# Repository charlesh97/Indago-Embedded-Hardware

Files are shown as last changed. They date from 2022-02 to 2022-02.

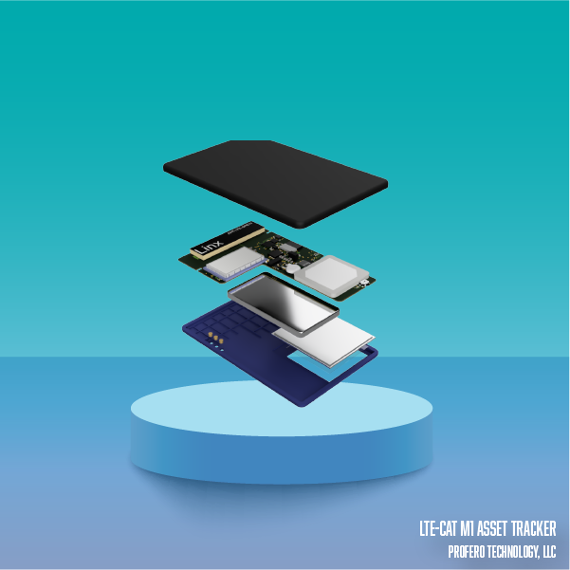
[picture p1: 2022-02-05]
Renderings/AssetTracker_TestProductMockup.png

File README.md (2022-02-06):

# Indago-Embedded-HW

Archived project.

See latest
[PCB](https://gitlab.com/indago-smart-tracker/indago-embedded-hw/-/blob/main/Hardware/v5_Miniature/Main%20Design%20B/Tracker_v5BPCB.pdf),
[Schematic](https://gitlab.com/indago-smart-tracker/indago-embedded-hw/-/blob/main/Hardware/v5_Miniature/Main%20Design%20B/Tracker_v5BSCH.pdf),
[Staged Product Rendering](https://gitlab.com/indago-smart-tracker/indago-embedded-hw/-/blob/main/Renderings/AssetTracker_TestProductMockup.png)

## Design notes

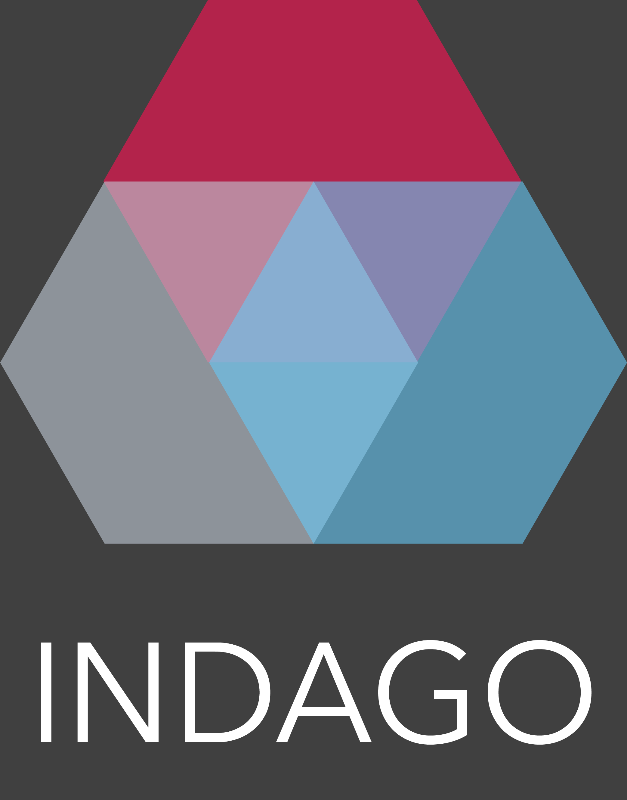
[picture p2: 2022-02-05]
Renderings/Indago_white.png

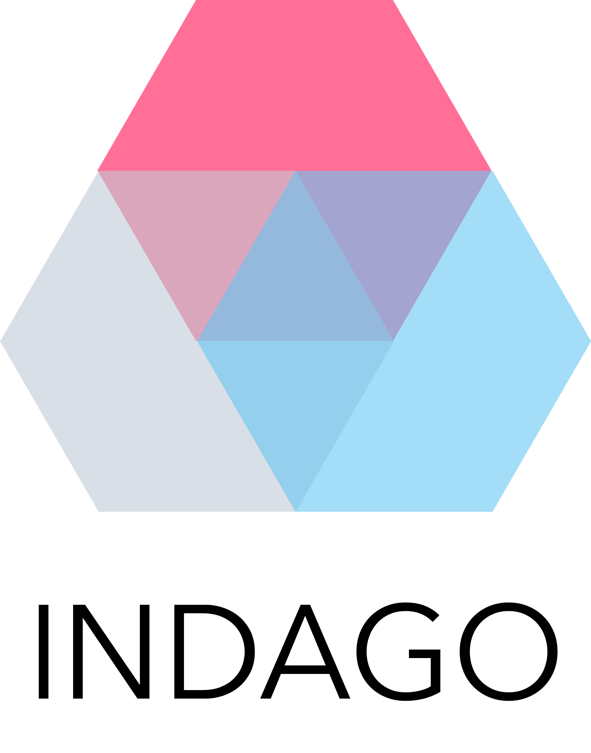
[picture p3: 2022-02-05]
Renderings/Indago.png

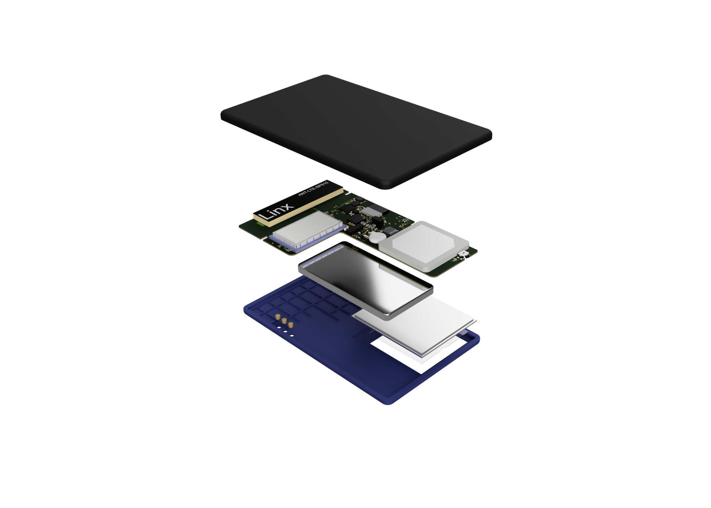
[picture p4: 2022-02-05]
Renderings/Mockup_v1_2020-Nov-24_12-03-38AM-000_CustomizedView8558925261_png_alpha.png

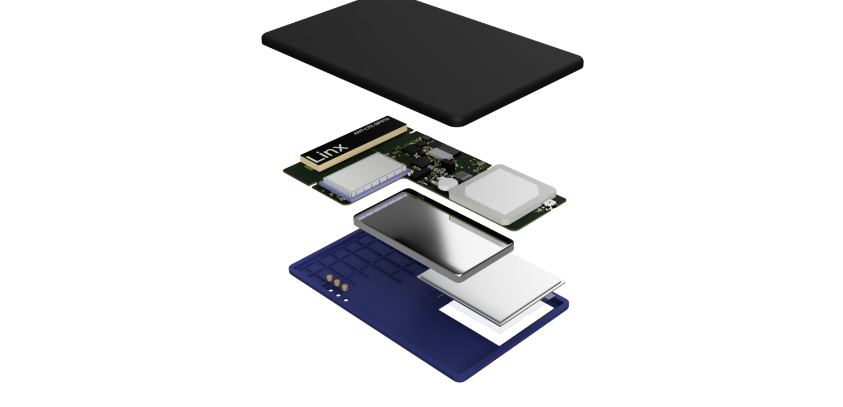
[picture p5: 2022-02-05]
Renderings/Mockup_v1_2020-Jun-15_01-10-26AM-000_CustomizedView8558925261_png_alpha.png

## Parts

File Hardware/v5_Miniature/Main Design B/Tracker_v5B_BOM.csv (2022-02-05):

Qty | Value | Device | Package | Parts | Description | ALTERNATE_PARTNUMBER | APPLICATION_BUILDNUMBER | BOI | BOI-METRIC | BUILT_BY | CATEGORY | COMPTYPE | COPYRIGHT | CREATED_BY | DESCRIPTION | DESIG | DIGI# | DIGI-KEY_PART_NUMBER | DIGI-KEY_PURCHASE_URL | DIGIKEY_PART_NUMBER | FAB | ISP_PART | MANF# | MANUFACTURER | MANUFACTURER_PART_NUMBER | MF | MOUNTTYPE | MP | MPN | OPERATING_TEMP | PACKAGE | PACKAGEREFERENCE | PARTNUMBER | PART_STATUS | PIN_COUNT | POPULARITY | REF | REFDES | ROHS | ROHS_COMPLIANT | SERIES | SOURCELIBRARY | SPICEPREFIX | SUB-CATEGORY | THERMALLOSS | TP_SIGNAL_NAME | TYPE | URL | VALUE | VENDOR | VOLTAGE_RATING
12 | 0.1uF | C-EUC0201 | C0201 | C2, C3, C9, C10, C11, C17, C22, C25, C26, C27, C32, C34 | CAPACITOR, European symbol |  |  |  |  |  |  |  |  |  |  |  |  |  |  |  |  |  |  |  |  |  |  |  |  |  |  |  |  |  |  | 0 |  |  |  |  |  |  | C
1 | 0.47uF | C-EUC0201 | C0201 | C1 | CAPACITOR, European symbol |  |  |  |  |  |  |  |  |  |  |  |  |  |  |  |  |  |  |  |  |  |  |  |  |  |  |  |  |  |  | 0 |  |  |  |  |  |  | C
1 | 0ohm | C-EUC0402 | C0402 | L2 | CAPACITOR, European symbol |  |  |  |  |  |  |  |  |  |  |  |  |  |  |  |  |  |  |  |  |  |  |  |  |  |  |  |  |  |  | 18 |  |  |  |  |  |  | C
1 | 1.8nF | C-EUC0402 | C0402 | C45 | CAPACITOR, European symbol |  |  |  |  |  |  |  |  |  |  |  |  |  |  |  |  |  |  |  |  |  |  |  |  |  |  |  |  |  |  | 18 |  |  |  |  |  |  | C
8 | 100 | R-US_R0201 | R0201 | R6, R7, R8, R9, R12, R13, R16, R17 | RESISTOR, American symbol |  |  |  |  |  |  |  |  |  |  |  |  |  |  |  |  |  |  |  |  |  |  |  |  |  |  |  |  |  |  | 0 |  |  |  |  |  |  | R
7 | 10000pF | C-EUC0201 | C0201 | C13, C21, C29, C30, C31, C33, C35 | CAPACITOR, European symbol |  |  |  |  |  |  |  |  |  |  |  |  |  |  |  |  |  |  |  |  |  |  |  |  |  |  |  |  |  |  | 0 |  |  |  |  |  |  | C
3 | 100k | R-US_R0201 | R0201 | R1, R31, R32 | RESISTOR, American symbol |  |  |  |  |  |  |  |  |  |  |  |  |  |  |  |  |  |  |  |  |  |  |  |  |  |  |  |  |  |  | 0 |  |  |  |  |  |  | R
1 | 100pF | C-EUC0201 | C0201 | C53 | CAPACITOR, European symbol |  |  |  |  |  |  |  |  |  |  |  |  |  |  |  |  |  |  |  |  |  |  |  |  |  |  |  |  |  |  | 0 |  |  |  |  |  |  | C
1 | 100pF | C-EUC0402 | C0402 | C44 | CAPACITOR, European symbol |  |  |  |  |  |  |  |  |  |  |  |  |  |  |  |  |  |  |  |  |  |  |  |  |  |  |  |  |  |  | 18 |  |  |  |  |  |  | C
3 | 10k | R-US_R0201 | R0201 | R2, R33, R37 | RESISTOR, American symbol |  |  |  |  |  |  |  |  |  |  |  |  |  |  |  |  |  |  |  |  |  |  |  |  |  |  |  |  |  |  | 0 |  |  |  |  |  |  | R
2 | 10nF | C-EUC0402 | C0402 | C48, C49 | CAPACITOR, European symbol |  |  |  |  |  |  |  |  |  |  |  |  |  |  |  |  |  |  |  |  |  |  |  |  |  |  |  |  |  |  | 18 |  |  |  |  |  |  | C
2 | 10pF | C-EUC0201 | C0201 | C38, C39 | CAPACITOR, European symbol |  |  |  |  |  |  |  |  |  |  |  |  |  |  |  |  |  |  |  |  |  |  |  |  |  |  |  |  |  |  | 0 |  |  |  |  |  |  | C
1 | 10uF | C-EUC0402 | C0402 | C7 | CAPACITOR, European symbol |  |  |  |  |  |  |  |  |  |  |  |  |  |  |  |  |  |  |  |  |  |  |  |  |  |  |  |  |  |  | 18 |  |  |  |  |  |  | C
1 | 10uF | C-EUC0603 | C0603 | C23 | CAPACITOR, European symbol |  |  |  |  |  |  |  |  |  |  |  |  |  |  |  |  |  |  |  |  |  |  |  |  |  |  |  |  |  |  | 73 |  |  |  |  |  |  | C
2 | 130 | R-US_R0201 | R0201 | R24, R28 | RESISTOR, American symbol |  |  |  |  |  |  |  |  |  |  |  |  |  |  |  |  |  |  |  |  |  |  |  |  |  |  |  |  |  |  | 0 |  |  |  |  |  |  | R
3 | 15pF | C-EUC0201 | C0201 | C19, C36, C37 | CAPACITOR, European symbol |  |  |  |  |  |  |  |  |  |  |  |  |  |  |  |  |  |  |  |  |  |  |  |  |  |  |  |  |  |  | 0 |  |  |  |  |  |  | C
1 | 196ohm | R-US_R0201 | R0201 | R34 | RESISTOR, American symbol |  |  |  |  |  |  |  |  |  |  |  |  |  |  |  |  |  |  |  |  |  |  |  |  |  |  |  |  |  |  | 0 |  |  |  |  |  |  | R
1 | 1k | R-US_R0201 | R0201 | R5 | RESISTOR, American symbol |  |  |  |  |  |  |  |  |  |  |  |  |  |  |  |  |  |  |  |  |  |  |  |  |  |  |  |  |  |  | 0 |  |  |  |  |  |  | R
8 | 1uF | C-EUC0201 | C0201 | C4, C5, C6, C12, C28, C40, C41, C57 | CAPACITOR, European symbol |  |  |  |  |  |  |  |  |  |  |  |  |  |  |  |  |  |  |  |  |  |  |  |  |  |  |  |  |  |  | 0 |  |  |  |  |  |  | C
2 | 2.2uF | C-EUC0402 | C0402 | C55, C56 | CAPACITOR, European symbol |  |  |  |  |  |  |  |  |  |  |  |  |  |  |  |  |  |  |  |  |  |  |  |  |  |  |  |  |  |  | 18 |  |  |  |  |  |  | C
1 | 2.4k | R-US_R0201 | R0201 | R38 | RESISTOR, American symbol |  |  |  |  |  |  |  |  |  |  |  |  |  |  |  |  |  |  |  |  |  |  |  |  |  |  |  |  |  |  | 0 |  |  |  |  |  |  | R
1 | 20k | R-US_R0201 | R0201 | R35 | RESISTOR, American symbol |  |  |  |  |  |  |  |  |  |  |  |  |  |  |  |  |  |  |  |  |  |  |  |  |  |  |  |  |  |  | 0 |  |  |  |  |  |  | R
2 | 22nF | C-EUC0402 | C0402 | C46, C54 | CAPACITOR, European symbol |  |  |  |  |  |  |  |  |  |  |  |  |  |  |  |  |  |  |  |  |  |  |  |  |  |  |  |  |  |  | 18 |  |  |  |  |  |  | C
4 | 29 | R-US_R0201 | R0201 | R18, R19, R22, R23 | RESISTOR, American symbol |  |  |  |  |  |  |  |  |  |  |  |  |  |  |  |  |  |  |  |  |  |  |  |  |  |  |  |  |  |  | 0 |  |  |  |  |  |  | R
1 | 2k | R-US_R0201 | R0201 | R3 | RESISTOR, American symbol |  |  |  |  |  |  |  |  |  |  |  |  |  |  |  |  |  |  |  |  |  |  |  |  |  |  |  |  |  |  | 0 |  |  |  |  |  |  | R
4 | 30 | R-US_R0201 | R0201 | R25, R26, R29, R30 | RESISTOR, American symbol |  |  |  |  |  |  |  |  |  |  |  |  |  |  |  |  |  |  |  |  |  |  |  |  |  |  |  |  |  |  | 0 |  |  |  |  |  |  | R
1 | 330 | R-US_R0201 | R0201 | R4 | RESISTOR, American symbol |  |  |  |  |  |  |  |  |  |  |  |  |  |  |  |  |  |  |  |  |  |  |  |  |  |  |  |  |  |  | 0 |  |  |  |  |  |  | R
2 | 4.7k | R-US_R0201 | R0201 | R14, R15 | RESISTOR, American symbol |  |  |  |  |  |  |  |  |  |  |  |  |  |  |  |  |  |  |  |  |  |  |  |  |  |  |  |  |  |  | 0 |  |  |  |  |  |  | R
2 | 470nF | C-EUC0402 | C0402 | C47, C50 | CAPACITOR, European symbol |  |  |  |  |  |  |  |  |  |  |  |  |  |  |  |  |  |  |  |  |  |  |  |  |  |  |  |  |  |  | 18 |  |  |  |  |  |  | C
1 | 47nF | C-EUC0402 | C0402 | C43 | CAPACITOR, European symbol |  |  |  |  |  |  |  |  |  |  |  |  |  |  |  |  |  |  |  |  |  |  |  |  |  |  |  |  |  |  | 18 |  |  |  |  |  |  | C
4 | 47pF | C-EUC0201 | C0201 | C14, C15, C16, C18 | CAPACITOR, European symbol |  |  |  |  |  |  |  |  |  |  |  |  |  |  |  |  |  |  |  |  |  |  |  |  |  |  |  |  |  |  | 0 |  |  |  |  |  |  | C
2 | 5M | R-US_R0201 | R0201 | R27, R39 | RESISTOR, American symbol |  |  |  |  |  |  |  |  |  |  |  |  |  |  |  |  |  |  |  |  |  |  |  |  |  |  |  |  |  |  | 0 |  |  |  |  |  |  | R
2 | 68nF | C-EUC0402 | C0402 | C8, C42 | CAPACITOR, European symbol |  |  |  |  |  |  |  |  |  |  |  |  |  |  |  |  |  |  |  |  |  |  |  |  |  |  |  |  |  |  | 18 |  |  |  |  |  |  | C
1 | 68pF | C-EUC0201 | C0201 | C20 | CAPACITOR, European symbol |  |  |  |  |  |  |  |  |  |  |  |  |  |  |  |  |  |  |  |  |  |  |  |  |  |  |  |  |  |  | 0 |  |  |  |  |  |  | C
1 | 845ohm | R-US_R0201 | R0201 | R36 | RESISTOR, American symbol |  |  |  |  |  |  |  |  |  |  |  |  |  |  |  |  |  |  |  |  |  |  |  |  |  |  |  |  |  |  | 0 |  |  |  |  |  |  | R
1 | ADP165ACBZ-1.8-R7 | ADP160ACBZ-3.3-R7 | CB_4_1 | U16 | ADP160ACBZ- Linear Voltage Regulator IC Positive Fixed 1 Output 150mA 4-WLCSP (0.97x0.97) |  |  |  |  |  |  |  |  |  |  |  | ADP160ACBZ-3.3-R7CT-ND |  |  |  |  |  | ADP160ACBZ-3.3-R7 |  |  |  |  |  |  |  |  |  |  |  |  |  |  |  |  |  |  |  |  |  |  |  |  | https://www.digikey.com/short/p17qrf
1 | ADP165ACBZ-3.3-R7 | ADP160ACBZ-3.3-R7 | CB_4_1 | U5 | ADP160ACBZ- Linear Voltage Regulator IC Positive Fixed 1 Output 150mA 4-WLCSP (0.97x0.97) |  |  |  |  |  |  |  |  |  |  |  | ADP160ACBZ-3.3-R7CT-ND |  |  |  |  |  | ADP160ACBZ-3.3-R7 |  |  |  |  |  |  |  |  |  |  |  |  |  |  |  |  |  |  |  |  |  |  |  |  | https://www.digikey.com/short/p17qrf
1 | ANT-LTE-SP610-T | ANT-LTE-SP610-T | ANT-LTE-SP610-T | U$1 | 700MHz, 850MHz, 900MHz, 1.8GHz, 1.9GHz, 2.1GHz, 2.4GHz, 2.6GHz CAT-M1, Cellular, GSM, LTE, LTE-M, LPWA, NB-IOT, UMTS, 4G Chip RF Antenna 698MHz ~ 960MHz, 1.71GHz ~ 2.17GHz, 2.3GHz ~ 2.4GHz, 2.49GHz ~ 2.69GHz 5.1dBi, 5.3dBi, 4.9dBi, 2.7dBi Solder Surface Mount |  |  |  |  |  |  |  |  |  |  |  |  |  |  |  |  |  |  |  |  |  |  |  |  |  |  |  |  |  |  |  |  |  |  |  |  |  |  |  |  |  |  |  | ANT-LTE-SP610-T
1 | AT25QL128A-UUE-T | AT25QL128A-UUE-T | 21-WLCSP | U13 | FLASH Memory IC 128Mb (16M x 8) SPI - Quad I/O, QPI 104MHz 21-WLCSP (3.02x3.29) |  |  |  |  |  |  |  |  |  |  |  |  |  |  |  |  |  |  |  |  |  |  |  |  |  |  |  |  |  |  |  |  |  |  |  |  |  |  |  |  |  |  |  | AT25QL128A-UUE-T
1 | BAT30F4 | BAT30F4 | BAT30F4 | D1 | Diode Schottky 30V 300mA Surface Mount 0201 |  |  |  |  |  |  |  |  |  |  |  |  |  |  |  |  |  |  |  |  |  |  |  |  |  |  |  |  |  |  |  |  |  |  |  |  |  |  |  |  |  |  |  | BAT30F4
1 | BQ29700DSER | BQ297XXDSER | DSE0006A | U3 | BQ297xx Cost-Effective Voltage and Current Protection Integrated Circuit for Single-Cell Li-Ion and Li-Polymer Batteries | TPS72710DSET | * |  |  |  |  | IC |  |  |  |  |  |  |  |  |  |  |  | Texas Instruments |  |  | SMT |  |  |  |  | DSE0006A | TPS72710DSER |  | 6 |  |  | RefDes | Y |  |  |  |  |  |  |  | TYPE |  | BQ29700DSER
1 | BQ51050BDSBGA | BQ51050BDSBGA | YFP28 | U14 | BQ51050B - Wireless Power Receiver.
2 | CLMVC-FKA | CLMVC-FKA | CLMVC-FKA | D2, D6 | Red, Green, Blue (RGB) 622nm Red, 530nm Green, 470nm Blue LED Indication - Discrete 2V Red, 3V Green, 3V Blue 4-SMD, J-Lead
2 | CSD13385F5T | CSD13385F5T | YJK3 | Q1, Q2 | N-Channel 12V 4.3A (Ta) 500mW (Ta) Surface Mount 3-PICOSTAR |  |  |  |  |  |  |  | Copyright (C) 2018 Accelerated Designs. All rights reserved |  |  |  |  |  |  |  |  |  |  |  | CSD13385F5T |  |  |  |  |  |  |  |  |  |  |  |  |  |  |  |  | TI_2019-05-21 |  |  |  |  |  |  |  | Texas Instruments
2 | ECS-.327-12.5-1210-TR | ECS-.327-12.5-1210-TR | ECS-.327-12.5-1210-TR | Y1, Y3 | CRYSTAL 32.7680KHZ 12.5PF SMD |  |  |  |  |  |  |  |  | PCBLayout.com |  |  |  |  |  | XC2282TR-ND |  |  |  | ECS Inc. |  |  |  |  | ECS-.327-12.5-1210-TR |  | 2-SMD
1 | ECS-160-9-37-CKM-TR | ECS-160-9-37-CKM-TR | XTAL_ECS-160-9-37-CKM-TR | Y4 | SMD Crystal 2.0 x 1.6 x 0.45 mm ceramic package |  |  |  |  |  |  |  |  |  | 16MHz ±10ppm Crystal 9pF 100 Ohms 4-SMD, No Lead |  |  | XC2630CT-ND | https://www.digikey.com/product-detail/en/ecs-inc/ECS-160-9-37-CKM-TR/XC2630CT-ND/8023565 |  |  |  |  |  |  | ECS Inc. |  | ECS-160-9-37-CKM-TR |  |  | SMD-4 ECS International
1 | EVQ-7PJ | EVQ-7P(J/A) | EVQ-7PJ/A | S1 | PANASONIC SWITCH TACTILE SPST-NO 0.05A 12V |  |  |  |  |  |  |  |  |  |  |  |  |  |  |  |  |  |  |  |  |  |  |  |  |  |  |  |  |  |  |  |  |  |  |  |  |  |  |  |  |  |  |  | EVQ-7PJ
1 | ISP1507ALISP1507AL_ISP1507-AL | ISP1507ALISP1507AL_ISP1507-AL | ISP1507-AL | U7 | ISP Smart Bluetooth Module |  |  | QFN 8 x 8 | QFN 8 x 8 |  |  |  |  |  |  | BLE Module |  |  |  |  | Insight SiP | ISP1507AL |  |  |  |  |  |  |  |  |  |  |  |  |  |  | ISP1507AL
1 | LSM6DSMTR | LSM6DSMTR | PQFN50P300X250X86-14N | U10 | iNEMO inertial module: 3D accelerometer and 3D gyroscope |  |  |  |  |  |  |  |  |  | Accelerometer, Gyroscope, Temperature, 6 Axis Sensor I²C, SPI Output |  |  | 497-16696-1-ND | https://www.digikey.com/product-detail/en/stmicroelectronics/LSM6DSMTR/497-16696-1-ND/6192778 |  |  |  |  |  |  | STMicroelectronics |  | LSM6DSMTR |  |  | VFLGA-14 STMicroelectronics |  |  |  |  |  |  |  |  |  |  |  |  |  |  |  |  |  | LSM6DSMTR
1 | MAX17262REWL+T | MAX17262REWL+T | 21-100221A_W91G1+3 | U2 | 5.2μA 1-Cell Fuel Gauge with ModelGauge m5 EZ and Internal Current Sensing |  |  |  |  | EMA_Jessica |  |  | Copyright (C) 2016 Accelerated Designs. All rights reserved |  |  |  |  |  |  |  |  |  |  |  | MAX17262REWL+T |  |  |  |  |  |  |  |  |  |  |  |  |  |  |  |  | Maxim_2018-11-30 |  |  |  |  |  |  | MAX17262REWL+T | Maxim Integrated Products
1 | ML614-TZ21 | ML614-TZ21 | ML614-TZ21 | Y2 | Coin, 6.8mm 3V Lithium Battery Rechargeable (Secondary) 3.4mAh
1 | MX25R1635FZUIL0 | MX25R1635FZUIL0 | USON-8L-2X3X0P6_MAC | U9 | FLASH - NOR Memory IC 16Mb (2M x 8) SPI - Quad I/O 33MHz 8-USON (2x3) |  |  |  |  | EMA_Cory |  |  | Copyright (C) 2018 Accelerated Designs. All rights reserved |  |  |  |  |  |  |  |  |  |  |  | MX25R1635FZUIL0 |  |  |  |  |  |  |  |  |  |  |  |  |  |  |  |  | Macronix_2019-12-02 |  |  |  |  |  |  |  | Macronix
1 | SARA-R4 | SARA-R4 | SARA-R4 | U11 | Ublox LTE-M / NB-IoT / EGPRS modules with Secure Cloud |  |  |  |  |  |  |  |  |  |  |  |  |  |  |  |  |  |  |  |  |  |  |  |  |  |  |  |  |  |  |  |  |  |  |  |  |  |  |  |  |  |  |  | SARA-R4
1 | SGGP.25.2.A.02 | SGGP.25.2.A.02 | SGGP.25.2.A.02 | ANT1 | 1.575GHz, 1.602GHz GLONASS, GPS Ceramic Patch RF Antenna 3.3dBi Solder Surface Mount |  |  |  |  |  |  |  |  |  |  |  |  |  |  |  |  |  |  |  |  |  |  |  |  |  |  |  |  |  |  |  |  |  |  |  |  |  |  |  |  |  |  |  | SGGP.25.2.A.02
1 | SIM-ST-MFF2 | SIM-ST-MFF2 | PSON127P500X600X82-9N | U12 | GLOBAL IOT EMBEDDED SIM CHIP |  |  |  |  |  |  |  |  |  | GLOBAL IOT EMBEDDED SIM CHIP |  |  | 1887-1002-1-ND | https://www.digikey.com/product-detail/en/hologram-inc/SIM-ST-MFF2/1887-1002-1-ND/9489900 |  |  |  |  |  |  | Hologram, Inc. |  | SIM-ST-MFF2 |  |  | None |  |  |  |  |  |  |  |  |  |  |  |  |  |  |  |  |  | SIM-ST-MFF2
2 | SMD_PADPAD_150X75 | SMD_PADPAD_150X75 | PAD_150X75 | J1, J3 | Square SMD Pad Collection
2 | SMD_PADPAD_4MMX5MM | SMD_PADPAD_4MMX5MM | PAD_4MMX5MM | J6, J7 | Square SMD Pad Collection
1 | STM32L412RBI6 | STM32L412RBI6 | BGA64C50P8X8_500X500X60N | U1 | ARM® Cortex®-M4 STM32L4 Microcontroller IC 32-Bit 80MHz 128KB (128K x 8) FLASH 64-UFBGA (5x5) |  |  |  |  |  |  |  |  |  |  |  |  |  |  |  |  |  |  |  | stm32l4_ufbga64_t5 |  |  |  |  |  |  |  |  |  |  |  |  |  |  |  |  |  |  |  |  |  |  |  |  | STMicroelectronics
1 | TAJB476M010TNJ | C-POL_TANTALUM-1411(3528-METRIC) | CAPMP3528X210N | C24 | Capacitor Polarised - Generic |  |  |  |  |  | Capacitor
2 | TPS22970YZPR | TPS22970YZPR | YZP0008ADCD | U4, U15 | TPS22970 3.6-V, 4-A, 4.7-mΩOn-Resistance Load Switch |  |  |  |  |  |  |  |  |  |  |  |  |  |  |  |  |  |  | Texas Instruments |  |  |  |  |  |  |  |  | TPS22970YZPR |  |  |  |  | RefDes |  |  |  |  |  |  |  |  | TYPE |  | TPS22970YZPR
25 | TPTP15R | TPTP15R | TP15R | TP1, TP2, TP3, TP4, TP5, TP6, TP7, TP8, TP9, TP10, TP11, TP12, TP13, TP14, TP17, TP18, TP19, TP20, TP21, TP22, TP23, TP24, TP25, TP26, TP27 | Test pad |  |  |  |  |  |  |  |  |  |  |  |  |  |  |  |  |  |  |  |  |  |  |  |  |  |  |  |  |  |  | 0
1 | ZOE-M8B | ZOE-M8B | ZOE-M8 | U8 | ZOE-M8 RF Receiver BeiDou, Galileo, GLONASS, GNSS, GPS -160dBm |  |  |  |  |  |  |  |  |  | ZOE-M8 RF Receiver BeiDou, Galileo, GLONASS, GNSS, GPS -160dBm |  |  |  |  |  |  |  |  |  |  | U-Blox America |  | ZOE-M8B |  |  | SMD-51 U-Blox America
2 | dnp | C-EUC0402 | C0402 | C51, C52 | CAPACITOR, European symbol |  |  |  |  |  |  |  |  |  |  |  |  |  |  |  |  |  |  |  |  |  |  |  |  |  |  |  |  |  |  | 18 |  |  |  |  |  |  | C
4 | dnp | R-US_R0201 | R0201 | R10, R11, R20, R21 | RESISTOR, American symbol |  |  |  |  |  |  |  |  |  |  |  |  |  |  |  |  |  |  |  |  |  |  |  |  |  |  |  |  |  |  | 0 |  |  |  |  |  |  | R

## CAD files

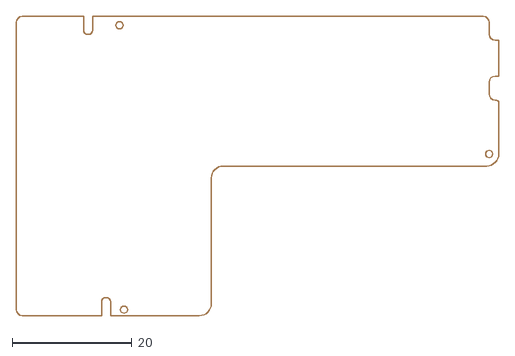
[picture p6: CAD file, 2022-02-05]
Hardware/v5_Miniature/Main Design B/Tracker_v5B.dxf
80.6 x 50.0

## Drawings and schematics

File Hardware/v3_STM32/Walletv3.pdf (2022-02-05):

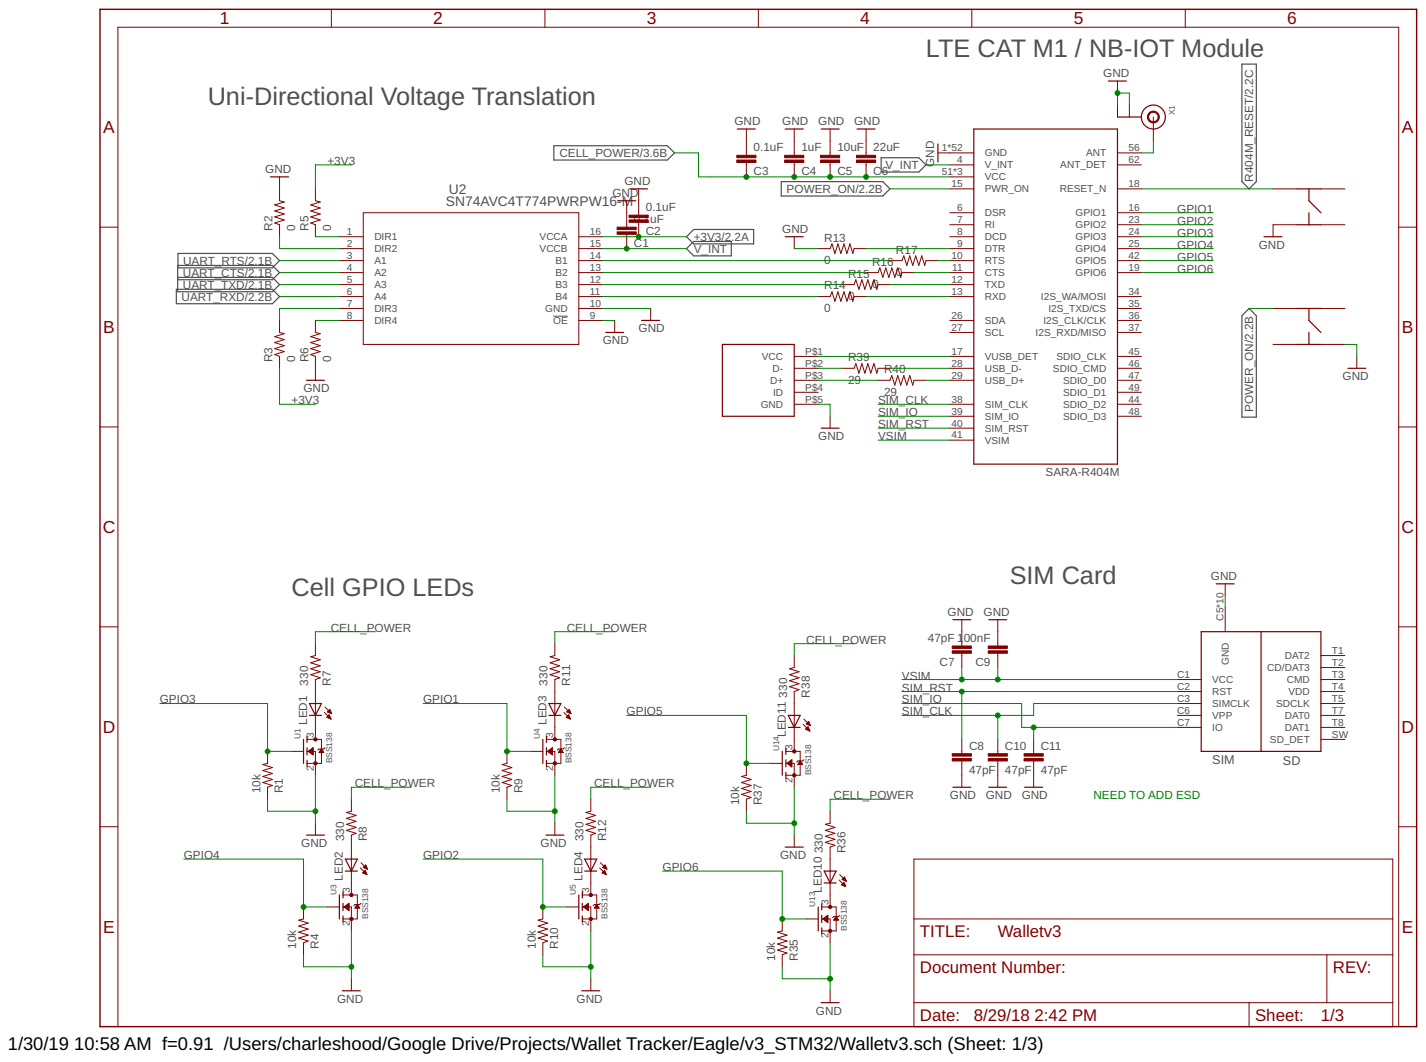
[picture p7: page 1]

LTE CAT M1 / NB-IOT Module

Uni-Directional Voltage Translation

NEED TO ADD ESD

Document Number: | REV:

Date: 8/29/18 2:42 PM | Sheet: 1/3

1/30/19 10:58 AM f=0.91 /Users/charleshood/Google Drive/Projects/Wallet Tracker/Eagle/v3_STM32/Walletv3.sch (Sheet: 1/3)

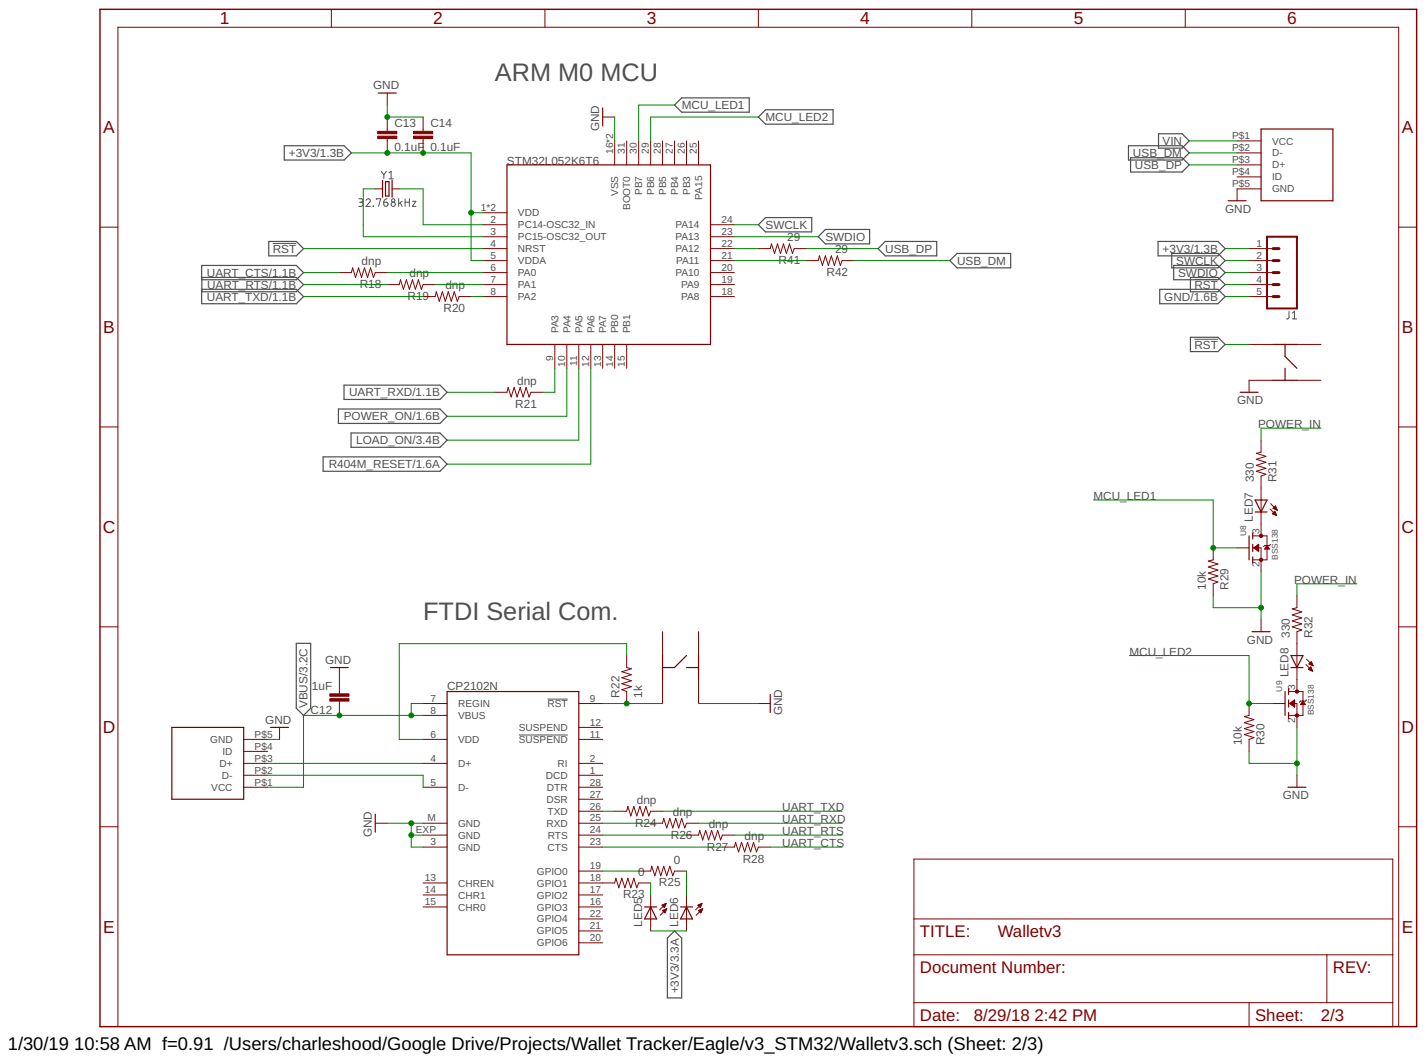
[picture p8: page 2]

P$4 GND | | 11 RI 2 DCD

1/30/19 10:58 AM f=0.91 /Users/charleshood/Google Drive/Projects/Wallet Tracker/Eagle/v3_STM32/Walletv3.sch (Sheet: 2/3)

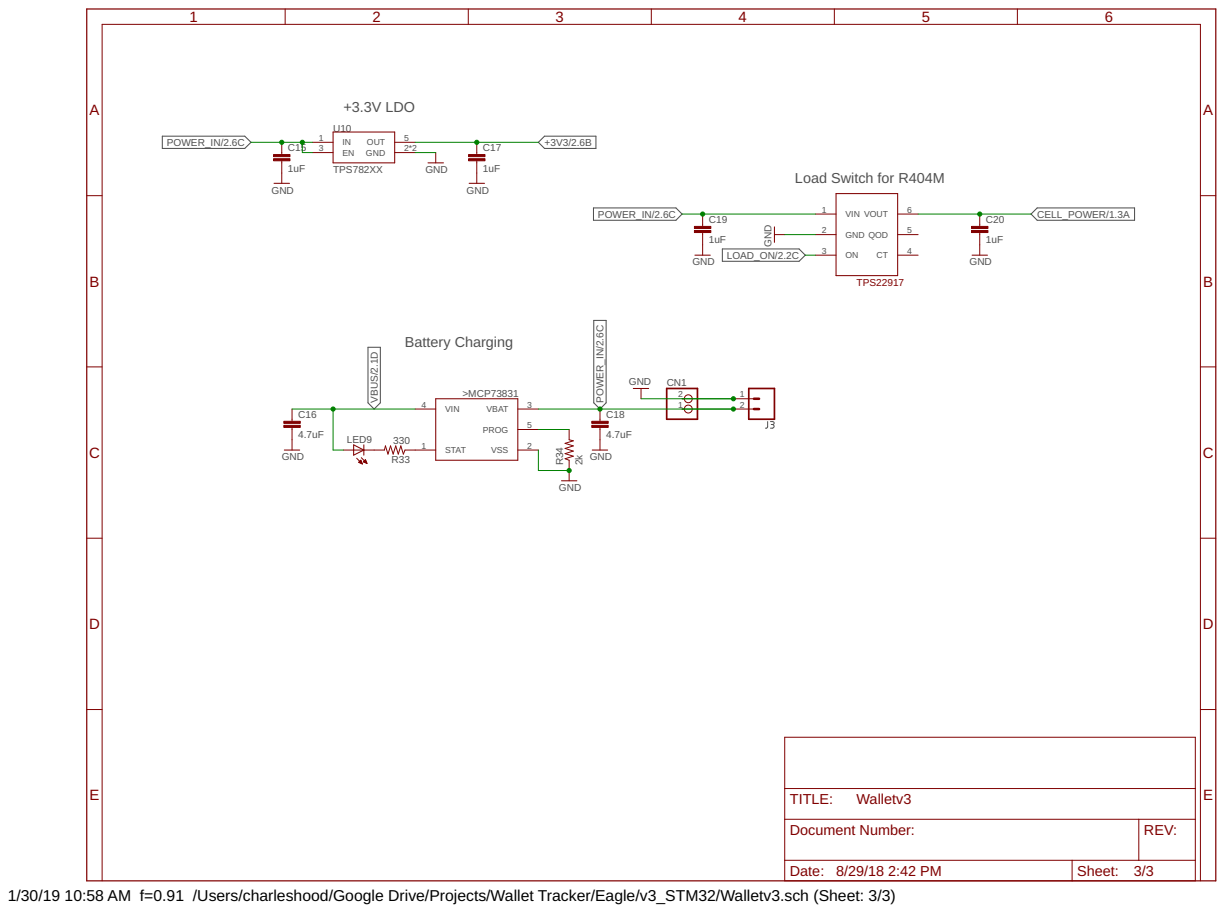
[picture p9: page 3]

1/30/19 10:58 AM f=0.91 /Users/charleshood/Google Drive/Projects/Wallet Tracker/Eagle/v3_STM32/Walletv3.sch (Sheet: 3/3)

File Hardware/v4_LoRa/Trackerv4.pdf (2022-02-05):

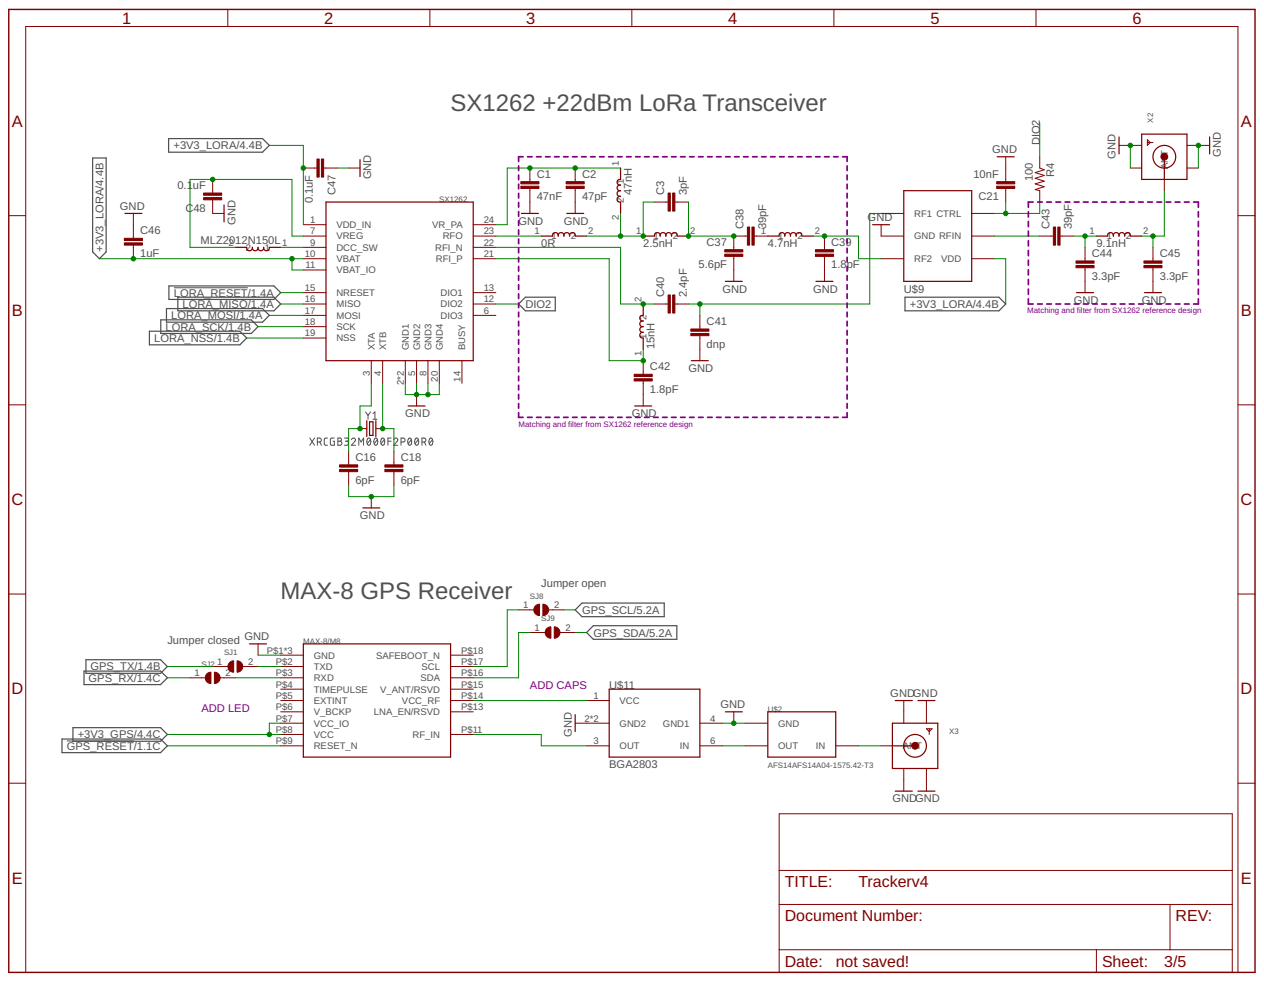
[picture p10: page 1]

SX1262 +22dBm LoRa Transceiver

Matching and filter from SX1262 reference design

Document Number: | REV:

Date: not saved! | Sheet: 3/5

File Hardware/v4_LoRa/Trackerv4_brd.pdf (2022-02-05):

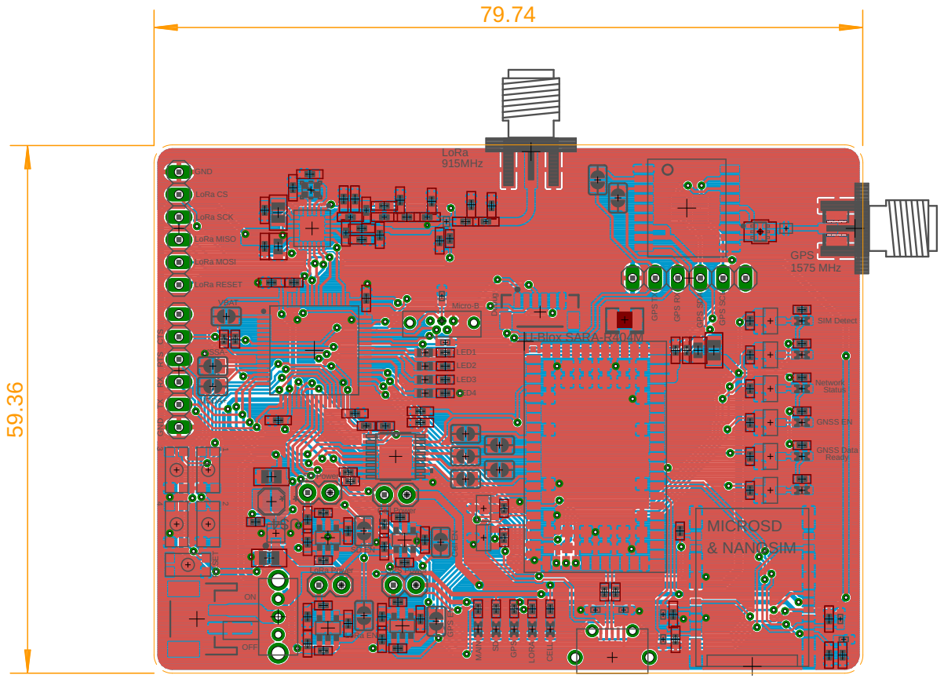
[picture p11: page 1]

GPS
1575 MHz
SIM Detect Network Status GNSS EN GNSS Data Ready

GPS TX GPS RX GPS SDA GPS SCL

LED2

SD EN ON OFF

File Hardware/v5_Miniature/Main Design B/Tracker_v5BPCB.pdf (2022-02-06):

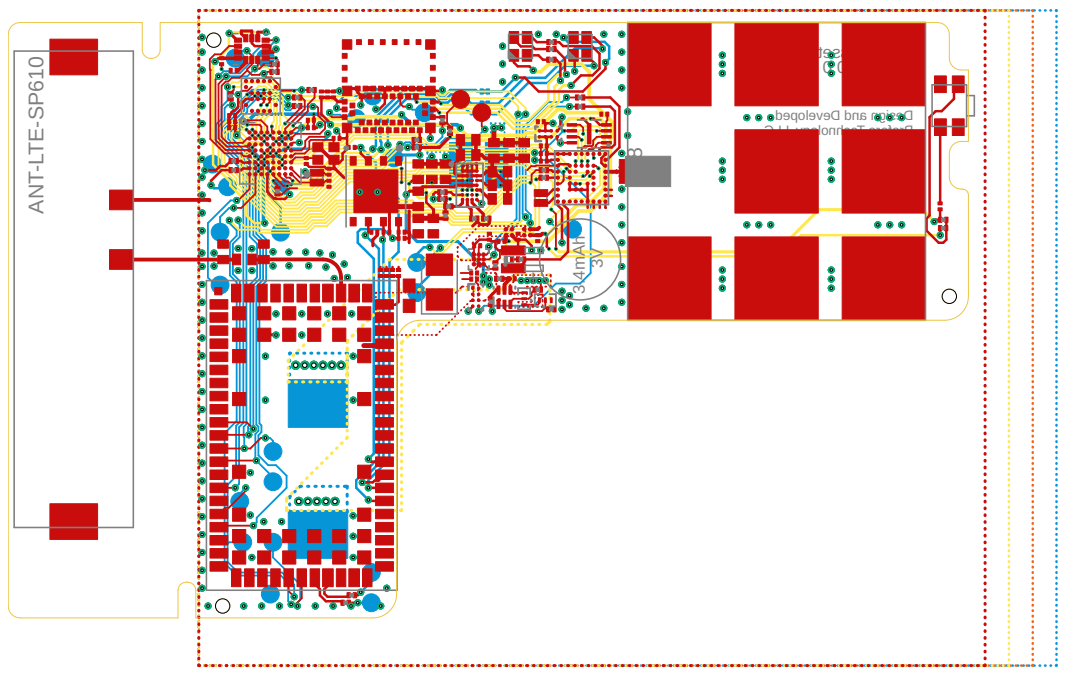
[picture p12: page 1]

r ekcar Tt ess Ar al ull e C 0. 0. 5 noi sr eV depol eve Ddna ngi se D CLL, ygol onhceT or ef or P U8 + 3V 3.4mAh ANT-LTE-SP610

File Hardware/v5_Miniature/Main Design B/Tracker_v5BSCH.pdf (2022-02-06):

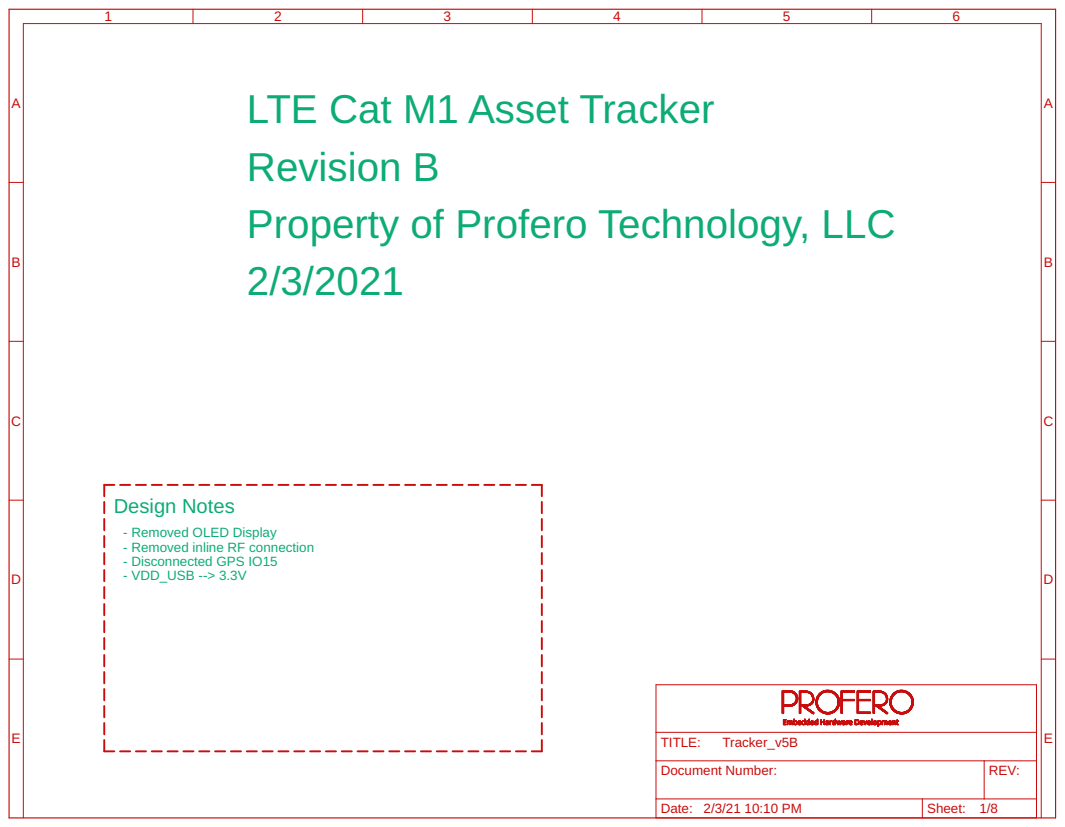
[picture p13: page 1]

LTE Cat M1 Asset Tracker
Revision B
Property of Profero Technology, LLC

- Removed OLED Display
- Removed inline RF connection
- Disconnected GPS IO15
- VDD_USB --> 3.3V

Document Number: | REV:

Date: 2/3/21 10:10 PM | Sheet: 1/8

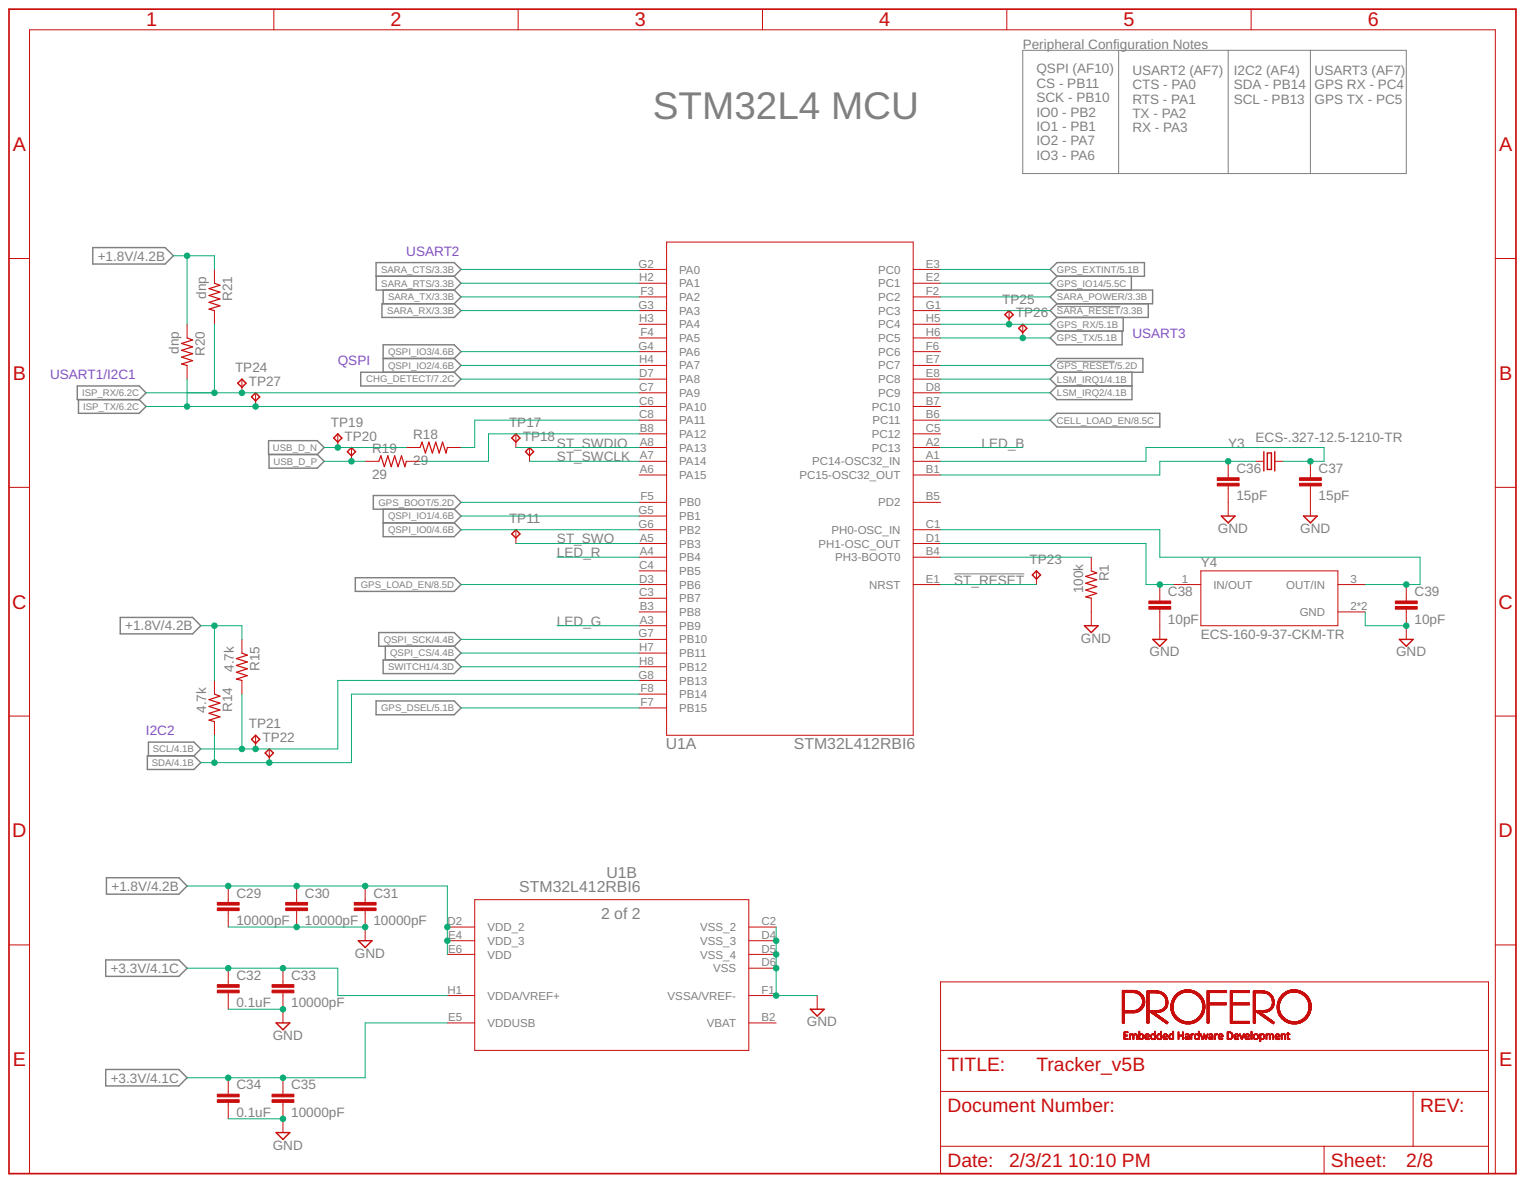
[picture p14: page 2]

Peripheral Configuration Notes STM32L4 MCU

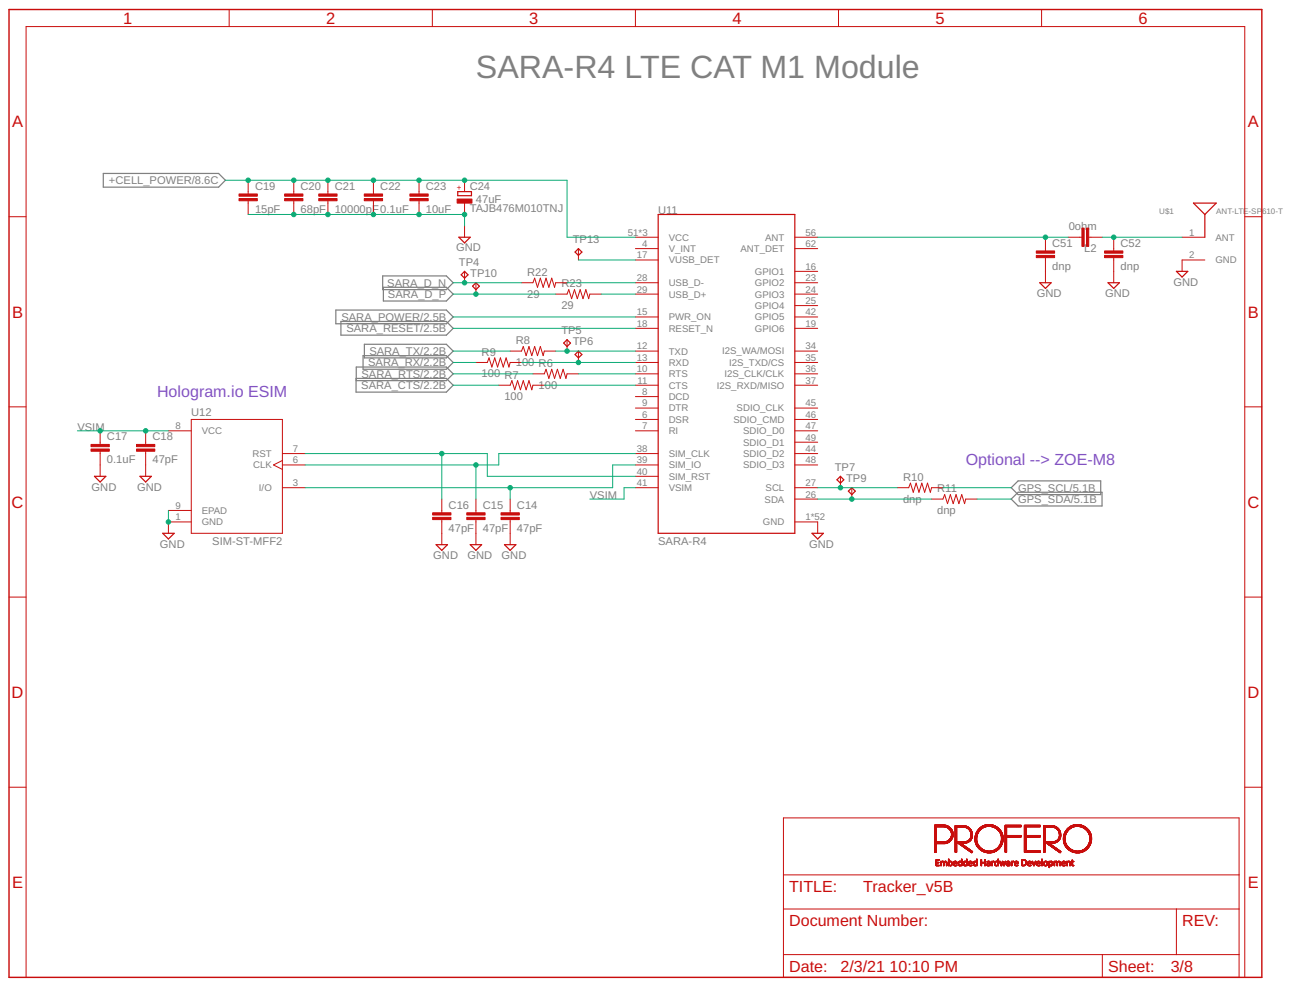
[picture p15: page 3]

SARA-R4 LTE CAT M1 Module

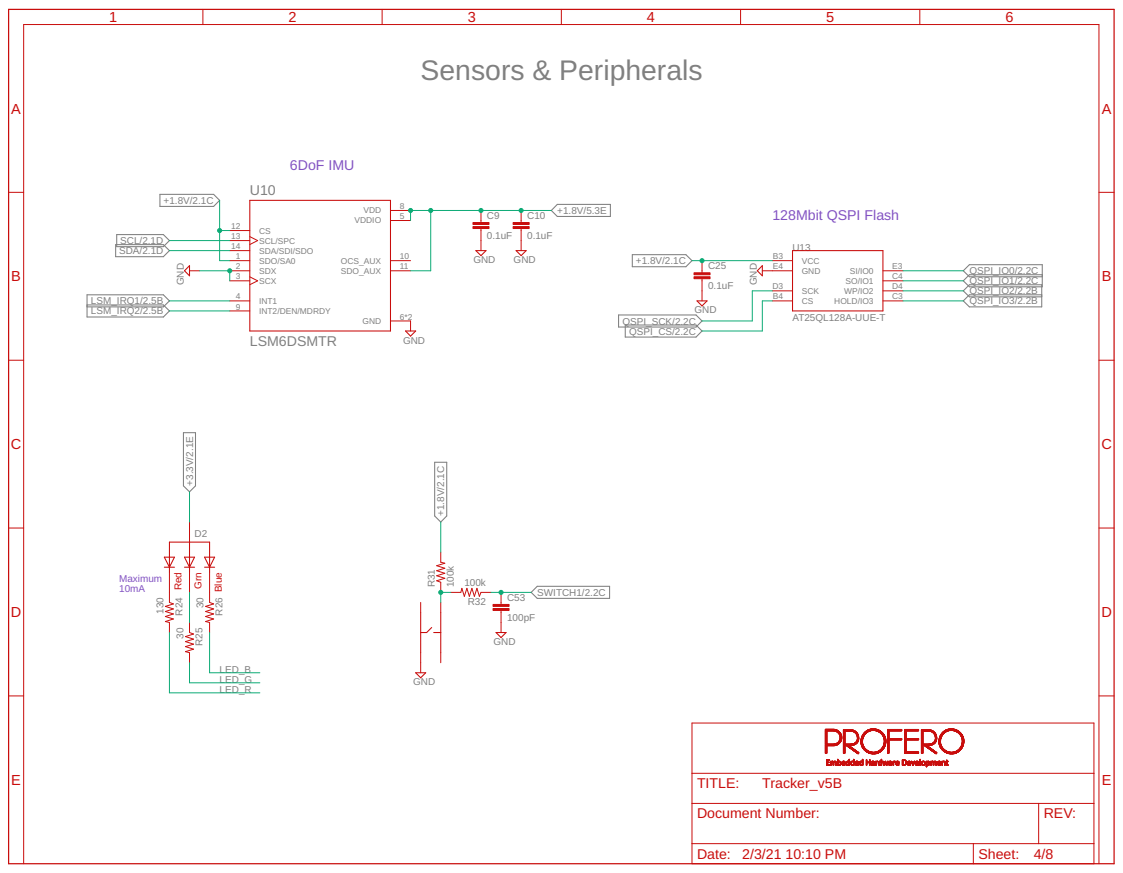
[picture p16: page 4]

Red Grn Blue 6DoF IMU

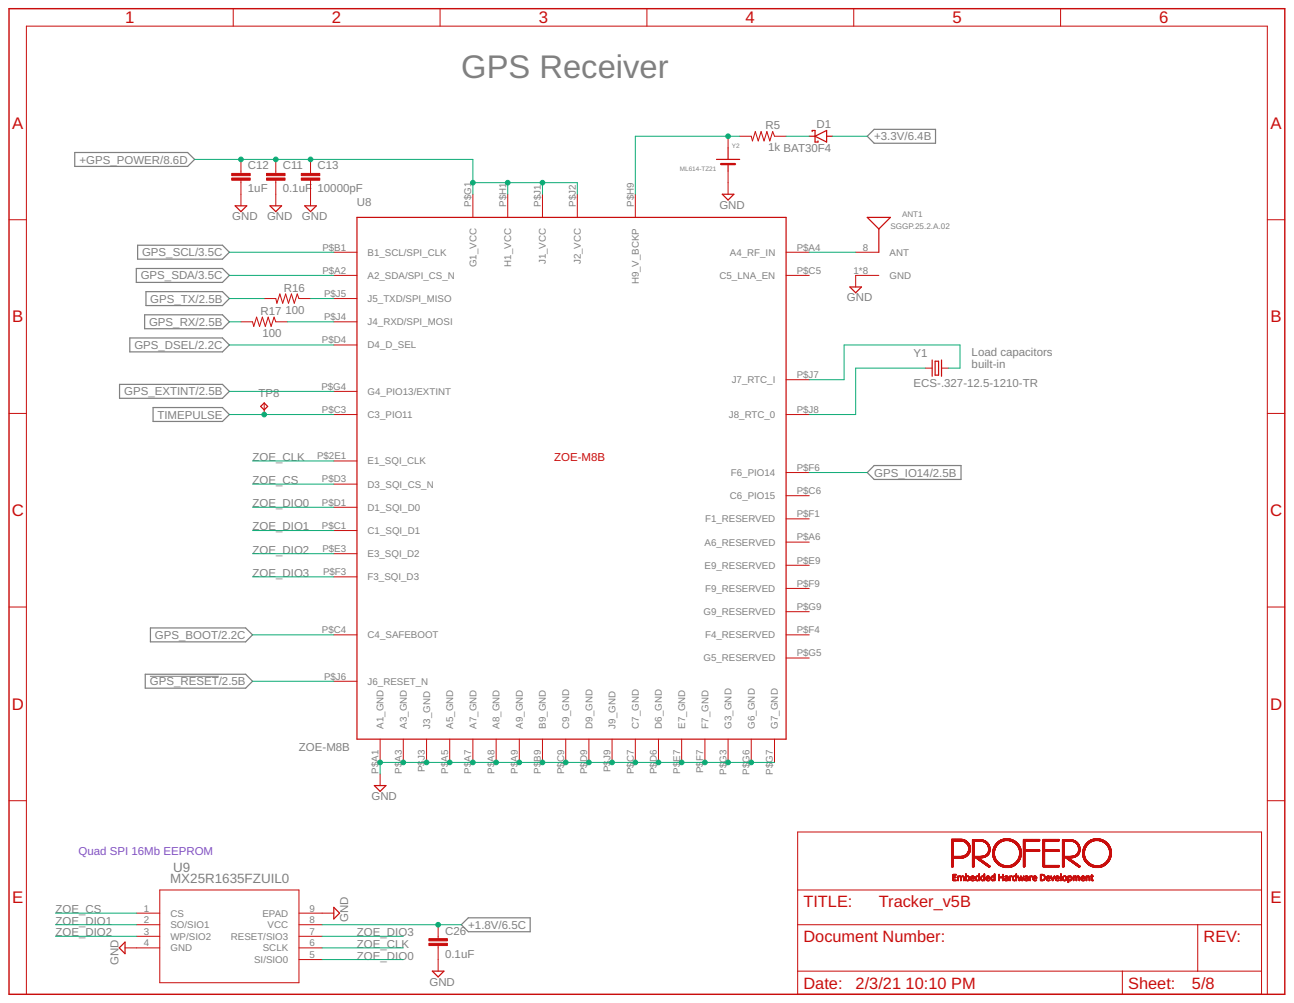
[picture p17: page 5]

Load capacitors built-in ECS-.327-12.5-1210-TR

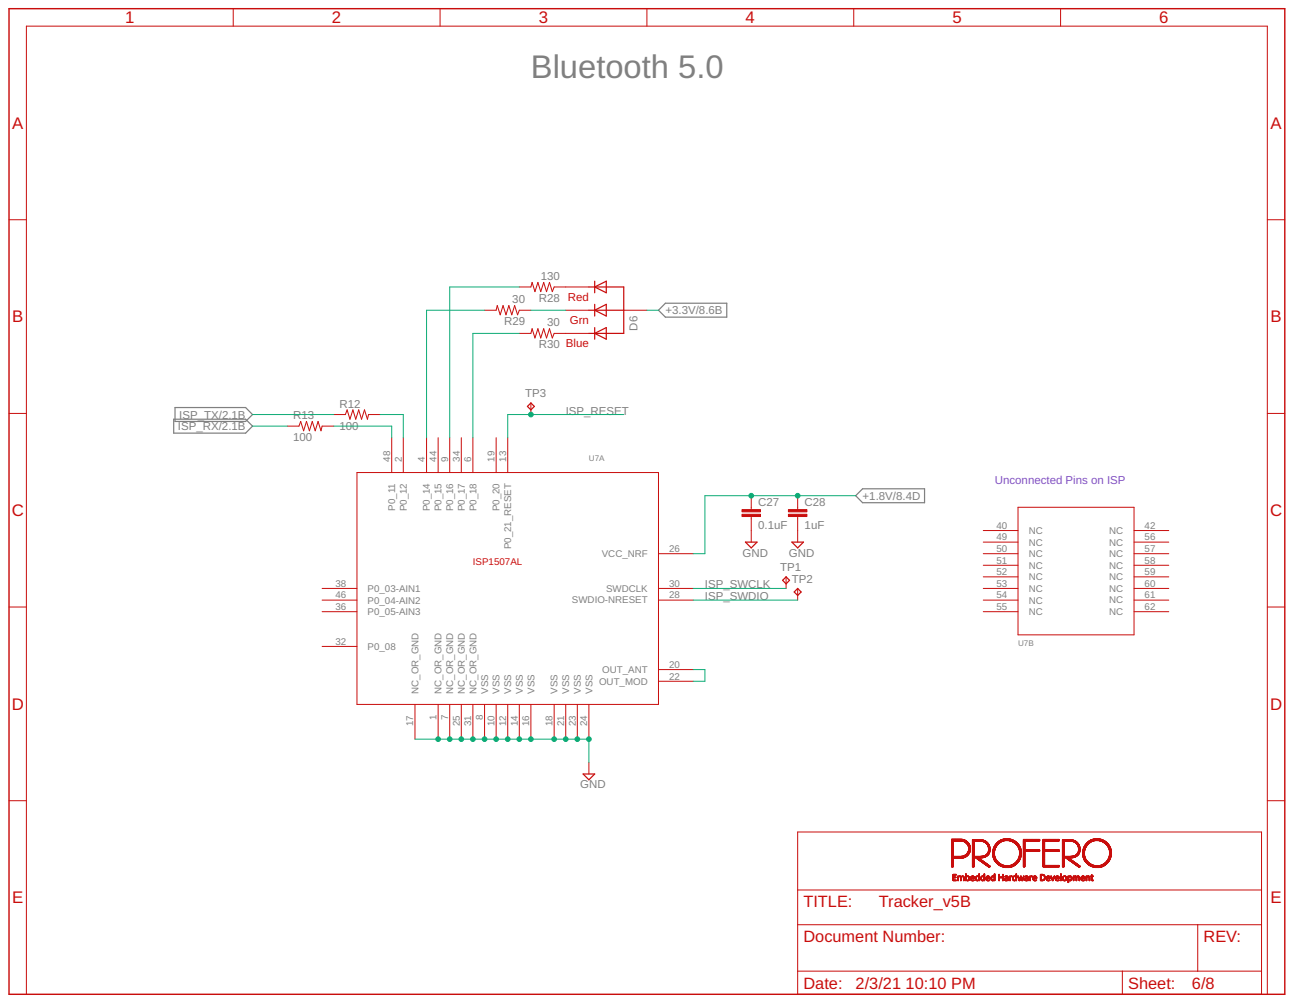
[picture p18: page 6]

Unconnected Pins on ISP


Qi Compliant Wireless Charger


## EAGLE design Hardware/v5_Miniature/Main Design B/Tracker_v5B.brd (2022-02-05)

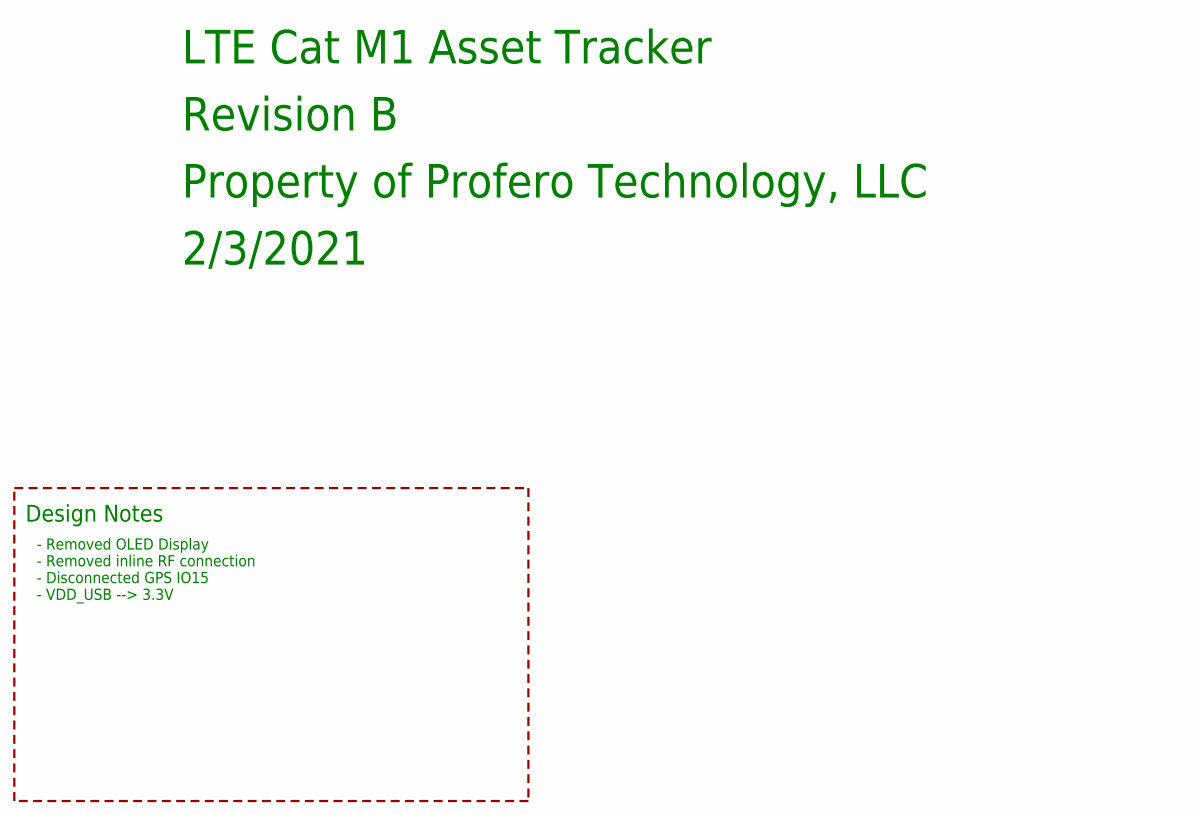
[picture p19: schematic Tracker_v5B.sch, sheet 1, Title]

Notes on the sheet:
LTE Cat M1 Asset Tracker
Revision B
Property of Profero Technology, LLC
2/3/2021
Design Notes
- Removed OLED Display - Removed inline RF connection - Disconnected GPS IO15 - VDD_USB --> 3.3V

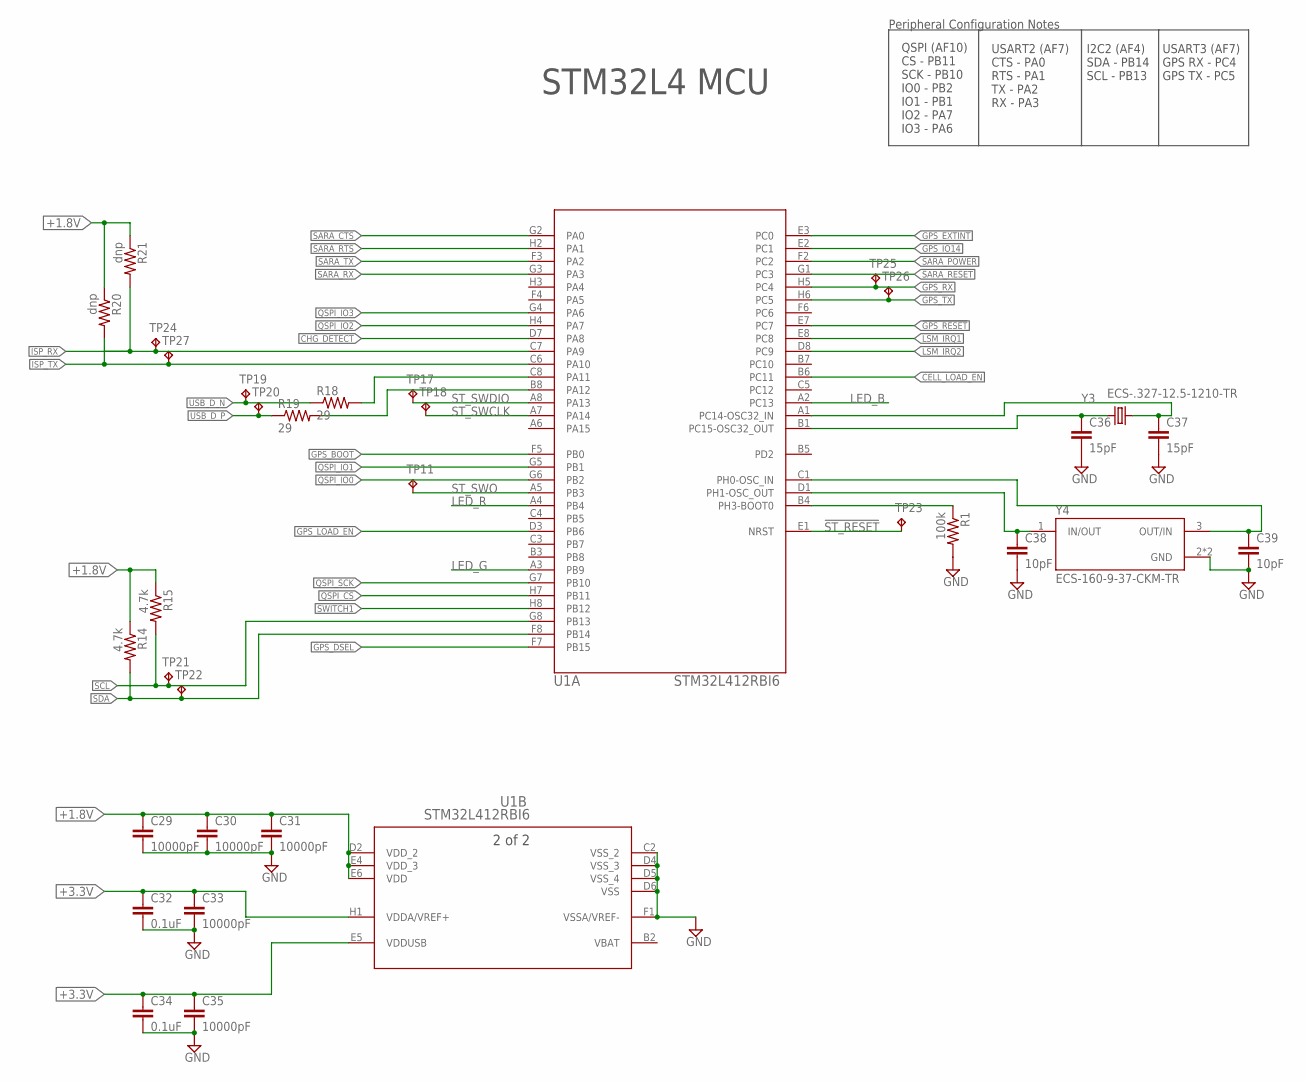
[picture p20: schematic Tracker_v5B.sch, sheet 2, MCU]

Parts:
C29, C30, C31, C33, C35: 10000pF; C0201
C32, C34: 0.1uF; C0201
C36, C37: 15pF; C0201
C38, C39: 10pF; C0201
R1: 100k; R0201
R14, R15: 4.7k; R0201
R18, R19: 29; R0201
R20, R21: dnp; R0201
TP11, TP17, TP18, TP19, TP20, TP21, TP22, TP23, TP24, TP25, TP26, TP27: TPTP15R; TP15R
U1: STM32L412RBI6; BGA64C50P8X8_500X500X60N
Y3: ECS-.327-12.5-1210-TR
Y4: ECS-160-9-37-CKM-TR; XTAL_ECS-160-9-37-CKM-TR

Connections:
!GPS_RESET: U1.E7 (PC7); also elsewhere on the board
!SARA_RESET: U1.G1 (PC3); also elsewhere on the board
!ST_RESET: TP23.TP, U1.E1 (NRST)
+1.8V: C29.1, C30.1, C31.1, R14.1, R15.1, R20.1, R21.1, U1.D2 (VDD_2), U1.E4 (VDD_3), U1.E6 (VDD); also elsewhere on the board
+3.3V: C32.1, C33.1, C34.1, C35.1, U1.E5 (VDDUSB), U1.H1 (VDDA/VREF+); also elsewhere on the board
CELL_LOAD_EN: U1.B6 (PC11); also elsewhere on the board
CHG_DETECT: U1.D7 (PA8); also elsewhere on the board
GND: C29.2, C30.2, C31.2, C32.2, C33.2, C34.2, C35.2, C36.2, C37.2, C38.2, C39.2, R1.2, U1.C2 (VSS_2), U1.D4 (VSS_3), U1.D5 (VSS_4), U1.D6 (VSS), U1.F1 (VSSA/VREF-), Y4.2 (GND), Y4.4 (GND); also elsewhere on the board
GPS_BOOT: U1.F5 (PB0); also elsewhere on the board
GPS_DSEL: U1.F7 (PB15); also elsewhere on the board
GPS_EXTINT: U1.E3 (PC0); also elsewhere on the board
GPS_IO14: U1.E2 (PC1); also elsewhere on the board
GPS_LOAD_EN: U1.D3 (PB6); also elsewhere on the board
GPS_RX: TP25.TP, U1.H5 (PC4); also elsewhere on the board
GPS_TX: TP26.TP, U1.H6 (PC5); also elsewhere on the board
ISP_RX: R21.2, TP24.TP, U1.C7 (PA9); also elsewhere on the board
ISP_TX: R20.2, TP27.TP, U1.C6 (PA10); also elsewhere on the board
LED_B: U1.A2 (PC13); also elsewhere on the board
LED_G: U1.A3 (PB9); also elsewhere on the board
LED_R: U1.A4 (PB4); also elsewhere on the board
LSM_IRQ1: U1.E8 (PC8); also elsewhere on the board
LSM_IRQ2: U1.D8 (PC9); also elsewhere on the board
unnamed: R18.2, U1.C8 (PA11)
unnamed: R19.2, U1.B8 (PA12)
unnamed: C36.1, U1.B1 (PC15-OSC32_OUT), Y3.1
unnamed: C37.1, U1.A1 (PC14-OSC32_IN), Y3.2
unnamed: C39.1, U1.C1 (PH0-OSC_IN), Y4.3 (OUT/IN)
unnamed: C38.1, U1.D1 (PH1-OSC_OUT), Y4.1 (IN/OUT)
unnamed: R1.1, U1.B4 (PH3-BOOT0)
QSPI_CS: U1.H7 (PB11); also elsewhere on the board
QSPI_IO0: U1.G6 (PB2); also elsewhere on the board
QSPI_IO1: U1.G5 (PB1); also elsewhere on the board
QSPI_IO2: U1.H4 (PA7); also elsewhere on the board
QSPI_IO3: U1.G4 (PA6); also elsewhere on the board
QSPI_SCK: U1.G7 (PB10); also elsewhere on the board
SARA_CTS: U1.G2 (PA0); also elsewhere on the board
SARA_POWER: U1.F2 (PC2); also elsewhere on the board
SARA_RTS: U1.H2 (PA1); also elsewhere on the board
SARA_RX: U1.G3 (PA3); also elsewhere on the board
SARA_TX: U1.F3 (PA2); also elsewhere on the board
SCL: R15.2, TP21.TP, U1.G8 (PB13); also elsewhere on the board
SDA: R14.2, TP22.TP, U1.F8 (PB14); also elsewhere on the board
ST_SWCLK: TP18.TP, U1.A7 (PA14)
ST_SWDIO: TP17.TP, U1.A8 (PA13)
ST_SWO: TP11.TP, U1.A5 (PB3)
SWITCH1: U1.H8 (PB12); also elsewhere on the board
USB_D_N: R18.1, TP19.TP
USB_D_P: R19.1, TP20.TP
VBAT: U1.B2 (VBAT)

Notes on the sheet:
Peripheral Configuration Notes
STM32L4 MCU
I2C2 (AF4) SDA - PB14 SCL - PB13
QSPI (AF10) CS - PB11 SCK - PB10 IO0 - PB2 IO1 - PB1 IO2 - PA7 IO3 - PA6
USART2 (AF7) CTS - PA0 RTS - PA1 TX - PA2 RX - PA3
USART3 (AF7) GPS RX - PC4 GPS TX - PC5

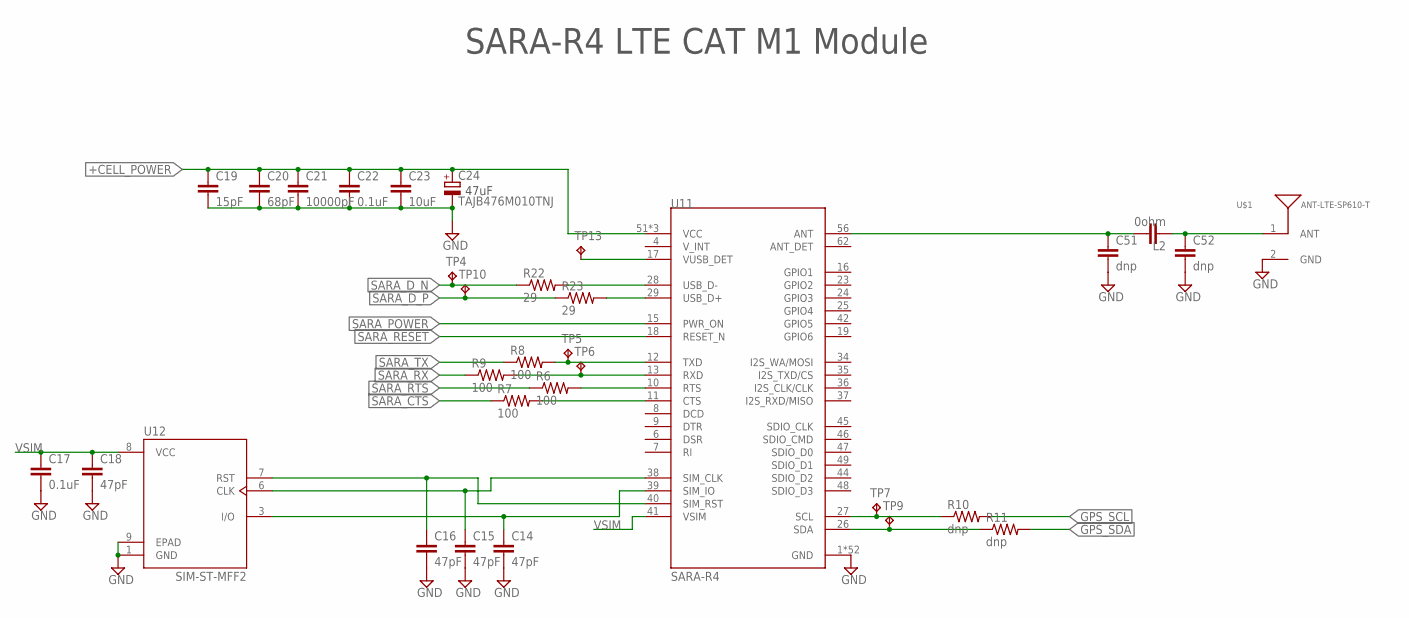
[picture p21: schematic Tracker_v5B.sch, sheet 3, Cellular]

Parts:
C14, C15, C16, C18: 47pF; C0201
C17, C22: 0.1uF; C0201
C19: 15pF; C0201
C20: 68pF; C0201
C21: 10000pF; C0201
C23: 10uF; C0603
C24: TAJB476M010TNJ; CAPMP3528X210N
C51, C52: dnp; C0402
L2: 0ohm; C0402
R6, R7, R8, R9: 100; R0201
R10, R11: dnp; R0201
R22, R23: 29; R0201
TP4, TP5, TP6, TP7, TP9, TP10, TP13: TPTP15R; TP15R
U11: SARA-R4
U12: SIM-ST-MFF2; PSON127P500X600X82-9N
U$1: ANT-LTE-SP610-T

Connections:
!SARA_RESET: U11.18 (RESET_N); also elsewhere on the board
+CELL_POWER: C19.1, C20.1, C21.1, C22.1, C23.1, C24.1 (+), U11.51 (VCC), U11.52 (VCC), U11.53 (VCC); also elsewhere on the board
GND: C14.2, C15.2, C16.2, C17.2, C18.2, C19.2, C20.2, C21.2, C22.2, C23.2, C24.2 (-), C51.2, C52.2, U11.1 (GND), U11.3 (GND), U11.5 (GND), U11.14 (GND), U11.20 (GND), U11.21 (GND), U11.22 (GND), U11.30 (GND), U11.32 (GND), U11.43 (GND), U11.50 (GND), U11.54 (GND), U11.55 (GND), U11.57 (GND), U11.58 (GND), U11.59 (GND), U11.60 (GND), U11.61 (GND), U11.63 (GND), U11.64 (GND), U11.65 (GND), U11.66 (GND), U11.67 (GND), U11.68 (GND), U11.69 (GND), U11.70 (GND), U11.71 (GND), U11.72 (GND), U11.73 (GND), U11.74 (GND), U11.75 (GND), U11.76 (GND), U11.77 (GND), U11.78 (GND), U11.79 (GND), U11.80 (GND), U11.81 (GND), U11.82 (GND), U11.83 (GND), U11.84 (GND), U11.85 (GND), U11.86 (GND), U11.87 (GND), U11.88 (GND), U11.89 (GND), U11.90 (GND), U11.91 (GND), U11.92 (GND), U11.93 (GND), U11.94 (GND), U11.95 (GND), U11.96 (GND), U12.1 (GND), U12.9 (EPAD), U$1.2 (GND); also elsewhere on the board
GPS_SCL: R10.2; also elsewhere on the board
GPS_SDA: R11.2; also elsewhere on the board
unnamed: R9.2, TP6.TP, U11.13 (RXD)
unnamed: R8.2, TP5.TP, U11.12 (TXD)
unnamed: R7.2, U11.11 (CTS)
unnamed: R6.2, U11.10 (RTS)
unnamed: C15.1, U11.38 (SIM_CLK), U12.6 (CLK)
unnamed: C16.1, U11.40 (SIM_RST), U12.7 (RST)
unnamed: C51.1, L2.1, U11.56 (ANT)
unnamed: C14.1, U11.39 (SIM_IO), U12.3 (I/O)
unnamed: R10.1, TP7.TP, U11.27 (SCL)
unnamed: R11.1, TP9.TP, U11.26 (SDA)
unnamed: R22.2, U11.28 (USB_D-)
unnamed: R23.2, U11.29 (USB_D+)
unnamed: C52.1, L2.2, U$1.1 (ANT)
unnamed: TP13.TP, U11.17 (VUSB_DET)
SARA_CTS: R7.1; also elsewhere on the board
SARA_D_N: R22.1, TP4.TP
SARA_D_P: R23.1, TP10.TP
SARA_POWER: U11.15 (PWR_ON); also elsewhere on the board
SARA_RTS: R6.1; also elsewhere on the board
SARA_RX: R9.1; also elsewhere on the board
SARA_TX: R8.1; also elsewhere on the board
VSIM: C17.1, C18.1, U11.41 (VSIM), U12.8 (VCC)

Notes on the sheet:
47uF
SARA-R4 LTE CAT M1 Module

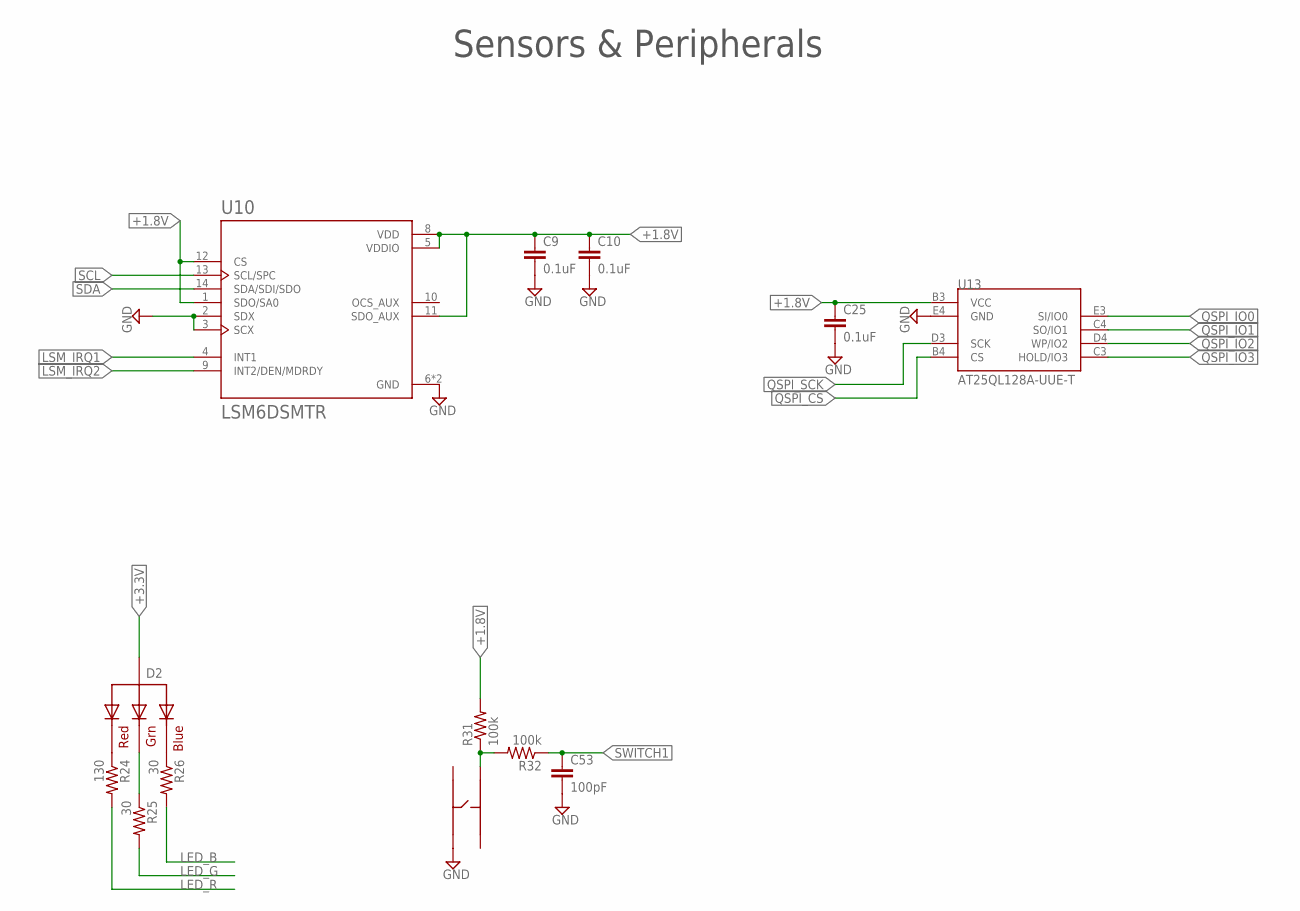
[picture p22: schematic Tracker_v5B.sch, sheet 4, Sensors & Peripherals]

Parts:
C9, C10, C25: 0.1uF; C0201
C53: 100pF; C0201
D2: CLMVC-FKA
R24: 130; R0201
R25, R26: 30; R0201
R31, R32: 100k; R0201
S1: EVQ-7PJ; EVQ-7PJ/A
U10: LSM6DSMTR; PQFN50P300X250X86-14N
U13: AT25QL128A-UUE-T; 21-WLCSP

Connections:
+1.8V: C9.1, C10.1, C25.1, R31.2, U10.1 (SDO/SA0), U10.5 (VDDIO), U10.8 (VDD), U10.11 (SDO_AUX), U10.12 (CS), U13.B3 (VCC); also elsewhere on the board
+3.3V: D2.B1 (VCC); also elsewhere on the board
GND: C9.2, C10.2, C25.2, C53.2, S1.P$1, U10.2 (SDX), U10.3 (SCX), U10.6 (GND), U10.7 (GND), U13.E4 (GND); also elsewhere on the board
LED_B: R26.2; also elsewhere on the board
LED_G: R25.2; also elsewhere on the board
LED_R: R24.2; also elsewhere on the board
LSM_IRQ1: U10.4 (INT1); also elsewhere on the board
LSM_IRQ2: U10.9 (INT2/DEN/MDRDY); also elsewhere on the board
unnamed: D2.B4 (RED), R24.1
unnamed: D2.B3 (GREEN), R25.1
unnamed: D2.B2 (BLUE), R26.1
unnamed: R31.1, R32.2, S1.P$4
QSPI_CS: U13.B4 (CS); also elsewhere on the board
QSPI_IO0: U13.E3 (SI/IO0); also elsewhere on the board
QSPI_IO1: U13.C4 (SO/IO1); also elsewhere on the board
QSPI_IO2: U13.D4 (WP/IO2); also elsewhere on the board
QSPI_IO3: U13.C3 (HOLD/IO3); also elsewhere on the board
QSPI_SCK: U13.D3 (SCK); also elsewhere on the board
SCL: U10.13 (SCL/SPC); also elsewhere on the board
SDA: U10.14 (SDA/SDI/SDO); also elsewhere on the board
SWITCH1: C53.1, R32.1; also elsewhere on the board

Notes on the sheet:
Sensors & Peripherals

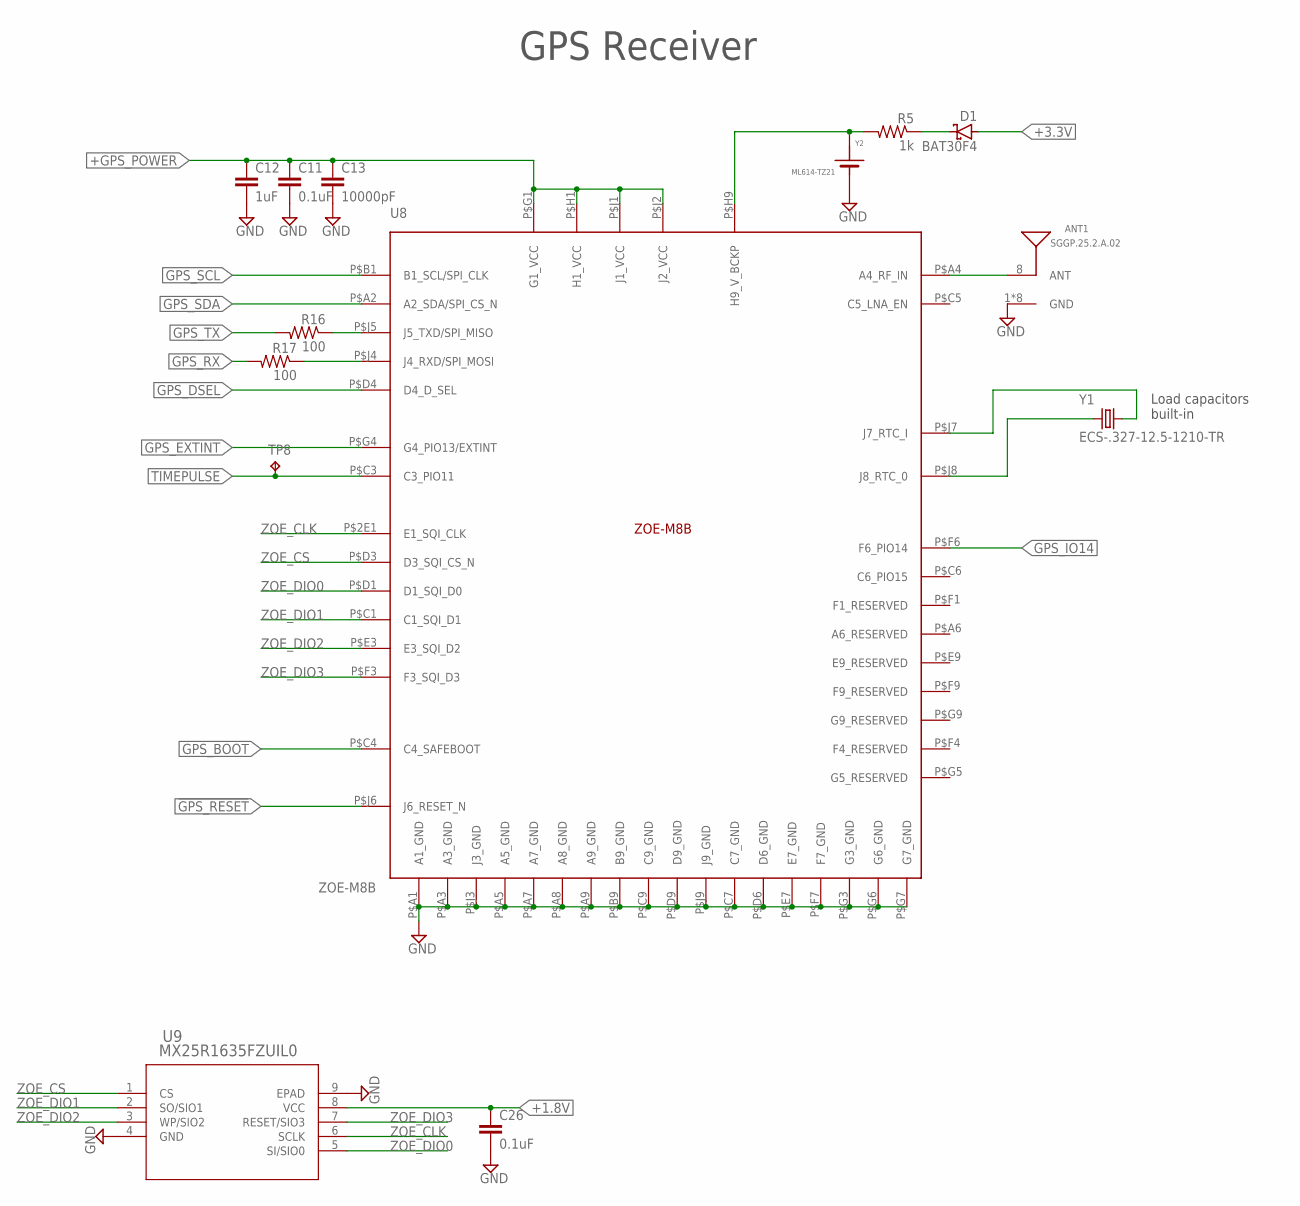
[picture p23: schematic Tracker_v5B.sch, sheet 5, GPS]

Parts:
ANT1: SGGP.25.2.A.02
C11, C26: 0.1uF; C0201
C12: 1uF; C0201
C13: 10000pF; C0201
D1: BAT30F4
R5: 1k; R0201
R16, R17: 100; R0201
TP8: TPTP15R; TP15R
U8: ZOE-M8B; ZOE-M8
U9: MX25R1635FZUIL0; USON-8L-2X3X0P6_MAC
Y1: ECS-.327-12.5-1210-TR
Y2: ML614-TZ21

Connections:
!GPS_RESET: U8.P$J6 (J6_RESET_N); also elsewhere on the board
+1.8V: C26.1, U9.8 (VCC); also elsewhere on the board
+3.3V: D1.2 (A); also elsewhere on the board
+GPS_POWER: C11.1, C12.1, C13.1, U8.P$G1 (G1_VCC), U8.P$H1 (H1_VCC), U8.P$J1 (J1_VCC), U8.P$J2 (J2_VCC); also elsewhere on the board
GND: ANT1.1 (GND), ANT1.2 (GND), ANT1.3 (GND), ANT1.4 (GND), ANT1.5 (GND), ANT1.6 (GND), ANT1.7 (GND), ANT1.9 (GND), C11.2, C12.2, C13.2, C26.2, U8.P$A1 (A1_GND), U8.P$A3 (A3_GND), U8.P$A5 (A5_GND), U8.P$A7 (A7_GND), U8.P$A8 (A8_GND), U8.P$A9 (A9_GND), U8.P$B9 (B9_GND), U8.P$C7 (C7_GND), U8.P$C9 (C9_GND), U8.P$D6 (D6_GND), U8.P$D9 (D9_GND), U8.P$E7 (E7_GND), U8.P$F7 (F7_GND), U8.P$G3 (G3_GND), U8.P$G6 (G6_GND), U8.P$G7 (G7_GND), U8.P$J3 (J3_GND), U8.P$J9 (J9_GND), U9.4 (GND), U9.9 (EPAD), Y2.2; also elsewhere on the board
GPS_BOOT: U8.P$C4 (C4_SAFEBOOT); also elsewhere on the board
GPS_DSEL: U8.P$D4 (D4_D_SEL); also elsewhere on the board
GPS_EXTINT: U8.P$G4 (G4_PIO13/EXTINT); also elsewhere on the board
GPS_IO14: U8.P$F6 (F6_PIO14); also elsewhere on the board
GPS_RX: R17.2; also elsewhere on the board
GPS_SCL: U8.P$B1 (B1_SCL/SPI_CLK); also elsewhere on the board
GPS_SDA: U8.P$A2 (A2_SDA/SPI_CS_N); also elsewhere on the board
GPS_TX: R16.2; also elsewhere on the board
unnamed: U8.P$J8 (J8_RTC_0), Y1.1
unnamed: U8.P$J7 (J7_RTC_I), Y1.2
unnamed: D1.1 (C), R5.1
unnamed: R5.2, U8.P$H9 (H9_V_BCKP), Y2.1
unnamed: R16.1, U8.P$J5 (J5_TXD/SPI_MISO)
unnamed: R17.1, U8.P$J4 (J4_RXD/SPI_MOSI)
unnamed: ANT1.8 (ANT), U8.P$A4 (A4_RF_IN)
TIMEPULSE: TP8.TP, U8.P$C3 (C3_PIO11)
ZOE_CLK: U8.P$2E1 (E1_SQI_CLK), U9.6 (SCLK)
ZOE_CS: U8.P$D3 (D3_SQI_CS_N), U9.1 (CS)
ZOE_DIO0: U8.P$D1 (D1_SQI_D0), U9.5 (SI/SIO0)
ZOE_DIO1: U8.P$C1 (C1_SQI_D1), U9.2 (SO/SIO1)
ZOE_DIO2: U8.P$E3 (E3_SQI_D2), U9.3 (WP/SIO2)
ZOE_DIO3: U8.P$F3 (F3_SQI_D3), U9.7 (RESET/SIO3)

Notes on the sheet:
GPS Receiver
Load capacitors built-in

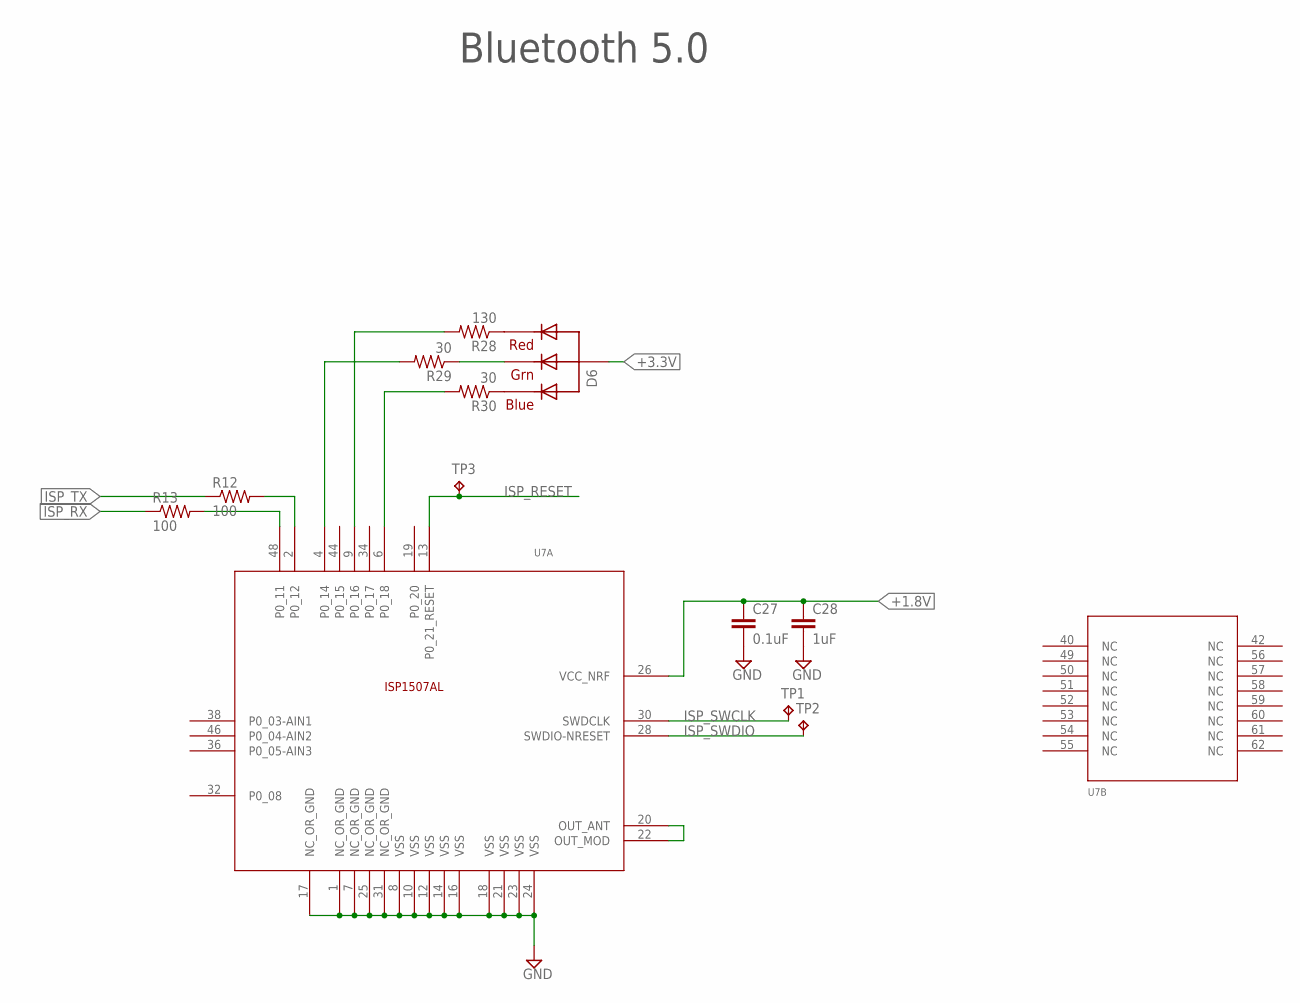
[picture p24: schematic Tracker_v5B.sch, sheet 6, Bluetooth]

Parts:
C27: 0.1uF; C0201
C28: 1uF; C0201
D6: CLMVC-FKA
R12, R13: 100; R0201
R28: 130; R0201
R29, R30: 30; R0201
TP1, TP2, TP3: TPTP15R; TP15R
U7: ISP1507ALISP1507AL_ISP1507-AL; ISP1507-AL

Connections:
+1.8V: C27.1, C28.1, U7.26 (VCC_NRF); also elsewhere on the board
+3.3V: D6.B1 (VCC); also elsewhere on the board
GND: C27.2, C28.2, U7.1 (NC_OR_GND), U7.7 (NC_OR_GND), U7.8 (VSS), U7.10 (VSS), U7.12 (VSS), U7.14 (VSS), U7.16 (VSS), U7.17 (NC_OR_GND), U7.18 (VSS), U7.21 (VSS), U7.23 (VSS), U7.24 (VSS), U7.25 (NC_OR_GND), U7.31 (NC_OR_GND); also elsewhere on the board
ISP_RESET: TP3.TP, U7.13 (P0_21_RESET)
ISP_RX: R13.1; also elsewhere on the board
ISP_SWCLK: TP1.TP, U7.30 (SWDCLK)
ISP_SWDIO: TP2.TP, U7.28 (SWDIO-NRESET)
ISP_TX: R12.1; also elsewhere on the board
unnamed: R12.2, U7.2 (P0_12)
unnamed: R13.2, U7.48 (P0_11)
unnamed: U7.20 (OUT_ANT), U7.22 (OUT_MOD)
unnamed: D6.B4 (RED), R28.1
unnamed: D6.B3 (GREEN), R29.1
unnamed: D6.B2 (BLUE), R30.1
unnamed: R30.2, U7.6 (P0_18)
unnamed: R29.2, U7.4 (P0_14)
unnamed: R28.2, U7.9 (P0_16)

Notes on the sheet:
Bluetooth 5.0

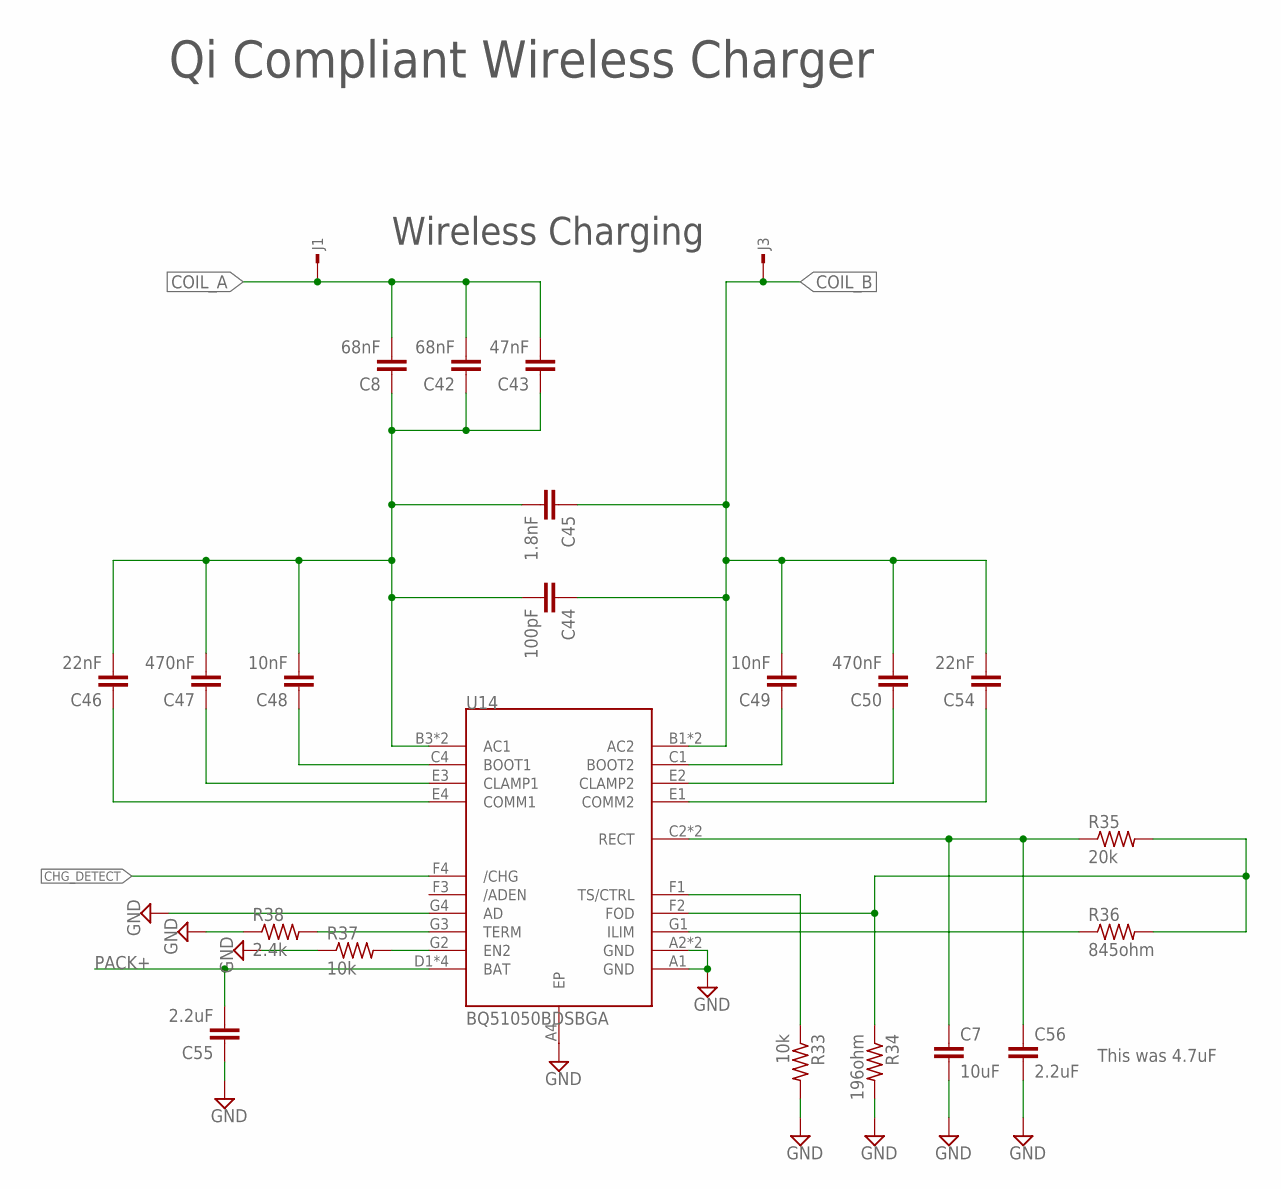
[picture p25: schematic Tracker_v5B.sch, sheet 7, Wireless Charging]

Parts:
C7: 10uF; C0402
C8, C42: 68nF; C0402
C43: 47nF; C0402
C44: 100pF; C0402
C45: 1.8nF; C0402
C46, C54: 22nF; C0402
C47, C50: 470nF; C0402
C48, C49: 10nF; C0402
C55, C56: 2.2uF; C0402
J1, J3: SMD_PADPAD_150X75; PAD_150X75
R33, R37: 10k; R0201
R34: 196ohm; R0201
R35: 20k; R0201
R36: 845ohm; R0201
R38: 2.4k; R0201
U14: BQ51050BDSBGA; YFP28

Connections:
CHG_DETECT: U14.F4 (/CHG); also elsewhere on the board
COIL_A: C8.2, C42.2, C43.2, J1.P$1
COIL_B: C44.1, C45.1, C49.2, C50.2, C54.2, J3.P$1, U14.B1 (AC2), U14.B2 (AC2)
GND: C7.2, C55.1, C56.2, R33.2, R34.2, R37.1, R38.1, U14.A1 (GND), U14.A2 (GND), U14.A3 (GND), U14.A4 (EP), U14.G4 (AD); also elsewhere on the board
unnamed: C46.1, U14.E4 (COMM1)
unnamed: C47.1, U14.E3 (CLAMP1)
unnamed: C48.1, U14.C4 (BOOT1)
unnamed: C54.1, U14.E1 (COMM2)
unnamed: C50.1, U14.E2 (CLAMP2)
unnamed: C49.1, U14.C1 (BOOT2)
unnamed: C8.1, C42.1, C43.1, C44.2, C45.2, C46.2, C47.2, C48.2, U14.B3 (AC1), U14.B4 (AC1)
unnamed: R33.1, U14.F1 (TS/CTRL)
unnamed: R34.1, R35.2, R36.2, U14.F2 (FOD)
unnamed: R36.1, U14.G1 (ILIM)
unnamed: C7.1, C56.1, R35.1, U14.C2 (RECT), U14.C3 (RECT)
unnamed: R37.2, U14.G2 (EN2)
unnamed: R38.2, U14.G3 (TERM)
PACK+: C55.2, U14.D1 (BAT), U14.D2 (BAT), U14.D3 (BAT), U14.D4 (BAT); also elsewhere on the board

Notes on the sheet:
Qi Compliant Wireless Charger
This was 4.7uF
Wireless Charging

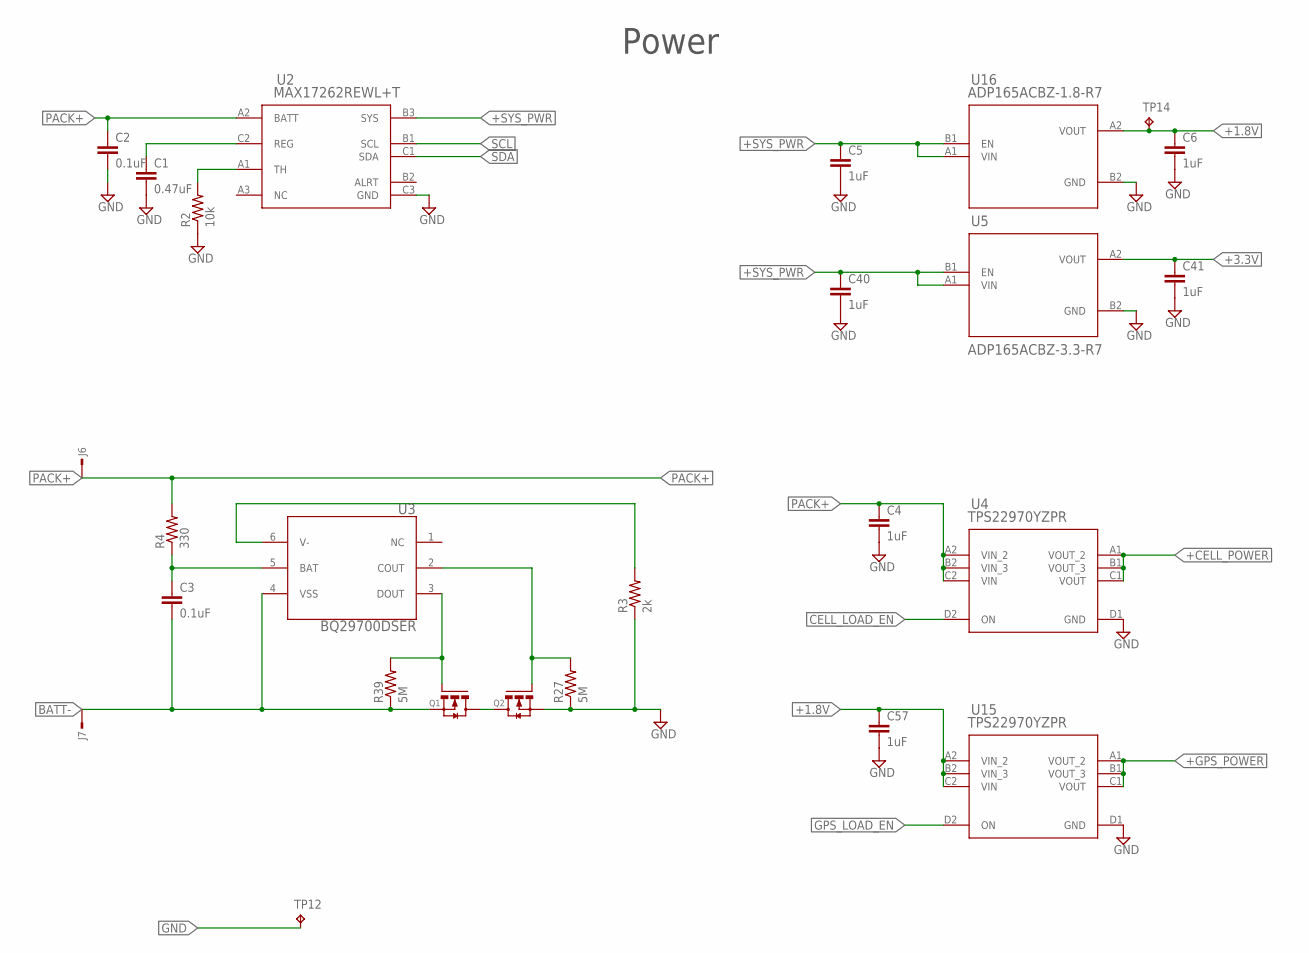
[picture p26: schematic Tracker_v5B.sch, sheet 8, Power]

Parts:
C1: 0.47uF; C0201
C2, C3: 0.1uF; C0201
C4, C5, C6, C40, C41, C57: 1uF; C0201
J6, J7: SMD_PADPAD_4MMX5MM; PAD_4MMX5MM
Q1, Q2: CSD13385F5T; YJK3
R2: 10k; R0201
R3: 2k; R0201
R4: 330; R0201
R27, R39: 5M; R0201
TP12, TP14: TPTP15R; TP15R
U2: MAX17262REWL+T; 21-100221A_W91G1+3
U3: BQ29700DSER; DSE0006A
U4, U15: TPS22970YZPR; YZP0008ADCD
U5: ADP165ACBZ-3.3-R7; CB_4_1
U16: ADP165ACBZ-1.8-R7; CB_4_1

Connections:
+1.8V: C6.1, C57.1, TP14.TP, U15.A2 (VIN_2), U15.B2 (VIN_3), U15.C2 (VIN), U16.A2 (VOUT); also elsewhere on the board
+3.3V: C41.1, U5.A2 (VOUT); also elsewhere on the board
+CELL_POWER: U4.A1 (VOUT_2), U4.B1 (VOUT_3), U4.C1 (VOUT); also elsewhere on the board
+GPS_POWER: U15.A1 (VOUT_2), U15.B1 (VOUT_3), U15.C1 (VOUT); also elsewhere on the board
+SYS_PWR: C5.1, C40.1, U2.B3 (SYS), U5.A1 (VIN), U5.B1 (EN), U16.A1 (VIN), U16.B1 (EN)
BATT-: C3.2, J7.P$1, Q1.2 (S), R39.1, U3.4 (VSS)
CELL_LOAD_EN: U4.D2 (ON); also elsewhere on the board
GND: C1.2, C2.2, C4.2, C5.2, C6.2, C40.2, C41.2, C57.2, Q2.2 (S), R2.1, R3.1, R27.1, TP12.TP, U2.C3 (GND), U4.D1 (GND), U5.B2 (GND), U15.D1 (GND), U16.B2 (GND); also elsewhere on the board
GPS_LOAD_EN: U15.D2 (ON); also elsewhere on the board
unnamed: C1.1, U2.C2 (REG)
unnamed: R2.2, U2.A1 (TH)
unnamed: Q1.3 (D), Q2.3 (D)
unnamed: Q1.1 (G), R39.2, U3.3 (DOUT)
unnamed: Q2.1 (G), R27.2, U3.2 (COUT)
unnamed: C3.1, R4.1, U3.5 (BAT)
unnamed: R3.2, U3.6 (V-)
PACK+: C2.1, C4.1, J6.P$1, R4.2, U2.A2 (BATT), U4.A2 (VIN_2), U4.B2 (VIN_3), U4.C2 (VIN); also elsewhere on the board
SCL: U2.B1 (SCL); also elsewhere on the board
SDA: U2.C1 (SDA); also elsewhere on the board

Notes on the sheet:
Power

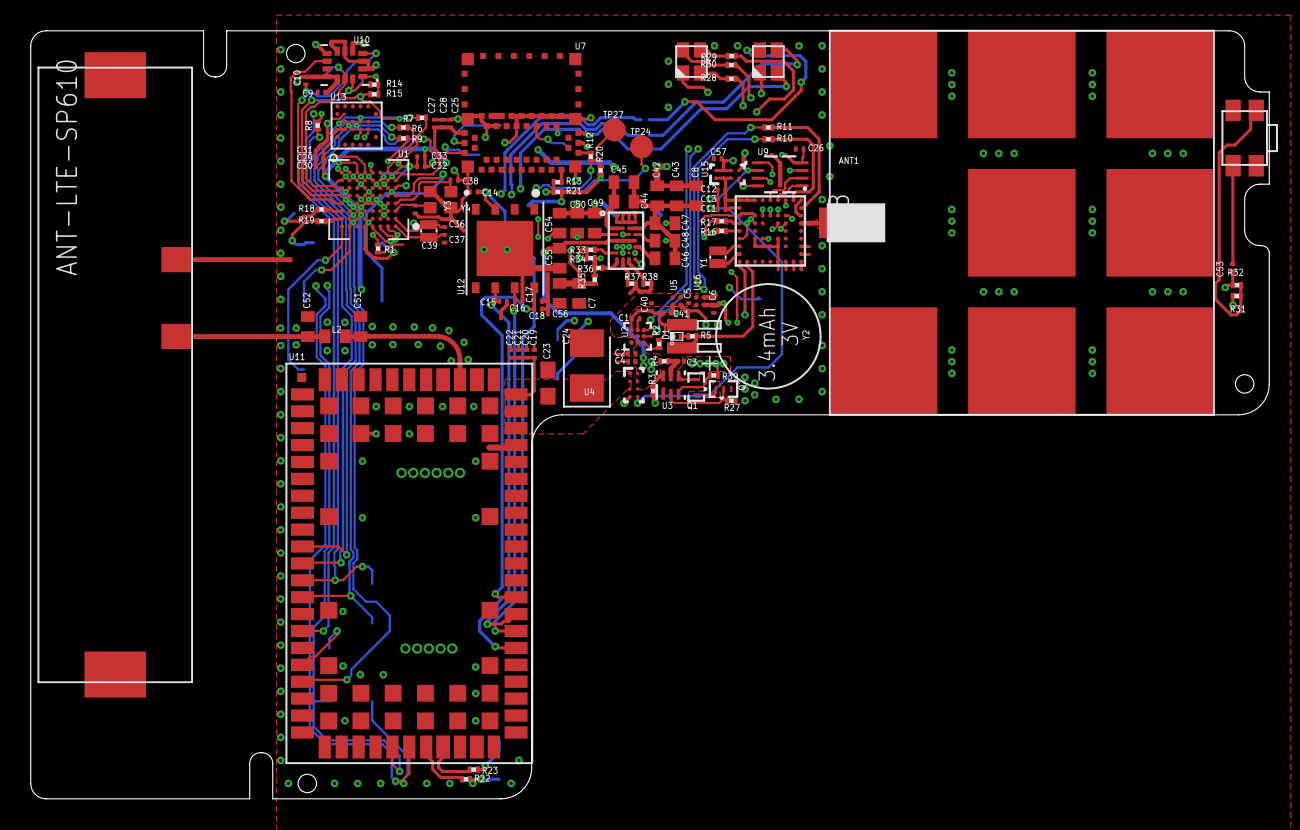
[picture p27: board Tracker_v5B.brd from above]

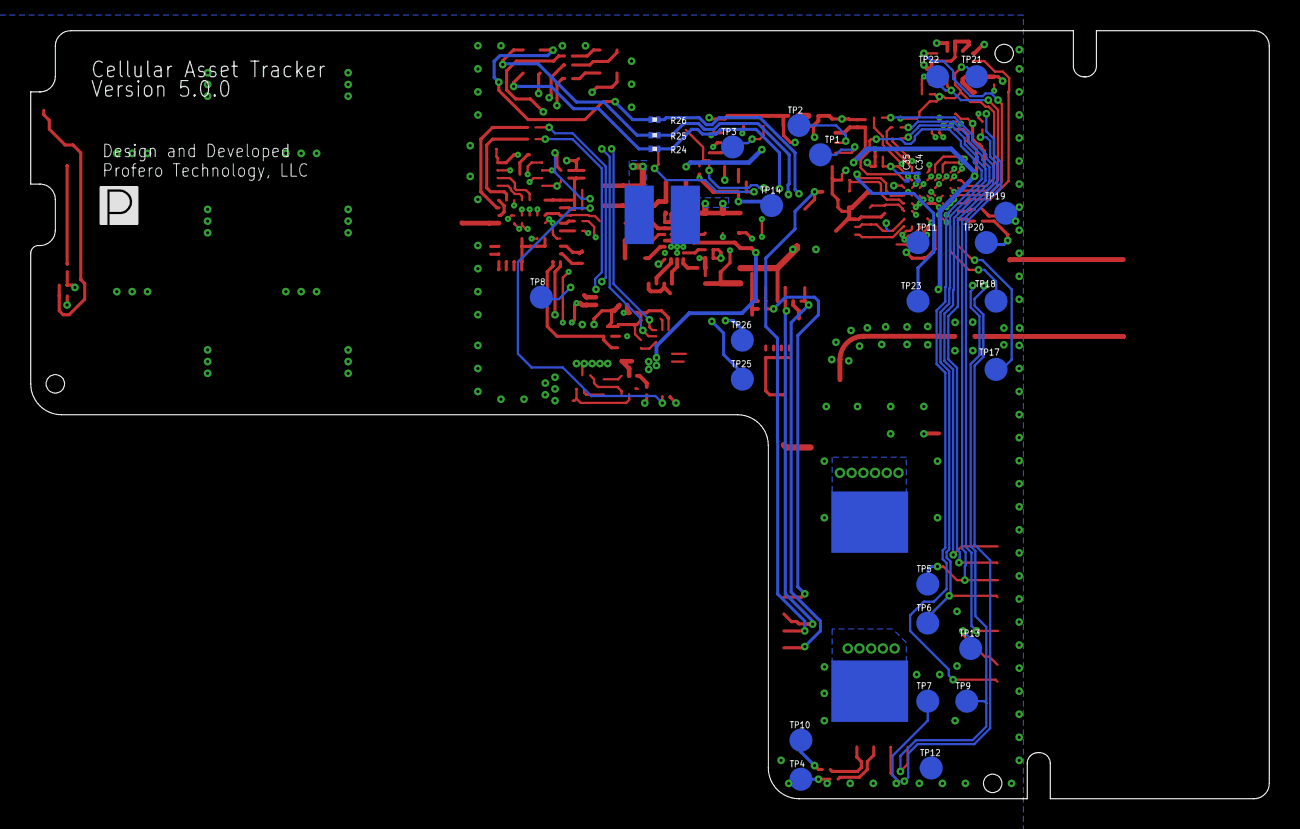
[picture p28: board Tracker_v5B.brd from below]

Board: 4 copper layers, 80.6 x 50.0 mm, 154 parts (33 on the bottom side), 124 nets.

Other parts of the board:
U$2: PROFERO-LOGO-SMALL

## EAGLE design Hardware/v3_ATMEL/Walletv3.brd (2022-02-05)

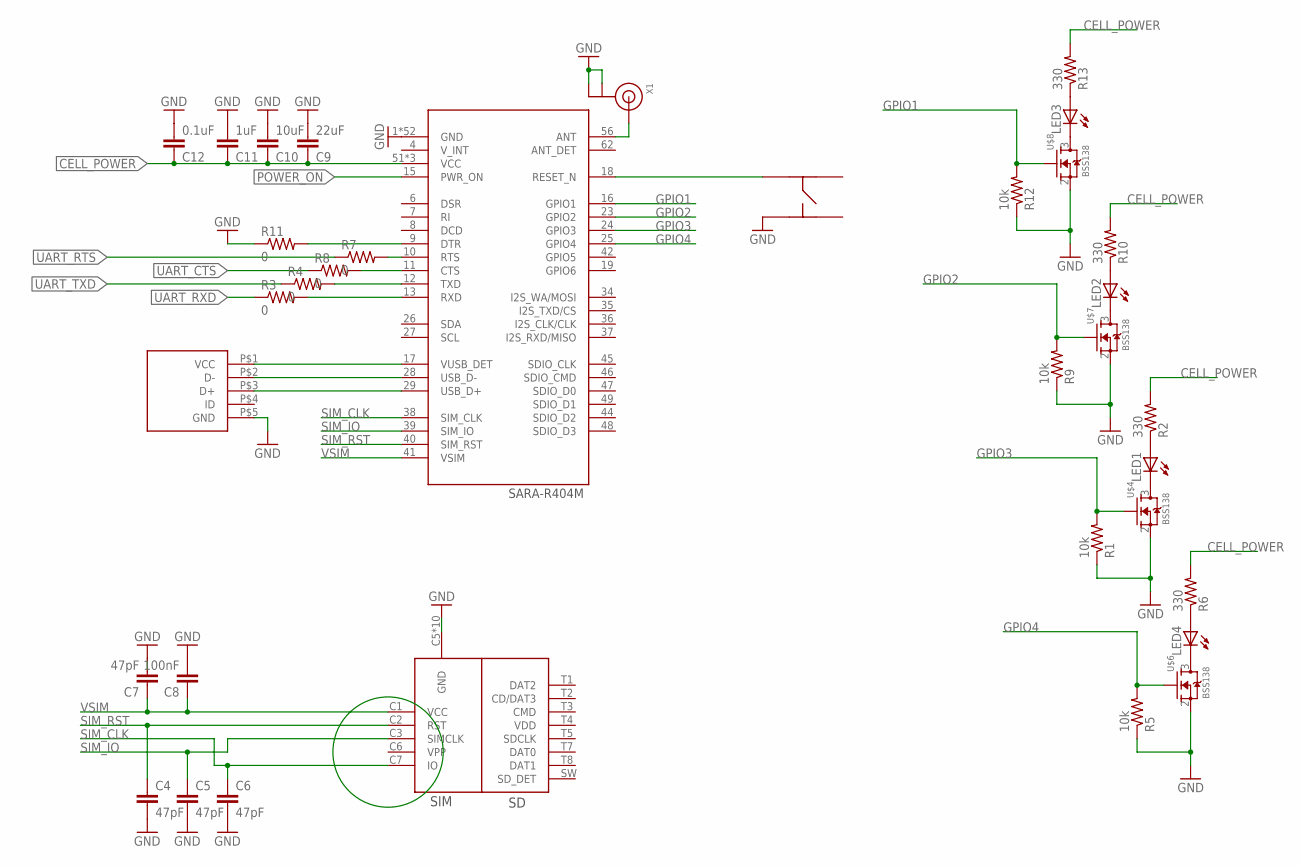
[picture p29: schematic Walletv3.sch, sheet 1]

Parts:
C4, C5, C6, C7: 47pF; C0402
C8: 100nF; C0402
C9: 22uF; C0805
C10: 10uF; C0603
C11: 1uF; C0402
C12: 0.1uF; C0402
LED1, LED2, LED3, LED4: LEDCHIPLED_0603; CHIPLED_0603
R1, R5, R9, R12: 10k; R0402
R2, R6, R10, R13: 330; R0402
R3, R4, R7, R8, R11: 0; R0402
U$2: SIM_SD_MOLEX
U$3: SARA-R404M
U$4, U$6, U$7, U$8: BSS138; SOT23-3
U$5: MICRO_USB; MOLEX_USB
U$9: KMR731NG
X1: ANTENNA_U.FL; U.FL

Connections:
CELL_POWER: C9.1, C10.1, C11.1, C12.1, R2.2, R6.2, R10.2, R13.2, U$3.51 (VCC), U$3.52 (VCC), U$3.53 (VCC); also elsewhere on the board
GND: C4.2, C5.2, C6.2, C7.2, C8.2, C9.2, C10.2, C11.2, C12.2, R1.1, R5.1, R9.1, R11.1, R12.1, U$2.C5 (GND), U$2.G1 (GND), U$2.G2 (GND), U$2.G3 (GND), U$2.G4 (GND), U$2.G5 (GND), U$2.G6 (GND), U$2.G7 (GND), U$2.G8 (GND), U$2.T6 (GND), U$3.1 (GND), U$3.3 (GND), U$3.5 (GND), U$3.14 (GND), U$3.20 (GND), U$3.21 (GND), U$3.22 (GND), U$3.30 (GND), U$3.32 (GND), U$3.43 (GND), U$3.50 (GND), U$3.54 (GND), U$3.55 (GND), U$3.57 (GND), U$3.58 (GND), U$3.59 (GND), U$3.60 (GND), U$3.61 (GND), U$3.63 (GND), U$3.64 (GND), U$3.65 (GND), U$3.66 (GND), U$3.67 (GND), U$3.68 (GND), U$3.69 (GND), U$3.70 (GND), U$3.71 (GND), U$3.72 (GND), U$3.73 (GND), U$3.74 (GND), U$3.75 (GND), U$3.76 (GND), U$3.77 (GND), U$3.78 (GND), U$3.79 (GND), U$3.80 (GND), U$3.81 (GND), U$3.82 (GND), U$3.83 (GND), U$3.84 (GND), U$3.85 (GND), U$3.86 (GND), U$3.87 (GND), U$3.88 (GND), U$3.89 (GND), U$3.90 (GND), U$3.91 (GND), U$3.92 (GND), U$3.93 (GND), U$3.94 (GND), U$3.95 (GND), U$3.96 (GND), U$4.2 (S), U$5.P$5 (GND), U$6.2 (S), U$7.2 (S), U$8.2 (S), U$9.P$4, X1.1 (GND), X1.2 (GND); also elsewhere on the board
GPIO1: R12.2, U$3.16 (GPIO1), U$8.1 (G)
GPIO2: R9.2, U$3.23 (GPIO2), U$7.1 (G)
GPIO3: R1.2, U$3.24 (GPIO3), U$4.1 (G)
GPIO4: R5.2, U$3.25 (GPIO4), U$6.1 (G)
unnamed: U$3.17 (VUSB_DET), U$5.P$1 (VCC)
unnamed: U$3.28 (USB_D-), U$5.P$2 (D-)
unnamed: U$3.29 (USB_D+), U$5.P$3 (D+)
unnamed: LED1.C, U$4.3 (D)
unnamed: U$3.18 (RESET_N), U$9.P$1
unnamed: LED1.A, R2.1
unnamed: R4.2, U$3.12 (TXD)
unnamed: R3.2, U$3.13 (RXD)
unnamed: LED2.C, U$7.3 (D)
unnamed: LED2.A, R10.1
unnamed: U$3.56 (ANT), X1.3 (SIGNAL)
unnamed: R11.2, U$3.9 (DTR)
unnamed: LED4.C, U$6.3 (D)
unnamed: LED4.A, R6.1
unnamed: LED3.C, U$8.3 (D)
unnamed: R8.2, U$3.11 (CTS)
unnamed: R7.2, U$3.10 (RTS)
unnamed: LED3.A, R13.1
POWER_ON: U$3.15 (PWR_ON); also elsewhere on the board
SIM_CLK: C6.1, U$2.C7 (IO), U$3.38 (SIM_CLK)
SIM_IO: C5.1, U$2.C3 (SIMCLK), U$3.39 (SIM_IO)
SIM_RST: C4.1, U$2.C2 (RST), U$3.40 (SIM_RST)
UART_CTS: R8.1; also elsewhere on the board
UART_RTS: R7.1; also elsewhere on the board
UART_RXD: R3.1; also elsewhere on the board
UART_TXD: R4.1; also elsewhere on the board
VSIM: C7.1, C8.1, U$2.C1 (VCC), U$3.41 (VSIM)

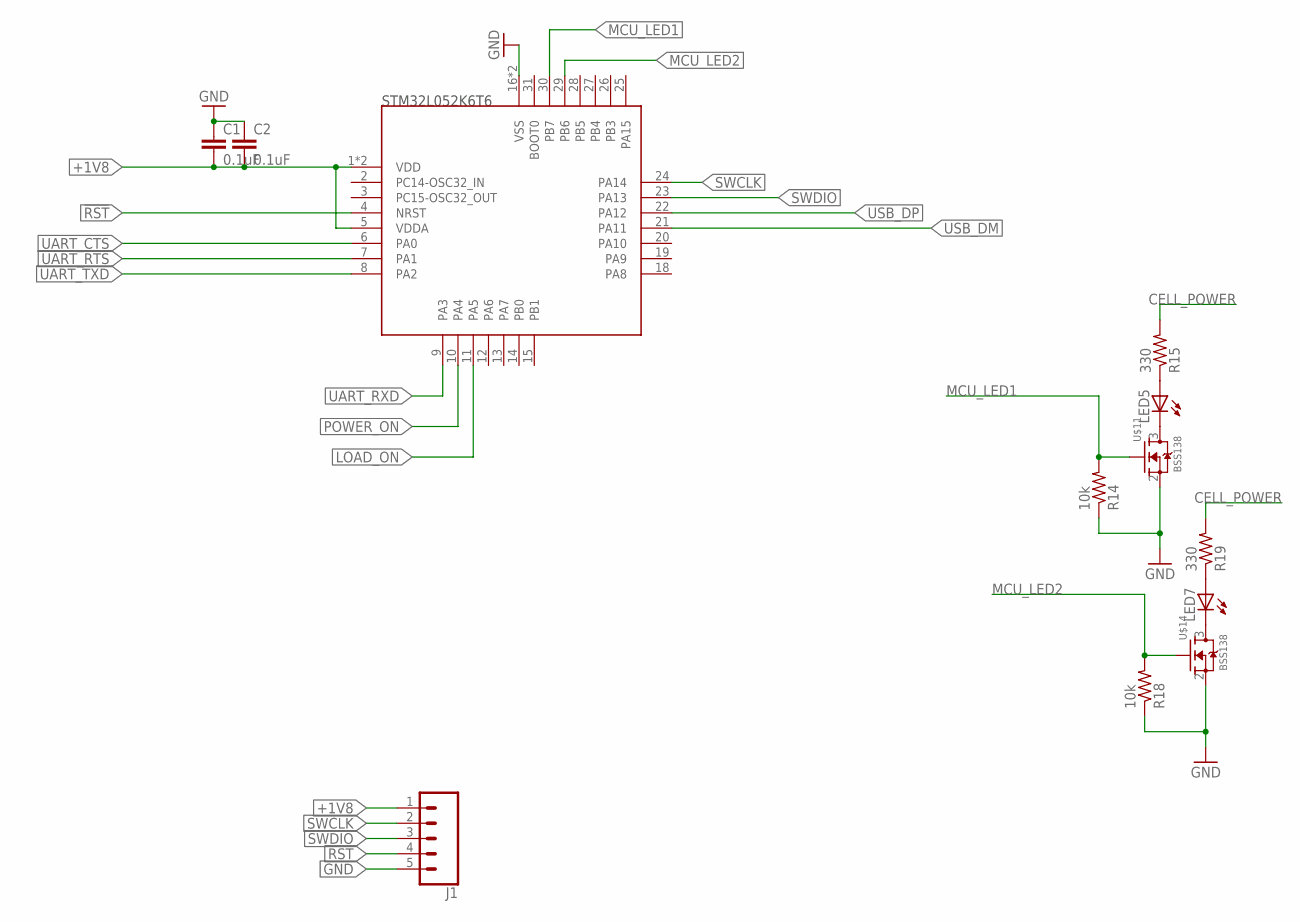
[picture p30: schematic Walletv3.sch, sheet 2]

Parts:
C1, C2: 0.1uF; C0402
J1: CONN_05; 1X05
LED5, LED7: LEDCHIPLED_0603; CHIPLED_0603
R14, R18: 10k; R0402
R15, R19: 330; R0402
U$1: STM32L052K6T6LQFP32-7X7; QFP80P900X900X160-32
U$11, U$14: BSS138; SOT23-3

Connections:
!RST: J1.4, U$1.4 (NRST)
+1V8: C1.2, C2.2, J1.1, U$1.1 (VDD), U$1.5 (VDDA), U$1.17 (VDD); also elsewhere on the board
CELL_POWER: R15.2, R19.2; also elsewhere on the board
GND: C1.1, C2.1, J1.5, R14.1, R18.1, U$1.16 (VSS), U$1.32 (VSS), U$11.2 (S), U$14.2 (S); also elsewhere on the board
LOAD_ON: U$1.11 (PA5); also elsewhere on the board
MCU_LED1: R14.2, U$1.30 (PB7), U$11.1 (G)
MCU_LED2: R18.2, U$1.29 (PB6), U$14.1 (G)
unnamed: LED5.C, U$11.3 (D)
unnamed: LED5.A, R15.1
unnamed: LED7.C, U$14.3 (D)
unnamed: LED7.A, R19.1
POWER_ON: U$1.10 (PA4); also elsewhere on the board
SWCLK: J1.2, U$1.24 (PA14)
SWDIO: J1.3, U$1.23 (PA13)
UART_CTS: U$1.6 (PA0); also elsewhere on the board
UART_RTS: U$1.7 (PA1); also elsewhere on the board
UART_RXD: U$1.9 (PA3); also elsewhere on the board
UART_TXD: U$1.8 (PA2); also elsewhere on the board
USB_DM: U$1.21 (PA11)
USB_DP: U$1.22 (PA12)


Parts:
C3, C13, C16, C17: 1uF; C0402
C14, C15: 4.7uF; C0603
CN1: JST_2PIN-SMT-RA; JST-PH-2-SMT-RA
LED6: LEDCHIP-LED0603; CHIP-LED0603
R16: 2k; R0402
R17: 330; R0402
U1: TPS782XX; SOT23-5L
U$10: TPS22917; SOT23-6
U$12: MICRO_USB; MOLEX_USB
U$13: MCP73831; SOT23-5L

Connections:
+1V8: C13.1, U1.5 (OUT); also elsewhere on the board
CELL_POWER: C16.1, U$10.6 (VOUT); also elsewhere on the board
GND: C3.2, C13.2, C14.2, C15.2, C16.2, C17.2, CN1.2 (1), R16.1, U1.2 (GND), U1.4 (GND), U$10.2 (GND), U$12.P$5 (GND), U$13.2 (VSS); also elsewhere on the board
LOAD_ON: U$10.3 (ON); also elsewhere on the board
unnamed: C14.1, LED6.A, U$12.P$1 (VCC), U$13.4 (VIN)
unnamed: R16.2, U$13.5 (PROG)
unnamed: R17.1, U$13.1 (STAT)
unnamed: LED6.C, R17.2
POWER_IN: C3.1, C15.1, C17.1, CN1.1 (2), U1.1 (IN), U1.3 (EN), U$10.1 (VIN), U$13.3 (VBAT)

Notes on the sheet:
1.8V LDO
Load Switch for R404M

Board: 4 copper layers, 61 parts (12 on the bottom side), 49 nets, no tracks yet.

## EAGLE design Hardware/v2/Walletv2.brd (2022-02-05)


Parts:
C4, C5, C6, C7: 47pF; C0402
C8: 100nF; C0402
C9: 22uF; C0805
C10: 10uF; C0603
C11, C13, C14, C15, C16, C17: 1uF; C0402
C12: 0.1uF; C0402
C18: 39nH; C0402
C19: 15pF; C0402
CN1: JST_2PIN-SMT-RA; JST-PH-2-SMT-RA
IC1: CP2102; MLP28
LED2, LED3, LED4: LEDCHIPLED_0603; CHIPLED_0603
R2: 1k; R0402
R3, R4, R7, R8, R9, R10: 0; R0402
R5: 10k; R0402
R6: 330; R0402
S1, S2: TACTILE_SKRKA
U1, U2: TPS782XX; SOT23-5L
U$1: SARA-N2
U$2: SIM_SD_MOLEX
U$4: SPDT_THRU
U$5: MICRO_USB; MOLEX_USB
U$6: BSS138; SOT23-3
X1: ANTENNA_U.FL; U.FL

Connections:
3.3V: C9.1, C10.1, C11.1, C12.1, C15.1, C16.1, LED2.A, LED3.A, R6.2, U1.5 (OUT), U2.5 (OUT), U$1.51 (VCC), U$1.52 (VCC), U$1.53 (VCC)
CTS: IC1.23 (CTS), R8.1
D_N: IC1.5 (D-), U$5.P$2 (D-)
D_P: IC1.4 (D+), U$5.P$3 (D+)
GND: C4.2, C5.2, C6.2, C7.2, C8.2, C9.2, C10.2, C11.2, C12.2, C13.2, C14.2, C15.2, C16.2, C17.2, C19.2, CN1.2 (1), IC1.3 (GND), IC1.EXP (GND), IC1.M (GND), R5.1, S1.2, S2.1, U1.2 (GND), U1.4 (GND), U2.2 (GND), U2.4 (GND), U$1.1 (GND), U$1.3 (GND), U$1.5 (GND), U$1.14 (GND), U$1.20 (GND), U$1.21 (GND), U$1.22 (GND), U$1.30 (GND), U$1.32 (GND), U$1.43 (GND), U$1.50 (GND), U$1.54 (GND), U$1.55 (GND), U$1.57 (GND), U$1.58 (GND), U$1.59 (GND), U$1.60 (GND), U$1.61 (GND), U$1.63 (GND), U$1.64 (GND), U$1.65 (GND), U$1.66 (GND), U$1.67 (GND), U$1.68 (GND), U$1.69 (GND), U$1.70 (GND), U$1.71 (GND), U$1.72 (GND), U$1.73 (GND), U$1.74 (GND), U$1.75 (GND), U$1.76 (GND), U$1.77 (GND), U$1.78 (GND), U$1.79 (GND), U$1.80 (GND), U$1.81 (GND), U$1.82 (GND), U$1.83 (GND), U$1.84 (GND), U$1.85 (GND), U$1.86 (GND), U$1.87 (GND), U$1.88 (GND), U$1.89 (GND), U$1.90 (GND), U$1.91 (GND), U$1.92 (GND), U$1.93 (GND), U$1.94 (GND), U$1.95 (GND), U$1.96 (GND), U$2.C5 (GND), U$2.G1 (GND), U$2.G2 (GND), U$2.G3 (GND), U$2.G4 (GND), U$2.G5 (GND), U$2.G6 (GND), U$2.G7 (GND), U$2.G8 (GND), U$2.T6 (GND), U$5.P$5 (GND), U$6.2 (S), X1.1 (GND), X1.2 (GND)
unnamed: C18.1, U$1.56 (ANT)
unnamed: C7.1, C8.1, U$1.41 (VSIM), U$2.C1 (VCC)
unnamed: C4.1, U$1.40 (SIM_RST), U$2.C2 (RST)
unnamed: C6.1, U$1.39 (SIM_IO), U$2.C7 (IO)
unnamed: C5.1, U$1.38 (SIM_CLK), U$2.C3 (SIMCLK)
unnamed: S2.2, U$1.18 (RESET_N)
unnamed: R4.2, U$1.12 (TXD)
unnamed: R3.2, U$1.13 (RXD)
unnamed: IC1.9 (!RST), R2.1, S1.1
unnamed: LED2.C, R9.1
unnamed: CN1.1 (2), U$4.3
unnamed: IC1.6 (VDD), R2.2
unnamed: IC1.18 (GPIO1), R10.2
unnamed: LED4.C, U$6.3 (D)
unnamed: LED4.A, R6.1
unnamed: R5.2, U$1.24 (GPIO2), U$6.1 (G)
unnamed: LED3.C, R10.1
unnamed: R8.2, U$1.11 (CTS)
unnamed: R7.2, U$1.10 (RTS)
unnamed: IC1.19 (GPIO0), R9.2
unnamed: C18.2, C19.1, X1.3 (SIGNAL)
POWER_IN: C13.1, C14.1, U1.1 (IN), U1.3 (EN), U2.1 (IN), U2.3 (EN), U$4.2
RTS: IC1.24 (RTS), R7.1
RXD: IC1.25 (RXD), R3.1
TXD: IC1.26 (TXD), R4.1
VBUS: C17.1, IC1.7 (REGIN), IC1.8 (VBUS), U$4.1, U$5.P$1 (VCC)

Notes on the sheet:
pin 4 provide tp
****NOTES****



Board: 4 copper layers, 27.9 x 59.4 mm, 40 parts (12 on the bottom side), 31 nets.

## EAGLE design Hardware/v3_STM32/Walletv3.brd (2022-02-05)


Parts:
C1, C2, C3: 0.1uF; C0402
C4: 1uF; C0402
C5: 10uF; C0603
C6: 22uF; C0805
C7, C8, C10, C11: 47pF; C0402
C9: 100nF; C0402
LED1, LED2, LED3, LED4, LED10, LED11: LEDCHIPLED_0603; CHIPLED_0603
R1, R4, R9, R10, R35, R37: 10k; R0402
R2, R3, R5, R6, R13, R14, R15, R16, R17: 0; R0402
R7, R8, R11, R12, R36, R38: 330; R0402
R39, R40: 29; R0402
S1, S2: KMR731NG
U1, U3, U4, U5, U13, U14: BSS138; SOT23-3
U2: SN74AVC4T774PWRPW16-M; PW16-M
U6: SARA-R404M
U$1: SIM_SD_MOLEX
U$2: MICRO_USB; MOLEX_USB
X1: ANTENNA_U.FL; U.FL

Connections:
+3V3: C2.1, R3.1, R5.2, U2.16 (VCCA); also elsewhere on the board
CELL_POWER: C3.1, C4.1, C5.1, C6.1, R7.2, R8.2, R11.2, R12.2, R36.2, R38.2, U6.51 (VCC), U6.52 (VCC), U6.53 (VCC); also elsewhere on the board
GND: C1.2, C2.2, C3.2, C4.2, C5.2, C6.2, C7.2, C8.2, C9.2, C10.2, C11.2, R1.1, R2.2, R4.1, R6.1, R9.1, R10.1, R13.1, R35.1, R37.1, S1.P$4, S2.P$3, U1.2 (S), U2.9 (!OE), U2.10 (GND), U3.2 (S), U4.2 (S), U5.2 (S), U6.1 (GND), U6.3 (GND), U6.5 (GND), U6.14 (GND), U6.20 (GND), U6.21 (GND), U6.22 (GND), U6.30 (GND), U6.32 (GND), U6.43 (GND), U6.50 (GND), U6.54 (GND), U6.55 (GND), U6.57 (GND), U6.58 (GND), U6.59 (GND), U6.60 (GND), U6.61 (GND), U6.63 (GND), U6.64 (GND), U6.65 (GND), U6.66 (GND), U6.67 (GND), U6.68 (GND), U6.69 (GND), U6.70 (GND), U6.71 (GND), U6.72 (GND), U6.73 (GND), U6.74 (GND), U6.75 (GND), U6.76 (GND), U6.77 (GND), U6.78 (GND), U6.79 (GND), U6.80 (GND), U6.81 (GND), U6.82 (GND), U6.83 (GND), U6.84 (GND), U6.85 (GND), U6.86 (GND), U6.87 (GND), U6.88 (GND), U6.89 (GND), U6.90 (GND), U6.91 (GND), U6.92 (GND), U6.93 (GND), U6.94 (GND), U6.95 (GND), U6.96 (GND), U13.2 (S), U14.2 (S), U$1.C5 (GND), U$1.G1 (GND), U$1.G2 (GND), U$1.G3 (GND), U$1.G4 (GND), U$1.G5 (GND), U$1.G6 (GND), U$1.G7 (GND), U$1.G8 (GND), U$1.T6 (GND), U$2.P$5 (GND), X1.1 (GND), X1.2 (GND); also elsewhere on the board
GPIO1: R9.2, U4.1 (G), U6.16 (GPIO1)
GPIO2: R10.2, U5.1 (G), U6.23 (GPIO2)
GPIO3: R1.2, U1.1 (G), U6.24 (GPIO3)
GPIO4: R4.2, U3.1 (G), U6.25 (GPIO4)
GPIO5: R37.2, U6.42 (GPIO5), U14.1 (G)
GPIO6: R35.2, U6.19 (GPIO6), U13.1 (G)
unnamed: U6.17 (VUSB_DET), U$2.P$1 (VCC)
unnamed: R39.1, U$2.P$2 (D-)
unnamed: R40.1, U$2.P$3 (D+)
unnamed: LED1.C, U1.3 (D)
unnamed: R2.1, U2.2 (DIR2)
unnamed: LED1.A, R7.1
unnamed: R15.2, U6.12 (TXD)
unnamed: R14.2, U6.13 (RXD)
unnamed: LED4.C, U5.3 (D)
unnamed: LED4.A, R12.1
unnamed: U6.56 (ANT), X1.3 (SIGNAL)
unnamed: R13.2, U6.9 (DTR)
unnamed: LED2.C, U3.3 (D)
unnamed: LED2.A, R8.1
unnamed: LED3.C, U4.3 (D)
unnamed: R16.2, U6.11 (CTS)
unnamed: R17.2, U6.10 (RTS)
unnamed: LED3.A, R11.1
unnamed: R17.1, U2.14 (B1)
unnamed: R16.1, U2.13 (B2)
unnamed: R15.1, U2.12 (B3)
unnamed: R14.1, U2.11 (B4)
unnamed: R5.1, U2.1 (DIR1)
unnamed: R3.2, U2.7 (DIR3)
unnamed: R6.2, U2.8 (DIR4)
unnamed: LED10.C, U13.3 (D)
unnamed: LED10.A, R36.1
unnamed: LED11.C, U14.3 (D)
unnamed: LED11.A, R38.1
unnamed: R39.2, U6.28 (USB_D-)
unnamed: R40.2, U6.29 (USB_D+)
POWER_ON: S2.P$1, U6.15 (PWR_ON); also elsewhere on the board
R404M_RESET: S1.P$1, U6.18 (RESET_N); also elsewhere on the board
SIM_CLK: C10.1, U6.38 (SIM_CLK), U$1.C3 (SIMCLK)
SIM_IO: C11.1, U6.39 (SIM_IO), U$1.C7 (IO)
SIM_RST: C8.1, U6.40 (SIM_RST), U$1.C2 (RST)
UART_CTS: U2.4 (A2); also elsewhere on the board
UART_RTS: U2.3 (A1); also elsewhere on the board
UART_RXD: U2.6 (A4); also elsewhere on the board
UART_TXD: U2.5 (A3); also elsewhere on the board
VSIM: C7.1, C9.1, U6.41 (VSIM), U$1.C1 (VCC)
V_INT: C1.1, U2.15 (VCCB), U6.4 (V_INT)

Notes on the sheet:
Uni-Directional Voltage Translation
LTE CAT M1 / NB-IOT Module
Cell GPIO LEDs
SIM Card
NEED TO ADD ESD


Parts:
C12: 1uF; C0402
C13, C14: 0.1uF; C0402
IC1: CP2102; MLP28
J1: CONN_05; 1X05
LED5, LED6, LED7, LED8: LEDCHIPLED_0603; CHIPLED_0603
R18, R19, R20, R21, R24, R26, R27, R28: dnp; R0402
R22: 1k; R0402
R23, R25: 0; R0402
R29, R30: 10k; R0402
R31, R32: 330; R0402
R41, R42: 29; R0402
S3, S4: KMR731NG
U7: STM32L052K6T6LQFP32-7X7; QFP80P900X900X160-32
U8, U9: BSS138; SOT23-3
U$3, U$4: MICRO_USB; MOLEX_USB
Y1: 32.768kHz; CRYSTAL-SMD-3.2X1.5MM

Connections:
!RST: J1.4, S4.P$1, U7.4 (NRST)
+3V3: C13.2, C14.2, J1.1, LED5.A, LED6.A, U7.1 (VDD), U7.5 (VDDA), U7.17 (VDD); also elsewhere on the board
D_N: IC1.5 (D-), U$3.P$2 (D-)
D_P: IC1.4 (D+), U$3.P$3 (D+)
GND: C12.2, C13.1, C14.1, IC1.3 (GND), IC1.EXP (GND), IC1.M (GND), J1.5, R29.1, R30.1, S3.P$4, S4.P$4, U7.16 (VSS), U7.32 (VSS), U8.2 (S), U9.2 (S), U$3.P$5 (GND), U$4.P$5 (GND); also elsewhere on the board
LOAD_ON: U7.11 (PA5); also elsewhere on the board
MCU_LED1: R29.2, U7.30 (PB7), U8.1 (G)
MCU_LED2: R30.2, U7.29 (PB6), U9.1 (G)
unnamed: LED7.C, U8.3 (D)
unnamed: LED7.A, R31.1
unnamed: LED8.C, U9.3 (D)
unnamed: LED8.A, R32.1
unnamed: IC1.9 (!RST), R22.1, S3.P$1
unnamed: IC1.6 (VDD), R22.2
unnamed: LED6.C, R25.1
unnamed: IC1.18 (GPIO1), R23.2
unnamed: LED5.C, R23.1
unnamed: IC1.19 (GPIO0), R25.2
unnamed: IC1.26 (TXD), R24.2
unnamed: IC1.25 (RXD), R26.2
unnamed: R18.1, U7.6 (PA0)
unnamed: R19.1, U7.7 (PA1)
unnamed: IC1.24 (RTS), R27.2
unnamed: IC1.23 (CTS), R28.2
unnamed: R20.1, U7.8 (PA2)
unnamed: R21.1, U7.9 (PA3)
unnamed: U7.2 (PC14-OSC32_IN), Y1.P$2 (2)
unnamed: U7.3 (PC15-OSC32_OUT), Y1.P$1 (1)
unnamed: R41.2, U7.22 (PA12)
unnamed: R42.2, U7.21 (PA11)
POWER_IN: R31.2, R32.2; also elsewhere on the board
POWER_ON: U7.10 (PA4); also elsewhere on the board
R404M_RESET: U7.12 (PA6); also elsewhere on the board
SWCLK: J1.2, U7.24 (PA14)
SWDIO: J1.3, U7.23 (PA13)
UART_CTS: R18.2, R28.1; also elsewhere on the board
UART_RTS: R19.2, R27.1; also elsewhere on the board
UART_RXD: R21.2, R26.1; also elsewhere on the board
UART_TXD: R20.2, R24.1; also elsewhere on the board
USB_DM: R42.1, U$4.P$2 (D-)
USB_DP: R41.1, U$4.P$3 (D+)
VBUS: C12.1, IC1.7 (REGIN), IC1.8 (VBUS), U$3.P$1 (VCC); also elsewhere on the board
VIN: U$4.P$1 (VCC)

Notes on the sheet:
FTDI Serial Com.
ARM M0 MCU


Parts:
C15, C17, C19, C20: 1uF; C0402
C16, C18: 4.7uF; C0603
CN1: JST_2PIN-SMT-RA; JST-PH-2-SMT-RA
J3: CONN_02; 1X02
LED9: LEDCHIP-LED0603; CHIP-LED0603
R33: 330; R0402
R34: 2k; R0402
U10: TPS782XX; SOT23-5L
U11: MCP73831; SOT23-5L
U12: TPS22917; SOT23-6

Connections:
+3V3: C17.1, U10.5 (OUT); also elsewhere on the board
CELL_POWER: C20.1, U12.6 (VOUT); also elsewhere on the board
GND: C15.2, C16.2, C17.2, C18.2, C19.2, C20.2, CN1.2 (1), J3.1, R34.1, U10.2 (GND), U10.4 (GND), U11.2 (VSS), U12.2 (GND); also elsewhere on the board
LOAD_ON: U12.3 (ON); also elsewhere on the board
unnamed: R34.2, U11.5 (PROG)
unnamed: R33.1, U11.1 (STAT)
unnamed: LED9.C, R33.2
POWER_IN: C15.1, C18.1, C19.1, CN1.1 (2), J3.2, U10.1 (IN), U10.3 (EN), U11.3 (VBAT), U12.1 (VIN); also elsewhere on the board
VBUS: C16.1, LED9.A, U11.4 (VIN); also elsewhere on the board

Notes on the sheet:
+3.3V LDO
Load Switch for R404M
Battery Charging



Board: 2 copper layers, 54.0 x 54.0 mm, 101 parts (33 on the bottom side), 88 nets.

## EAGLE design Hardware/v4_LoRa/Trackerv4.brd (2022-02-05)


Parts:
C32, C33, C34, C36: 0.1uF; C0402
CR7, CR8: PESD0402-140; PESD0402
J7: MICRO_USB_VERTICAL
LED1, LED2, LED3, LED4: LEDCHIP-LED0603; CHIP-LED0603
R1, R2, R34, R35, R36: 100k; R0402
R32, R33: 4.7k; R0402
S1, S2, S3, S4, S5: KMR731NG
SJ16, SJ17, SJ18: SOLDERJUMPERREFLOW_NOPASTE; SOLDERJUMPER_REFLOW_NOPASTE
U$1: STM32L422RBT6; QFP50P1200X1200X160-64

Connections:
!CELL_RESET: U$1.21 (PA5); also elsewhere on the board
!GPS_RESET: U$1.10 (PC2); also elsewhere on the board
!LORA_RESET: U$1.58 (PB6); also elsewhere on the board
+3V3_MAIN: C32.1, C33.1, C34.1, C36.1, R32.1, R33.1, SJ16.1, SJ18.1, U$1.19 (VDD1), U$1.32 (VDD2), U$1.48 (VDDUSB), U$1.64 (VDD3); also elsewhere on the board
CELL_CTS: U$1.14 (PA0); also elsewhere on the board
CELL_POWER_EN: U$1.25 (PC5); also elsewhere on the board
CELL_RTS: U$1.15 (PA1); also elsewhere on the board
CELL_RX: U$1.17 (PA3); also elsewhere on the board
CELL_TURN_ON: U$1.20 (PA4); also elsewhere on the board
CELL_TX: U$1.16 (PA2); also elsewhere on the board
GND: C32.2, C33.2, C34.2, C36.2, CR7.1 (11), CR8.1 (11), J7.5 (GND), R1.2, R2.2, R34.2, R35.2, R36.2, S1.P$1, S2.P$1, S3.P$1, S4.P$1, S5.P$1, SJ17.1, U$1.18 (VSS1), U$1.31 (VSS2), U$1.47 (VSS3), U$1.63 (VSS4); also elsewhere on the board
GPS_POWER_EN: U$1.26 (PB0); also elsewhere on the board
GPS_RX: U$1.42 (PA9); also elsewhere on the board
GPS_SCL: R32.2, U$1.8 (PC0); also elsewhere on the board
GPS_SDA: R33.2, U$1.9 (PC1); also elsewhere on the board
GPS_TX: U$1.43 (PA10); also elsewhere on the board
JTAG_RESET: S1.P$4, U$1.7 (NRST); also elsewhere on the board
JTAG_SWCLK: U$1.49 (PA14); also elsewhere on the board
JTAG_SWDIO: U$1.46 (PA13); also elsewhere on the board
LORA_MISO: U$1.56 (PB4); also elsewhere on the board
LORA_MOSI: U$1.57 (PB5); also elsewhere on the board
LORA_NSS: U$1.50 (PA15); also elsewhere on the board
LORA_POWER_EN: U$1.23 (PA7); also elsewhere on the board
LORA_SCK: U$1.55 (PB3); also elsewhere on the board
MCU_USB_N: CR7.2 (22), J7.2 (D-), U$1.44 (PA11)
MCU_USB_P: CR8.2 (22), J7.3 (D+), U$1.45 (PA12)
unnamed: R2.1, U$1.60 (PH3-BOOT0)
unnamed: SJ16.2, U$1.1 (VBAT)
unnamed: SJ17.2, U$1.12 (VSSA/VREF-)
unnamed: SJ18.2, U$1.13 (VDDA/VREF+)
unnamed: S5.P$3, U$1.27 (PB1)
unnamed: S4.P$3, U$1.28 (PB2)
unnamed: S3.P$3, U$1.29 (PB10)
unnamed: S2.P$3, U$1.30 (PB11)
unnamed: LED1.C, R1.1
unnamed: LED2.C, R34.1
unnamed: LED3.C, R35.1
unnamed: LED4.C, R36.1
unnamed: LED1.A, U$1.38 (PC7)
unnamed: LED2.A, U$1.39 (PC8)
unnamed: LED3.A, U$1.40 (PC9)
unnamed: LED4.A, U$1.41 (PA8)
SD_CS: U$1.33 (PB12); also elsewhere on the board
SD_DET: U$1.22 (PA6); also elsewhere on the board
SD_MISO: U$1.35 (PB14); also elsewhere on the board
SD_MOSI: U$1.36 (PB15); also elsewhere on the board
SD_POWER_EN: U$1.24 (PC4); also elsewhere on the board
SD_SCK: U$1.34 (PB13); also elsewhere on the board

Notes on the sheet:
SPI1 Interface
SPI2 Interface
USART2 Interface
USB2.0 Interface
USART1 Interface
Jumper open


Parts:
C4, C13, C14: 0.1uF; C0402
C5: 10uF; C0603
C6: 22uF; C0805
C7, C8, C10, C11: 47pF; C0402
C9: 100nF; C0402
C12: 1uF; C0402
CR1, CR2, CR3, CR4, CR5, CR6: PESD0402-140; PESD0402
Q1, Q2: BSS138; SOT23-3
R5, R6, R18, R19: 0; R0402
R10, R11: 1M; R0402
R27: 100k; R0402
R39, R40: 29; R0402
SJ3, SJ4, SJ5, SJ6, SJ7: SOLDERJUMPERCLOSED; SOLDERJUMPER_CLOSEDWIRE
U2: SN74AVC4T774PWR; PW16
U6: SARA-R404M
U$5: SIM_SD_MOLEX
U$6: MICRO_USB; MOLEX_USB
X1: ANTENNA_U.FL; U.FL

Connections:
!CELL_RESET: Q1.1 (G), R10.2; also elsewhere on the board
+3V3_MAIN: C13.1, R5.2, R18.1, U2.16 (VCCA); also elsewhere on the board
+3V3_SD: R27.2, U$5.T4 (VDD); also elsewhere on the board
+3V7_CELL: C4.1, C5.1, C6.1, C12.1, U6.51 (VCC), U6.52 (VCC), U6.53 (VCC); also elsewhere on the board
CELL_CTS: U2.4 (A2); also elsewhere on the board
CELL_D_N: CR6.2 (22), R39.1, U$6.P$2 (D-)
CELL_D_P: CR5.2 (22), R40.1, U$6.P$3 (D+)
CELL_RTS: U2.3 (A1); also elsewhere on the board
CELL_RX: U2.6 (A4); also elsewhere on the board
CELL_TURN_ON: Q2.1 (G), R11.2; also elsewhere on the board
CELL_TX: U2.5 (A3); also elsewhere on the board
GND: C4.2, C5.2, C6.2, C7.2, C8.2, C9.2, C10.2, C11.2, C12.2, C13.2, C14.2, CR1.1 (11), CR2.1 (11), CR3.1 (11), CR4.1 (11), CR5.1 (11), CR6.1 (11), Q1.3 (D), Q2.3 (D), R6.2, R10.1, R11.1, R19.1, SJ3.1, U2.9 (!OE), U2.10 (GND), U6.1 (GND), U6.3 (GND), U6.5 (GND), U6.14 (GND), U6.20 (GND), U6.21 (GND), U6.22 (GND), U6.30 (GND), U6.32 (GND), U6.43 (GND), U6.50 (GND), U6.54 (GND), U6.55 (GND), U6.57 (GND), U6.58 (GND), U6.59 (GND), U6.60 (GND), U6.61 (GND), U6.63 (GND), U6.64 (GND), U6.65 (GND), U6.66 (GND), U6.67 (GND), U6.68 (GND), U6.69 (GND), U6.70 (GND), U6.71 (GND), U6.72 (GND), U6.73 (GND), U6.74 (GND), U6.75 (GND), U6.76 (GND), U6.77 (GND), U6.78 (GND), U6.79 (GND), U6.80 (GND), U6.81 (GND), U6.82 (GND), U6.83 (GND), U6.84 (GND), U6.85 (GND), U6.86 (GND), U6.87 (GND), U6.88 (GND), U6.89 (GND), U6.90 (GND), U6.91 (GND), U6.92 (GND), U6.93 (GND), U6.94 (GND), U6.95 (GND), U6.96 (GND), U$5.C5 (GND), U$5.G1 (GND), U$5.G2 (GND), U$5.G3 (GND), U$5.G4 (GND), U$5.G5 (GND), U$5.G6 (GND), U$5.G7 (GND), U$5.G8 (GND), U$5.T6 (GND), U$6.P$5 (GND), X1.1 (GND), X1.2 (GND); also elsewhere on the board
GPIO1: U6.16 (GPIO1); also elsewhere on the board
GPIO2: U6.23 (GPIO2); also elsewhere on the board
GPIO3: U6.24 (GPIO3); also elsewhere on the board
GPIO4: U6.25 (GPIO4); also elsewhere on the board
GPIO5: U6.42 (GPIO5); also elsewhere on the board
GPIO6: U6.19 (GPIO6); also elsewhere on the board
unnamed: U6.17 (VUSB_DET), U$6.P$1 (VCC)
unnamed: SJ6.2, U6.12 (TXD)
unnamed: SJ7.2, U6.13 (RXD)
unnamed: Q1.2 (S), U6.18 (RESET_N)
unnamed: U6.56 (ANT), X1.3 (SIGNAL)
unnamed: SJ3.2, U6.9 (DTR)
unnamed: SJ5.2, U6.11 (CTS)
unnamed: SJ4.2, U6.10 (RTS)
unnamed: R6.1, U2.2 (DIR2)
unnamed: R5.1, U2.1 (DIR1)
unnamed: R18.2, U2.7 (DIR3)
unnamed: R19.2, U2.8 (DIR4)
unnamed: R39.2, U6.28 (USB_D-)
unnamed: R40.2, U6.29 (USB_D+)
SARA_CTS: SJ5.1, U2.13 (B2)
SARA_POWER_ON: Q2.2 (S), U6.15 (PWR_ON)
SARA_RTS: SJ4.1, U2.14 (B1)
SARA_RX: SJ7.1, U2.11 (B4)
SARA_TX: SJ6.1, U2.12 (B3)
SD_CS: U$5.T2 (CD/DAT3); also elsewhere on the board
SD_DET: R27.1, U$5.SW (SD_DET); also elsewhere on the board
SD_MISO: U$5.T7 (DAT0); also elsewhere on the board
SD_MOSI: U$5.T3 (CMD); also elsewhere on the board
SD_SCK: U$5.T5 (SDCLK); also elsewhere on the board
SIM_CLK: C10.1, CR3.2 (22), U6.38 (SIM_CLK), U$5.C3 (SIMCLK)
SIM_IO: C11.1, CR4.2 (22), U6.39 (SIM_IO), U$5.C7 (IO)
SIM_RST: C8.1, CR2.2 (22), U6.40 (SIM_RST), U$5.C2 (RST)
VSIM: C7.1, C9.1, CR1.2 (22), U6.41 (VSIM), U$5.C1 (VCC)
V_INT: C14.1, U2.15 (VCCB), U6.4 (V_INT)

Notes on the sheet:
Uni-Directional Voltage Translation
LTE CAT M1 / NB-IOT Module
SIM Card
Jumper Closed
UART Bus


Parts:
C1: 47nF; C0402
C2: 47pF; C0402
C3: 3pF; C0402
C16, C18: 6pF; C0402
C21: 10nF; C0402
C37: 5.6pF; C0402
C38, C43: 39pF; C0402
C39, C42: 1.8pF; C0402
C40: 2.4pF; C0402
C41: dnp; C0402
C44, C45: 3.3pF; C0402
C46: 1uF; C0603
C47, C48: 0.1uF; C0402
R4: 100; R0402
SJ1, SJ2: SOLDERJUMPERCLOSED; SOLDERJUMPER_CLOSEDWIRE
SJ8, SJ9: SOLDERJUMPERREFLOW; SOLDERJUMPER_REFLOW
U$2: AFS14AFS14A04-1575.42-T3; AFS14
U$3: MLZ2012N150L; C0805
U$7: SX1262; QFN50P400X400X100-25T260
U$8: MAX-8/M8; MAX-8-M8
U$9: BGS12SN6E6327XTSA1; TSNP-6-8
U$10: 47nH; 0402
U$11: BGA2803; SOT363_6SOIC
U$12: 2.5nH; 0402
U$13: 4.7nH; 0402
U$14: 15nH; 0402
U$15: 9.1nH; 0402
U$16: 0R; 0402
X2: SMACONNECTOR_EDGE; SMA_EDGELAUNCH
X3: SMACONNECTOR_EDGE_UFL; SMA_EDGELAUNCH_UFL
Y1: XRCGB32M000F2P00R0; CRYSTAL-SMD-2.0X1.6MM

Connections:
!GPS_RESET: U$8.P$9 (RESET_N); also elsewhere on the board
!LORA_RESET: U$7.15 (NRESET); also elsewhere on the board
+3V3_GPS: U$8.P$7 (VCC_IO), U$8.P$8 (VCC); also elsewhere on the board
+3V3_LORA: C46.2, C47.2, U$7.1 (VDD_IN), U$7.10 (VBAT), U$7.11 (VBAT_IO), U$9.P$6 (VDD); also elsewhere on the board
DIO2: R4.1, U$7.12 (DIO2)
GND: C1.2, C2.2, C16.2, C18.2, C21.2, C37.2, C39.2, C41.2, C42.2, C44.2, C45.2, C46.1, C47.1, C48.1, U$2.P$2 (GND), U$2.P$3 (GND), U$2.P$5 (GND), U$7.2 (GND1), U$7.5 (GND2), U$7.8 (GND3), U$7.20 (GND4), U$7.25 (GND1), U$8.P$1 (GND), U$8.P$10 (GND), U$8.P$12 (GND), U$9.P$2 (GND), U$11.2 (GND2), U$11.4 (GND1), U$11.5 (GND2), X2.GND@1 (GND4), X2.GND@2 (GND3), X2.GND@3 (GND2), X2.GND@4 (GND1), X3.GND@1 (GND1), X3.GND@2 (GND2), X3.GND@3 (GND3), X3.GND@4 (GND4); also elsewhere on the board
GPS_RX: SJ2.1; also elsewhere on the board
GPS_SCL: SJ8.2; also elsewhere on the board
GPS_SDA: SJ9.2; also elsewhere on the board
GPS_TX: SJ1.1; also elsewhere on the board
LORA_MISO: U$7.16 (MISO); also elsewhere on the board
LORA_MOSI: U$7.17 (MOSI); also elsewhere on the board
LORA_NSS: U$7.19 (NSS); also elsewhere on the board
LORA_SCK: U$7.18 (SCK); also elsewhere on the board
unnamed: SJ1.2, U$8.P$2 (TXD)
unnamed: SJ2.2, U$8.P$3 (RXD)
unnamed: U$3.1, U$7.9 (DCC_SW)
unnamed: C16.1, U$7.3 (XTA), Y1.1
unnamed: C18.1, U$7.4 (XTB), Y1.3 (2)
unnamed: C48.2, U$3.2, U$7.7 (VREG)
unnamed: C21.1, R4.2, U$9.P$4 (CTRL)
unnamed: U$8.P$11 (RF_IN), U$11.3 (OUT)
unnamed: U$2.P$4 (OUT), U$11.6 (IN)
unnamed: SJ8.1, U$8.P$17 (SCL)
unnamed: SJ9.1, U$8.P$16 (SDA)
unnamed: U$8.P$14 (VCC_RF), U$11.1 (VCC)
unnamed: U$2.P$1 (IN), X3.P (ANT)
unnamed: C39.1, U$9.P$1 (RF2), U$13.2
unnamed: C42.1, U$7.21 (RFI_P), U$14.1
unnamed: C1.1, C2.1, U$7.24 (VR_PA), U$10.1
unnamed: C3.1, U$10.2, U$12.1, U$16.2
unnamed: C3.2, C37.1, C38.1, U$12.2
unnamed: C40.1, U$7.22 (RFI_N), U$14.2
unnamed: C40.2, C41.1, U$9.P$3 (RF1)
unnamed: C38.2, U$13.1
unnamed: C43.2, C44.1, U$15.1
unnamed: C45.1, U$15.2, X2.P (ANT)
unnamed: C43.1, U$9.P$5 (RFIN)
unnamed: U$7.23 (RFO), U$16.1

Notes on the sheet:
SX1262 +22dBm LoRa Transceiver
MAX-8 GPS Receiver
Jumper closed
Jumper open


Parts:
C15, C19, C24, C27: 0.1uF; C0402
C17, C20, C22, C23, C25, C26, C28, C29: 1uF; C0402
C30, C31: 10uF; C0805
J2, J3, J4, J6: CONN_02; 1X02
J5: JST_2MM_MALE; JST-2-SMD
R3, R8, R12, R29, R31: 100k; R0402
R7, R9, R28, R30: 100k-dnp; R0402
SJ10, SJ11, SJ12, SJ13: SOLDERJUMPERCLOSED; SOLDERJUMPER_CLOSEDWIRE
U1, U3, U4, U5: TPS22917; SOT23-6
U14: TPS6216X; 8WSON
U$4: VLF3012ST-2R2M1R4; IND_3010
U$17: SPDT_THRU

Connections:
+3V3_GPS: J3.1; also elsewhere on the board
+3V3_LORA: J2.1; also elsewhere on the board
+3V3_MAIN: C20.1, C25.1, C28.1, C31.1, R9.2, R28.2, R30.2, R31.2, U3.1 (VIN), U4.1 (VIN), U5.1 (VIN), U14.P$6 (VOS), U$4.1; also elsewhere on the board
+3V3_SD: J4.1; also elsewhere on the board
+3V7_CELL: J6.1; also elsewhere on the board
CELL_POWER_EN: SJ10.1; also elsewhere on the board
GND: C15.2, C17.2, C19.2, C20.2, C22.2, C23.2, C24.2, C25.2, C26.2, C27.2, C28.2, C29.2, C30.2, C31.2, J5.1 (-), U1.2 (GND), U3.2 (GND), U4.2 (GND), U5.2 (GND), U14.P$1 (PGND), U14.P$4 (AGND), U14.P$5 (FB), U14.P$9 (AGND); also elsewhere on the board
GPS_POWER_EN: SJ12.1; also elsewhere on the board
LORA_POWER_EN: SJ11.1; also elsewhere on the board
unnamed: C15.1, U1.4 (CT)
unnamed: R3.1, U1.5 (QOD)
unnamed: C19.1, U3.4 (CT)
unnamed: R8.1, U3.5 (QOD)
unnamed: R7.1, SJ10.2, U1.3 (ON)
unnamed: R9.1, SJ11.2, U3.3 (ON)
unnamed: C22.1, J6.2, R3.2, U1.6 (VOUT)
unnamed: C23.1, J2.2, R8.2, U3.6 (VOUT)
unnamed: C24.1, U4.4 (CT)
unnamed: R12.1, U4.5 (QOD)
unnamed: R28.1, SJ12.2, U4.3 (ON)
unnamed: C26.1, J3.2, R12.2, U4.6 (VOUT)
unnamed: C27.1, U5.4 (CT)
unnamed: R29.1, U5.5 (QOD)
unnamed: R30.1, SJ13.2, U5.3 (ON)
unnamed: C29.1, J4.2, R29.2, U5.6 (VOUT)
unnamed: J5.2 (+), U$17.2
unnamed: R31.1, U14.P$8 (PG)
unnamed: U14.P$7 (SW), U$4.2
PACK+: C17.1, C30.1, R7.2, U1.1 (VIN), U14.P$2 (VIN), U14.P$3 (EN), U$17.1
SD_POWER_EN: SJ13.1; also elsewhere on the board

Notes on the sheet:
Power Switch & LDO
Jumper closed


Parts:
J1: JST_6_PIN_VERTICAL; JST-6-SMD-VERT-1.0MM
JP1, JP2, JP4: PINHD-1X6; 1X06
LED5, LED6, LED7, LED8, LED9, LED10, LED11, LED12, LED13, LED14, LED15: LEDCHIPLED_0603; CHIPLED_0603
R13, R15, R17, R21, R23, R25: 10k; R0402
R14, R16, R20, R22, R24, R26, R37, R38, R41, R42, R43: 330; R0402
U7, U8, U9, U10, U11, U12: BSS138; SOT23-3

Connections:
!LORA_RESET: JP1.1; also elsewhere on the board
+3V3_GPS: R42.2; also elsewhere on the board
+3V3_LORA: R41.2; also elsewhere on the board
+3V3_MAIN: J1.1, R37.2; also elsewhere on the board
+3V3_SD: R43.2; also elsewhere on the board
+3V7_CELL: R14.2, R16.2, R20.2, R22.2, R24.2, R26.2, R38.2; also elsewhere on the board
CELL_CTS: JP2.2; also elsewhere on the board
CELL_RTS: JP2.3; also elsewhere on the board
CELL_RX: JP2.4; also elsewhere on the board
CELL_TX: JP2.5; also elsewhere on the board
GND: J1.6, JP1.6, JP2.6, JP4.6, LED10.C, LED11.C, LED13.C, LED14.C, LED15.C, R13.1, R15.1, R17.1, R21.1, R23.1, R25.1, U7.2 (S), U8.2 (S), U9.2 (S), U10.2 (S), U11.2 (S), U12.2 (S); also elsewhere on the board
GPIO1: R21.2, U10.1 (G); also elsewhere on the board
GPIO2: R17.2, U9.1 (G); also elsewhere on the board
GPIO3: R15.2, U8.1 (G); also elsewhere on the board
GPIO4: R13.2, U7.1 (G); also elsewhere on the board
GPIO5: R25.2, U12.1 (G); also elsewhere on the board
GPIO6: R23.2, U11.1 (G); also elsewhere on the board
GPS_RX: JP4.4; also elsewhere on the board
GPS_SCL: JP4.2; also elsewhere on the board
GPS_SDA: JP4.3; also elsewhere on the board
GPS_TX: JP4.5; also elsewhere on the board
JTAG_RESET: J1.5; also elsewhere on the board
JTAG_SWCLK: J1.3; also elsewhere on the board
JTAG_SWDIO: J1.2; also elsewhere on the board
JTAG_SWO: J1.4
LORA_MISO: JP1.3; also elsewhere on the board
LORA_MOSI: JP1.2; also elsewhere on the board
LORA_NSS: JP1.5; also elsewhere on the board
LORA_SCK: JP1.4; also elsewhere on the board
unnamed: LED5.C, U7.3 (D)
unnamed: LED5.A, R14.1
unnamed: LED6.C, U8.3 (D)
unnamed: LED6.A, R16.1
unnamed: LED7.C, U9.3 (D)
unnamed: LED7.A, R20.1
unnamed: LED8.C, U10.3 (D)
unnamed: LED8.A, R22.1
unnamed: LED9.C, U11.3 (D)
unnamed: LED9.A, R24.1
unnamed: LED12.C, U12.3 (D)
unnamed: LED12.A, R26.1
unnamed: LED10.A, R37.1
unnamed: LED11.A, R38.1
unnamed: LED13.A, R41.1
unnamed: LED14.A, R42.1
unnamed: LED15.A, R43.1

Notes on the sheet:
Cell GPIO LEDs
Debug Information



Board: 2 copper layers, 79.8 x 59.4 mm, 180 parts (2 on the bottom side), 147 nets.

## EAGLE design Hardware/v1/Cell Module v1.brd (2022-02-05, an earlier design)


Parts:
C1, C3, C23, C28, C29, C32: 1uF; C0402
C2, C19, C22, C31: 10uF; C0603
C4, C5, C6, C7, C24, C27, C30: 100nF; C0402
C8, C9, C10, C11: 47pF; C0402
C12, C17, C18: 100pF; C0402
C13, C14, C15, C16: 27pF; C0402
C20: 33pF; C0402
C21: 330uF; C1210
C25: 10nF; C0402
C26: 100uF; C1206
C33, C34: 4.7uF; C0402
CN1: JST_2PIN-THM; JST-PH-2-THM
CR1, CR2, CR3, CR4, CR5, CR6: PESD0402-140; PESD0402
JP1: PINHD-1X6; 1X06
JP2: PINHD-1X3; 1X03
LED1, LED2, LED3, LED4, LED6, LED7, LED11, LED12, LED13, LED14: LEDCHIP-LED0805; CHIP-LED0805
LED5: LEDCHIP-LED0603; CHIP-LED0603
R1, R3, R5, R7, R21, R23, R29, R31, R32, R33, R36: 330; R0402
R2, R4, R8, R9, R22, R24, R39, R40, R41: 10k; R0402
R6: 2k; R0402
R10, R11, R12, R13: 100; R0402
R14, R15, R16, R17: 2.2k; R0402
R18: 100k; R0402
R19, R20, R25, R26, R27, R28: 0; R0402
R30: 4.7k; R0402
S1, S2, S3, S6: 10-XX; B3F-10XX
U1: ATTINY1634R-SU; 20S2
U2: SN74AVC4T774PWR; PW16
U$1: SARA-G350
U$2: SIM_SD_MOLEX
U$3, U$23: TPS782XX; SOT23-5L
U$4: MCP73831; SOT23-5L
U$5: MICRO_USB; MOLEX_USB
U$6: SPDT_THRU
U$7: A10340
U$8: SJ-43514-SMT-TR
U$9, U$10, U$11, U$12: BSS138; SOT23-3
U$13, U$14: LQG15HS82NJ02; 0402
U$16, U$17, U$18: CG0402MLE-18G; 0402
U$19: MCP2200; SOIC20_65PITCH_LARGER
U$20: CERMOSCILL-AWCSR; AWCSR

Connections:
1.8V: C7.1, C29.1, C30.1, C31.1, U2.15 (VCCB), U$23.5 (OUT)
3.3V: C2.1, C3.1, C5.1, C27.1, C32.1, JP1.2, R8.1, R40.1, U1.11 (VCC), U2.16 (VCCA), U$3.5 (OUT)
CELL_CTS_18: R26.2, U2.13 (B2)
CELL_CTS_33: U1.7 (PA2), U2.4 (A2)
CELL_RTS_18: R25.2, U2.14 (B1)
CELL_RTS_33: U1.6 (PA3), U2.3 (A1)
CTS_: R26.1, U$1.11 (CTS)
GND: C1.2, C2.2, C3.2, C4.2, C5.2, C6.2, C7.2, C8.2, C9.2, C10.2, C11.2, C12.2, C13.1, C14.1, C15.2, C16.2, C21.1, C22.1, C23.1, C24.1, C25.1, C26.2, C27.2, C28.2, C29.2, C30.2, C31.2, C32.2, C33.2, C34.2, CN1.1 (2), CR1.1 (11), CR2.1 (11), CR3.1 (11), CR4.1 (11), CR5.1 (11), CR6.1 (11), JP1.1, JP2.1, R2.2, R4.2, R6.1, R9.2, R22.2, R24.2, R33.1, R36.1, R39.1, R41.1, S1.3, S2.3, S3.1 (S), S3.2 (S1), S6.2 (S1), U1.10 (GND), U2.10 (GND), U$1.1 (GND), U$1.3 (GND), U$1.5 (GND), U$1.9 (DTR), U$1.14 (GND), U$1.20 (GND), U$1.21 (GND), U$1.22 (GND), U$1.30 (GND), U$1.32 (GND), U$1.43 (GND), U$1.50 (GND), U$1.54 (GND), U$1.55 (GND), U$1.57 (GND), U$1.58 (GND), U$1.59 (GND), U$1.60 (GND), U$1.61 (GND), U$1.63 (GND), U$1.64 (GND), U$1.65 (GND), U$1.66 (GND), U$1.67 (GND), U$1.68 (GND), U$1.69 (GND), U$1.70 (GND), U$1.71 (GND), U$1.72 (GND), U$1.73 (GND), U$1.74 (GND), U$1.75 (GND), U$1.76 (GND), U$1.77 (GND), U$1.78 (GND), U$1.79 (GND), U$1.80 (GND), U$1.81 (GND), U$1.82 (GND), U$1.83 (GND), U$1.84 (GND), U$1.85 (GND), U$1.86 (GND), U$1.87 (GND), U$1.88 (GND), U$1.89 (GND), U$1.90 (GND), U$1.91 (GND), U$1.92 (GND), U$1.93 (GND), U$1.94 (GND), U$1.95 (GND), U$1.96 (GND), U$2.C5 (GND), U$2.G1 (GND), U$2.G2 (GND), U$2.G3 (GND), U$2.G4 (GND), U$2.G5 (GND), U$2.G6 (GND), U$2.G7 (GND), U$2.G8 (GND), U$2.T6 (GND), U$3.2 (GND), U$3.4 (GND), U$4.2 (VSS), U$5.P$5 (GND), U$9.2 (S), U$10.2 (S), U$11.2 (S), U$12.2 (S), U$16.2, U$17.1, U$18.1, U$19.20 (GND), U$20.2 (GND), U$23.2 (GND), U$23.4 (GND)
GPIO1: R13.2, U$1.16 (GPIO1)
GPIO2: R12.2, U$1.23 (GPIO2)
GPIO3: R11.2, U$1.24 (GPIO3)
GPIO4: R10.2, U$1.25 (GPIO4)
LED1: LED13.A, U1.18 (PB3)
LED2: LED14.A, U1.17 (PC0)
MISO: JP1.5, U1.19 (PB2), U$19.12 (RX)
MOSI: JP1.4, U1.20 (PB1), U$19.10 (TX)
unnamed: LED7.C, U$19.5 (GP7/TXLED)
unnamed: LED6.C, U$19.6 (GP6/RXLED)
unnamed: LED5.C, U$4.1 (STAT)
unnamed: LED5.A, R5.1
unnamed: LED1.C, R1.2
unnamed: R6.2, U$4.5 (PROG)
unnamed: LED7.A, R7.2
unnamed: C11.1, CR1.2 (22), U$1.38 (SIM_CLK), U$2.C3 (SIMCLK)
unnamed: R1.1, U$9.3 (D)
unnamed: R8.2, U2.1 (DIR1)
unnamed: R9.1, U2.2 (DIR2)
unnamed: LED6.A, R29.2
unnamed: LED2.C, R3.2
unnamed: R3.1, U$10.3 (D)
unnamed: U$19.2 (OSC1), U$20.3 (OUT)
unnamed: U$19.3 (OSC2), U$20.1 (IN)
unnamed: LED3.C, R21.2
unnamed: C10.1, CR2.2 (22), U$1.39 (SIM_IO), U$2.C7 (IO)
unnamed: C9.1, CR3.2 (22), U$1.40 (SIM_RST), U$2.C2 (RST)
unnamed: C8.1, C12.1, CR4.2 (22), U$1.41 (VSIM), U$2.C1 (VCC)
unnamed: R16.2, U$1.46 (MIC_BIAS)
unnamed: C18.1, U$1.48 (MIC_N)
unnamed: C17.1, U$1.49 (MIC_P)
unnamed: C19.2, R14.1, R15.1, R16.1
unnamed: C19.1, R17.2, U$1.47 (MIC_GND), U$14.2
unnamed: C18.2, R14.2, R17.1
unnamed: C17.2, R15.2, U$13.2
unnamed: C13.2, U$8.1, U$13.1, U$18.2
unnamed: C14.2, C16.1, U$1.45 (SPK_N), U$8.4, U$14.1, U$17.2
unnamed: C15.1, U$1.44 (SPK_P), U$8.2, U$8.3, U$16.1
unnamed: C20.1, U$1.56 (ANT)
unnamed: C20.2, U$7.1
unnamed: R30.2, S2.1 (S), U$19.4 (RST)
unnamed: LED11.C, U$19.16 (GP0/SSPND)
unnamed: LED12.C, U$19.15 (GP1/USBCFG)
unnamed: LED11.A, R31.1
unnamed: LED12.A, R32.1
unnamed: R21.1, U$11.3 (D)
unnamed: R19.1, U1.8 (PA1)
unnamed: LED4.C, R23.2
unnamed: R23.1, U$12.3 (D)
unnamed: R20.1, U1.9 (PA0)
unnamed: LED13.C, R33.2
unnamed: LED14.C, R36.2
unnamed: R2.1, R13.1, U$9.1 (G)
unnamed: R4.1, R12.1, U$10.1 (G)
unnamed: R40.2, U2.8 (DIR4)
unnamed: R39.2, U2.7 (DIR3)
unnamed: R41.2, U2.9 (!OE)
unnamed: R11.1, R22.1, U$11.1 (G)
unnamed: R10.1, R24.1, U$12.1 (G)
POWER_IN: C1.1, C21.2, C22.2, C23.2, C24.2, C25.2, C28.1, LED1.A, LED2.A, LED3.A, LED4.A, U$1.51 (VCC), U$1.52 (VCC), U$1.53 (VCC), U$3.1 (IN), U$3.3 (EN), U$6.3, U$23.1 (IN), U$23.3 (EN)
POWER_ON: R18.1, R19.2, S6.3, S6.4 (P1), U$1.15 (PWR_ON)
RESETN: JP1.3, S3.3, S3.4 (P1), U1.14 (PC3)
RESET_N: R20.2, S1.1 (S), U$1.18 (RESET_N)
RTS_: R25.1, U$1.10 (RTS)
RX_: R28.1, U$1.13 (RXD)
RX_18: R27.2, U2.12 (B3)
RX_33: JP2.2, U1.2 (PA7), U2.5 (A3)
SCK: JP1.6, U1.16 (PC1)
TX_: R27.1, U$1.12 (TXD)
TX_18: R28.2, U2.11 (B4)
TX_33: JP2.3, U1.1 (PB0), U2.6 (A4)
USB_CTS: U1.5 (PA4), U$19.13 (CTS)
USB_DM: CR5.2 (22), U$5.P$2 (D-), U$19.18 (D-)
USB_DP: CR6.2 (22), U$5.P$3 (D+), U$19.19 (D+)
USB_RTS: U1.4 (PA5), U$19.11 (RTS)
VBAT: CN1.2 (1), U$6.2
VBAT_CHARGE: C33.1, U$4.3 (VBAT), U$6.1
VUSB: C4.1, C6.1, C34.1, R5.2, R7.1, R29.1, R30.1, R31.2, R32.2, U$4.4 (VIN), U$5.P$1 (VCC), U$19.1 (VDD), U$19.17 (VUSB)
V_BCKP: C26.1, R18.2, U$1.2 (V_BCKP)

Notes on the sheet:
Cell Module
USB Adapter
Battery Charger
Regulator
MCU
Debug Header
Voltage Translation
LED GPIOs



Board: 2 copper layers, 60.2 x 95.2 mm, 117 parts (14 on the bottom side), 87 nets.

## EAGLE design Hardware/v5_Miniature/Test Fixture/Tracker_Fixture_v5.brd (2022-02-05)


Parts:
J1, J2: MICRO_USB047590; MOLEX_USB_047590
J3, J4: TC2030-MCP
SV1: MA06-2
SV2: MA03-2
TP1, TP2, TP3, TP4, TP5, TP6, TP7, TP8, TP9, TP10, TP11, TP12, TP13, TP14, TP15, TP16, TP17, TP18, TP19, TP20, TP21, TP22, TP23, TP24, TP25, TP26, TP39, TP40: 0914-X-15-20-77-14-11-0; MILLMAX-0914-X
TP27, TP28, TP29, TP30, TP31, TP32, TP33, TP34, TP35, TP36, TP37, TP38: 5017; KEYSTONE-5017

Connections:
EINK_CS: SV1.3, TP16.1, TP29.P$1
EINK_MOSI: SV1.1, TP18.1, TP31.P$1
EINK_SCK: SV1.2, TP17.1, TP30.P$1
GND: J1.5 (GND), J2.5 (GND), J3.5 (ICSP_CLK/PGC), J4.5 (ICSP_CLK/PGC), SV2.2, SV2.4, SV2.6, TP2.1, TP3.1
GPS_RX: SV1.7, TP25.1, TP33.P$1
GPS_SCL: SV1.5, TP7.1, TP35.P$1
GPS_SDA: SV1.6, TP6.1, TP34.P$1
GPS_TX: SV1.8, TP24.1, TP32.P$1
ISP_RESET: J3.3 (VSS(GND)), TP21.1
ISP_SWCLK: J3.4 (ICSP_DAT/PGD), TP19.1
ISP_SWDIO: J3.2 (VDD), TP20.1
PACK+: SV2.1, SV2.3, SV2.5, TP1.1
SARA_D_N: J2.2 (D-), TP5.1
SARA_D_P: J2.3 (D+), TP4.1
SARA_RX: SV1.9, TP9.1, TP38.P$1
SARA_TX: SV1.10, TP8.1, TP37.P$1
SARA_USB_DET: J2.1 (VCC), TP39.1
SCL: SV1.11, TP22.1, TP27.P$1
SDA: SV1.12, TP23.1, TP28.P$1
ST_RESET: J4.3 (VSS(GND)), TP13.1
ST_SWCLK: J4.4 (ICSP_DAT/PGD), TP12.1
ST_SWDIO: J4.2 (VDD), TP14.1
ST_SWO: J4.6 (LVP), TP15.1
TIMEPULSE: SV1.4, TP26.1, TP36.P$1
USB_D_N: J1.2 (D-), TP10.1
USB_D_P: J1.3 (D+), TP11.1
VDDIO: J3.1 (VPP/MCLR), J4.1 (VPP/MCLR), TP40.1


Board: 2 copper layers, 62.2 x 50.8 mm, 47 parts (0 on the bottom side), 27 nets.

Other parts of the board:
U$1: PROFERO-LOGO-SMALL

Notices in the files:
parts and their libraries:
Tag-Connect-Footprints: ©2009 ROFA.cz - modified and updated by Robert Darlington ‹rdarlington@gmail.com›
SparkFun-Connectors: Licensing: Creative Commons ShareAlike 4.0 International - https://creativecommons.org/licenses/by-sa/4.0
